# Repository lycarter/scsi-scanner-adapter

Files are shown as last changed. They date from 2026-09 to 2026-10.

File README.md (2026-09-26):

# scsi-scanner-adapter

Bringing a Howtek Scanmaster D4000 drum scanner (1990s, SCSI-2) to modern computers
with custom hardware (USB-C ↔ SCSI) and open scanning software.

## Status

Phase 0: requirements and architecture decisions.

## Phases

| # | Folder | What |
|---|---|---|
| 1 | [`design_docs/1-bus-capture/`](design_docs/1-bus-capture/NOTES.md) | Logic analyzer, passive tap and capture tooling for watching the G4 ↔ scanner bus |
| 2 | [`design_docs/2-reverse-engineering/`](design_docs/2-reverse-engineering/NOTES.md) | Decode the command set and data flow (bus captures + firmware/software analysis) |
| 3 | [`design_docs/3-driver/`](design_docs/3-driver/NOTES.md) | USB-C ↔ SCSI initiator PCB that also works as a listen-only bus sniffer |
| 4 | [`design_docs/4-software/`](design_docs/4-software/NOTES.md) | Driver firmware and host scanning software |

Shared background: [`docs/scanner-facts.md`](docs/scanner-facts.md), [`docs/reference-inventory.md`](docs/reference-inventory.md), [`docs/decisions.md`](docs/decisions.md).

## Known-good baseline

A Power Mac G4 on Mac OS 9, running SilverFast, scans successfully with this scanner.

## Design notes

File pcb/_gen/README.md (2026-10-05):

# Generated schematic sheets

Some sheets are written by Python scripts here rather than drawn by hand, and each script is checked
against KiCad's own netlist. Sheets generated so far: `1-power`, `2-termpwr`, `3-scsi` (with the channel sheets
`scsi_line_bidir` and `scsi_line_in`), `4-rp2350`, `5-io`, `6-usb-hub`, `7-ft232h`.

```
python3 pcb/_gen/build.py            # regenerate, then ERC + netlist check
python3 pcb/_gen/build.py --check    # write nothing; report whether each sheet still matches its script
python3 pcb/_gen/build.py --force    # overwrite hand edits (they are lost)
```

## Footprints

Project footprints (library `scsi-adapter`, `pcb/scsi-adapter.pretty/`) are generated by `footprints.py`, one
function per footprint, with the datasheet land-pattern numbers written into it. Run
`python3 pcb/_gen/footprints.py`. So far: `Texas_RPW0010A_VQFN-HR-10_2x2mm_P0.45mm` (U101/U201),
`TerminalBlock_Kangnex_WJ500V-5.08-2P_1x02_P5.08mm_Horizontal` (J101),
`TE_AMPLIMITE-050_5787082-5_50pos_P1.27mm_Horizontal` (J302), `microSD_SHOUHAN_TF-PUSH_PushPush_CardDetect` (J501), `L_Abracon_AOTA-B201610_2.0x1.6mm_Polarized` (L401, Raspberry Pi's land), `C_0402_1005Metric_Wide` (C402/C403, Raspberry Pi's), `SW_DIP_SPSTx02_Slide_SHOUHAN_2.54-2P-TPGT_W8.8mm_P2.54mm` (SW301). Vendor 3D models live in `pcb/scsi-adapter.3dshapes/`, which is **git-ignored** (vendor copyright). On a fresh
clone, rebuild it from `reference/` with the commands in `docs/sources.md`. Without it KiCad just shows no 3D body.

## How it fits together

- `sheet_N_name.py`: one per sheet. `build(path)` places the parts, wires and notes, and returns the
  *intended* connections as `{(ref, pin): net}`.
- `schgen.py`: the drawing helpers (parts, stubs, power symbols, labels, boxes, notes).
- `netcheck.py`: exports KiCad's netlist and checks that every intended group of pins is exactly one
  net, with nothing extra. This is the real test: a stub that misses a pin, or a wire that touches
  the wrong one, shows up here.
- `semdiff.py`: compares two schematic files by content (parts, texts, wires, labels), ignoring
  UUIDs and KiCad's formatting.

## Editing a generated sheet

Either edit the script and run `build.py`, or edit in KiCad. If you edit in KiCad, `build.py` notices (the sheet
no longer matches the fingerprint in `fingerprints.json` from the last build), refuses to overwrite
it, and lists what differs. Copy those changes into the script (a note's exact
position doesn't matter; near the same spot is fine), then run it again. Running `--check` after an
edit tells you whether the file on disk still matches its script.

Once a script reproduces the sheet on disk exactly, `build.py` does not rewrite that sheet. It only
records the new fingerprint ("matches the script (hand edits folded in)"). KiCad's own file stays as
saved, with the symbol UUIDs the PCB links to, so this is safe to run with the schematic open. A sheet
is rewritten only when the script's output really differs from it.

**Do not let a rewrite happen once the PCB is linked to the sheet.** The scripts number UUIDs with a
counter, so adding or removing one item shifts the UUID of every later item in that sheet, and the PCB
finds each footprint's symbol by UUID. *Update PCB from Schematic* then adds duplicate footprints (this
happened on 2026-10-04). To add a part after layout has started: add it in KiCad and fold it into the
script, or add it to the script and insert only the new items into the saved sheet with fresh UUIDs, so
that `build.py` reports "matches the script" and writes nothing. Run `build.py --check` first; if it
says "script output differs" for a sheet, a plain run would rewrite that sheet.

Needs KiCad 9's `kicad-cli` (`KICAD_CLI` overrides the default macOS path) and the KiCad symbol
libraries (`KICAD_SYMBOL_DIR`).

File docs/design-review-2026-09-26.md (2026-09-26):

# Design review, 2026-09-26

A full design check of the project so far, focused on Phase 3: RP2350 limits, USB, SCSI,
the bootstrapping and programming path, and the numbers against the datasheets. Phases 1, 2
and 4 are covered where they affect the board.

**Triage:** open `docs/design-review.html` in Chrome or Edge and load this file. Each finding gets
*Approve fix*, *Ignore* or a comment, written back here as `- **Owner decision:**` and
`- **Owner comment:**` lines at the end of the finding.

**Ground rules (from the owner):**
- Main topology: **driver board + scanner only**. The G4 with its Adaptec card is on the chain
  only during Phase 1/2 captures, so three-device cases are secondary.
- Accepted decisions are re-opened **only for real errors**, not for preference or cost.
- Trivial doc errors (typos, arithmetic slips) are fixed in place and logged as `[fixed]`.
  Design changes are only logged, never applied.

**Severity:**
- **Blocker:** the board won't work, or something gets damaged.
- **High:** likely needs a respin or a bodge.
- **Med:** spec margin or bring-up risk.
- **Low:** doc issue or nice-to-have.
- **Info:** checked and OK (logged so the check isn't repeated).

There's no schematic yet. The review checks `design_docs/3-driver/NOTES.md`, `design_docs/3-driver/blocks/`,
`design_docs/3-driver/parts-list.md` and the other phase notes, against the datasheets in
`reference/datasheets/` and SCSI-2 rev 10L.

## Summary

Reviewed by one lead plus four parallel reviewers: SCSI front end, power, USB/bootstrap and RP2350/firmware. The raw log has 113 entries. **No Blockers.** One High, which is a single-part swap. Everything else is spec margin, schematic detail, firmware rules or docs. Duplicate entries from different reviewers are merged below; each `Rnnn` is a finding ID in the raw log.

### High

| # | Finding | Fix (suggested) | Log |
|---|---|---|---|
| H1 | **110 Ω terminator resistors (0402, 62.5 mW) run at 100–110 % of rating** on any asserted line; BSY stays asserted for a whole scan | 0603 100 mW, e.g. C2906985 | R006 |

### Med: hardware (settle before or during the schematic)

| # | Finding | Fix (suggested) | Log |
|---|---|---|---|
| M1 | **Bench present enables TERMPWR even when U1 is feeding the board from USB.** A USB port a little higher than the bench supply then carries TERMPWR, even a 500 mA Default port | Drive the enable node from LM66200 ST (open-drain, low while the bench supplies the board) instead of the bench-present FET | R068 |
| M2 | Bench eFuse **EN/UVLO pin passes its 6.5 V absolute maximum above 22.6 V in**; a 24 V adapter is a stated design case | Clamp EN with a ~5.1–5.6 V Zener | R057 |
| M3 | The bench **over-voltage trip (5.56–5.93 V) passes more than 5.5 V** to LM66200, the TPS73701s, FT232H VREGIN and TERMPWR (SCSI max 5.25 V) | Lower OVLO to ~5.5 V worst case, or accept it and document it | R061, R070 |
| M4 | **USB VBUS plug-in ringing can exceed the LM66200's 6 V absolute maximum**; the SMF6.0A only starts clamping at 6.67 V | Damp VBUS (a bulk electrolytic or RC snubber, within the 10 µF rule), or put an eFuse in the USB path | R074 |
| M5 | The TERMPWR eFuse **OVLO pin is driven to 3.3 V**; the recommended range is 0.5–1.5 V (absolute maximum 6.5 V, and TI's text allows GPIO drive) | Probably fine. Optionally clamp the node high level with a divider | R062 |
| M6 | **TERMPWR_OK can read high with TERMPWR absent**: the TCA9555 pull-up can be ~33 kΩ, not 100 kΩ | Lower the divider impedance, or add a pull-down on the node | R066 |
| M7 | **TERMPWR minimum on a 1.5 A USB port is ≈4.23–4.26 V** against SCSI-2's 4.25 V, and the eFuse's rising UVLO can reach 4.47 V | Measure at bring-up; lower the UVLO divider slightly; recommend the bench input for long scans | R069 |
| M8 | The **terminator rail (worst case 2.69 V) is below the SN74LVTH245A's 2.7 V minimum**, and its **output-high resistance is unspecified**, so the "100–132 Ω" and "≥ 2.5 V" claims aren't guaranteed | Centre the rail higher (~2.85 V still passes the 44.8 mA total rule); measure R_out at bring-up | R023, R025, R024 |
| M9 | **3.3 V rail margins**: VREG_AVDD/USB_OTP_VDD need ≥ 3.135 V; the CH334's low-voltage reset trips at up to 3.2 V; the rail's worst case is 3.16–3.44 V | Centre the rail at ~3.35–3.37 V (the CH334's maximum is 3.4 V); add 10 µF at the hub; measure under load | R078, R030 |
| M10 | **PSRAM CS1 pull-up (10 kΩ)** doesn't guarantee the APS6404L's VIH against the RP2350's reset pull-down (36 kΩ min) → 2.58 V vs 2.9 V | 3.3 kΩ (C25890, already on the BOM) | R079 |
| M11 | **FT232H power wiring**: VCCIO on the board 3.3 V rail while VREGIN = 5 V isn't an FTDI-documented configuration | Copy DS Fig. 6.2: VCCD (an output) feeds VCCIO/VPHY/VPLL/EEPROM | R016 |
| M12 | **FT232H support passives are missing**: REF 12 kΩ 1 %, TEST to GND, ferrites, decoupling, EEPROM resistors, RESET RC | Add them per DS Fig. 6.2 (values in the log) | R017 |
| M13 | FT232H outputs **can fight RP2350 outputs on the FT1248 lines** (blank EEPROM, wrong mode, a host bit-mode call) | 33–47 Ω series resistors; firmware checks the mode before driving | R021 |
| M14 | Bench-powered with the host off, the **CH334's D+ pull-up back-drives the cable** (no VBUS detect) | Hold the hub in reset when VBUS is absent (check that this removes the pull-up) | R032 |
| M15 | **Parts list isn't schematic-ready**: most support passives and rail capacitors are missing | Add a per-IC support-passives section | R003, R097 |

### Med: firmware and host (no hardware change)

| # | Finding | Log |
|---|---|---|
| F1 | **macOS: Apple's DriverKit FTDI driver claims 0403:6014**, so D2XX and libusb need root. Conflicts with R5 → owner decision (see Q1) | R052 |
| F2 | **Programming the FT232H EEPROM on macOS**: `ftdi_eeprom` can't set the FT1248 polarity, bit-order or flow-control bits and needs `eeprom_type=0x56` plus root. Suggest FT_PROG once on Windows, then `flash_raw` from the Mac | R044 |
| F3 | **PIO sketches**: `out pins, 9 [8]` won't assemble (max [7]); the setup time before ACK should be ≥ ~100 ns, not 55 ns; there's no phase-change check (a STATUS byte would be ACKed as data); release data in PIO after the last byte; REQ ringing can double-clock; ATN on the last MESSAGE OUT byte (put ATN on `out pins, 10`, since GPIO 27 sits next to DBP) | R007–R011, R100–R102 |
| F4 | **Hard real-time deadlines** (bus set 1.8 µs, bus clear or RST 800 ns, data release 400 ns) need SRAM-resident, top-priority code, ideally on a dedicated core | R014, R103 |
| F5 | **QMI sharing**: run from SRAM (`PICO_COPY_TO_RAM`), keep SCSI DMA in SRAM rings, never write flash during a bus session | R092 |
| F6 | **Sniffer**: can't follow 10 MB/s sync, produces 60–80 MB/s at the edge level, and its two FIFOs can desync → use Phase 1's protocol-level design for long captures | R012, R104 |
| F7 | **1-bit SDIO spill** is marginal at 25 MHz and can't write and drain at the same time; run it at 50 MHz and treat it as "extends the stall buffer" | R108 |

### Low (selection)

These are all in the raw log:
- **Connector:** IDC50 pin 25 / HD50 pin 13 must stay open; ground the RESERVED pins at the chain end (R002).
- **'245 terminator:** tie DIR and the A inputs explicitly (R039). Add a bleed load on the 2.80 V rail, ~1–3 mA (R042, R086).
- **Disabled terminator:** its bus-hold and ~9 pF load show up mid-chain only (R026, R027).
- **RP2350 caps:** the exposed pad is the only GND (R072); a second DVDD 4.7 µF is recommended (R081).
- **LDOs:** the 2.80 V divider impedance (R083); TPS73701 EN pins undefined (R084); LDO thermal tighter than stated (R085).
- **CC reference:** CJ431 is 2.500 V nominal and its margin shrinks to ~6–11 mV, still inside the window (R087). Keep capacitance off its cathode (R088).
- **CH334:** the RESET#/CDP pull-up may enable charging-port mode, so leave it floating (R031).
- **FIFO fallback:** pull SIWU# up (R022).
- **TERMPWR details:**
  - FLT goes low on reverse blocking; don't report that as a fault (R064).
  - Our sink current can exceed 1.0 mA (R065).
  - The TERMPWR_OK divider back-feeds into the unpowered 3.3 V rail (R067).
  - It can pulse on at power-up (R096).
- **Current limits:**
  - The bench eFuse's minimum limit can be exceeded when TERMPWR is at its limit (R095).
  - Power-budget rows are low: RP2350 core ~115 mA, microSD up to 200 mA (R093).
  - A 10 kΩ A-to-C cable reads as "3 A" (R090).
- **Firmware rules:**
  - Watchdog and fail-safe bus release (R004).
  - A "TERMPWR absent" rule (R049).
  - USB suspend current: document it as an accepted deviation (R005).
- **Phase 1:** the "≤ 3 m" claim and stubs from LA leads / Pico taps (R109, R110).
- **Doc slips:** listed at R051, R055 and R099. The trivial ones were fixed (R001, R056).

### Info (verified OK, don't recheck)

- **Pin map and PIO:** the RP2350B QFN-80 pin map, GPIO functions, PIO windows, and side-set/`wait` reach.
- **RP2350 errata:** the E9 mitigation (and E9 is fixed on A3/A4); the full errata sweep.
- **RP2350 support circuit:** core regulator, inductor, crystal, flash, BOOTSEL/RUN.
- **SCSI parts:** FDV301N V_OL, I_DSS, C_oss and C_rss; 74LVC1G17 thresholds at 3.3 V (≤ 1.90 / ≥ 0.93 V interpolated), I_OFF.
- **SCSI bus:** H5VUD5BB on the bus; parity, DB(P) and listen-only; edges and stubs.
- **eFuse settings:** both recompute correctly, apart from the Med items above.
- **Power ICs:** LM66200 ON/ST/soft start; TPS73701 feedback; CC front end and cable cases.
- **Supply ranges:** every 3.3 V part's V_DD maximum. The APS6404L is rated 2.7–3.6 V; LCSC's 2.7–3.3 V is wrong.
- **USB parts:** 93LC56B choice; ABM8 drive level; CH334 pinout and mode; RP2350 USB behind the hub.
- **FT232H:** the FT1248 ↔ FIFO rework map; it can't be bricked by bad EEPROM contents.
- **Bootstrap:** a blank board enumerates the hub, FT232H and RP2350 BOOTSEL with no firmware. UF2 family 0xE48BFF59.
- **Throughput:** the FT1248 4-bit master fits PIO1 at ~12 MB/s MCU-side. PIO, DMA and IRQ budgets fit.

### Bootstrapping verdict

Yes, everything can be programmed on a blank board.
1. On power-up the hub enumerates with no firmware.
2. The RP2350 comes up in ROM BOOTSEL (blank flash) through the hub, and takes UF2 or picotool. SWD via the TC2030 and J-Link is the fallback.
3. The FT232H enumerates with default descriptors and a blank EEPROM, and its EEPROM can be written over USB. Bad contents can't brick it.

The friction is on the host side, not the board: on macOS, Apple's FTDI driver (F1, F2) means root or a Windows machine for the first EEPROM write. On the board side, keep the RP2350 off the FT1248 lines until the FT232H is known to be in FT1248 mode (M13).

### Questions for the second review pass

1. **R5 / macOS (F1):** which path should the host tool use on macOS?
   - root;
   - Apple's `/dev/cu.usbserial` node as the data pipe (needs a bench test);
   - a custom PID (which loses the automatic Windows Update driver).

   Should R5 be reworded to "FTDI's own driver on Windows is OK"?
2. **RP2350 stepping:** which one does JLC fit (A2 vs A3/A4)? It decides whether E9, E10 (UF2 drag-and-drop after a partition table) and E14 apply. `picotool info -a` shows it at bring-up; asking JLC before the order is better.
3. **Sniffer scope:** must the on-board sniffer trace *sync* DATA phases, or is the logic analyzer the tool for those? This decides whether F6 is a firmware item or a non-goal.
4. **Bench OVLO (M3):** lower it so nothing sees more than 5.5 V (tighter margin to a 5.5 V bench setting), or keep 5.73 V and document "set the bench to 5.0–5.3 V"?
5. **Windows machine:** do you have one for FT_PROG (F2)? If not, we plan the macOS `ftdi_eeprom` route with a hand-built image.

### Pre-KiCad resolutions (2026-09-26, from the owner's triage)

The owner triaged every finding in `design-review.html`; the per-finding decisions are in the raw log.
The answers to the follow-up questions, and the resolutions that follow from the notes:

- **R068 (bench role):** the bench must *take over* when it's connected, not just add to USB. The
  LM66200 picks whichever input is higher, so it can't do that. **Replace U1 with a TI TPS2116DRLR
  (C3235557, SOT-583, the same package, extended, $0.40)** in priority mode:
  - VIN1 = bench eFuse output, VIN2 = USB VBUS, MODE tied to VIN1, PR1 divider from VIN1 set
    below the bench eFuse UVLO (datasheet SLVSFG1A §7.6 truth table: PR1 > VREF → VIN1, whatever VIN2 is).
  - The bench eFuse output is either 0 V or ≥ 4.05 V, so "bench present" = "bench in use", and the
    existing bench-present 2N7002 stays the right TERMPWR enable.
  - ST (open-drain, low when VIN1 isn't in use) → expander PWR_SRC.
  - Still one ideal-diode part type (the LM66200 leaves the BOM).
  - Abs max is still 6 V, so the approved R074 VBUS damping stays. There's no mux current limit;
    the bench eFuse limits the bench side.
  - Check at schematic time: the VREF/PR1 tolerance, and the output dip on switchover when the
    bench is removed (§7.5), against the +5V_SYS bulk capacitance.
- **R078 vs R030 (3.3 V setpoint):** keep **3.30 V (47 k / 27 k)**, plus a **DNP 0603 in parallel with
  R2** for rework trim. Raising it to 3.37 V would overshoot the CH334's 3.4 V maximum. Measure at bring-up.
- **R006 (terminator resistors):** each 110 Ω becomes **2 × 220 Ω 0402 in parallel (C25091, basic,
  62.5 mW)**. That's ≤ 35 mW (55 %) each, and it drops the extended 110 Ω part (one fewer loading fee).
- **R066 / R069 (TERMPWR sensing):** **GPIO 46 (ADC6) reads TERMPWR through a divider**. The digital
  TERMPWR_OK input (expander P05) and its 22 k/33 k divider are dropped, which also removes the
  R067 back-feed. GPIO 46 loses its two DNP links: expander INT (firmware polls) and SIWU# in the
  FIFO fallback (SIWU# is tied high instead, R022). Keep TERMPWR UVLO as it is; firmware warns
  from the ADC reading.
- **R111 (bench test):** an FT232H breakout + Pico 2 W test of FT1248 and the macOS
  `/dev/cu.usbserial` path runs **in parallel with the KiCad schematic, and must finish before
  the JLC order**.
- **R034 / R111:** plan for **A4 silicon**, and stay safe on A2 (keep the E9 pull-downs and the
  E14 notes).
- **R013:** the protocol-mode sniffer must also trace DATA phases (per-handshake records).
- **Still undecided, no schematic impact:** R102, R105, R113 (firmware notes), R109, R110 (Phase 1 docs).

**Applied (2026-09-26).** All approved fixes are now in `design_docs/3-driver/NOTES.md` (sections updated in
place, a new "Power mux" section, and "Firmware rules from the design review" after the PIO
sketch), `design_docs/3-driver/parts-list.md` (rewritten), the block pages and diagram sources (rebuilt),
`design_docs/3-driver/USAGE.md` (power, first programming, bring-up checks), `docs/decisions.md` and
`design_docs/4-software/NOTES.md`. Values chosen while applying them (all from JLC's no-fee range):
bench string 510 k / (39 k + 3.9 k) / (150 k + 10 k), OVLO 5.35 V (5.14–5.59 V); terminator
divider (39 k + 5.6 k) / 33 k = 2.831 V; OVLO divider 56 k / 47 k; LDO EN 100 k / 75 k; PR1
100 k / 39 k; ADC divider 100 k / 100 k; CJ431 bias 470 Ω (430 Ω isn't no-fee); bench ILIM 1.5 k
(2.22 A).

**Questions for the second review pass (raised while applying the fixes):**
1. **R059 vs R061 conflict.** Scaling the bench eFuse string to ≥ 1.5 MΩ (< 10 µA reverse
   current, as approved) makes the pins' ±0.1 µA leakage move the OVLO trip by ±0.16 V, so
   the trip spreads to ~5.0–5.7 V, which breaks R061. I kept 510 k (~28 µA at −15 V; meets
   TI's ≥ 350 kΩ footnote, and the new EN Zener takes most of it forward-biased) and
   prioritised over-voltage accuracy. OK, or do you want a different trade?
   **Owner (2026-09-26): OK.**
2. **EN Zener leakage.** The BZT52C5V6's datasheet only bounds leakage at 2 V (≤ 1 µA). At our
   1.42 V it's typically nA, but 1 µA through 510 kΩ would raise UVLO by up to 0.5 V. Bring-up
   measures UVLO; is a datasheet-guaranteed clamp worth a different part?
   **Owner: no; far from anything we care about. If it's a problem, bodge in a different part.**
3. **Power ceiling.** With the corrected RP2350 (115 mA) and SD (200 mA, unverified) maxima, the
   every-maximum ceiling is 1.55 A against a 1.5 A USB port (realistic worst ~1.3 A), and a
   TERMPWR overload plus maximum logic (~2.05 A) can touch the bench eFuse's minimum limit
   (2.0 A). Both are accepted in NOTES; flag if you disagree.
   **Owner: accepted.**

## Raw log (in the order found)

Format: `### Rnnn [Severity] Area: title`, then evidence (with citations), impact, and a
suggested fix.

### R001 [Low] Docs: stale values fixed in place `[fixed]`
- **Evidence:** leftovers from superseded decisions:
  - NOTES R2a still said "resettable fuse".
  - The FDV301N circuit sketch showed a 10 kΩ gate pull-down; it's 4.7 kΩ since 2026-09-25 (E9).
  - The terminator `/OE` sketch and the TERM_EN limitation said 2.85 V; the rail is 2.80 V.
  - Open question 4 still named LM66200 U2 as the TERMPWR part.
  - The power budget still had a "TERMPWR polyfuse" requirement.
  - The FT232H section said AN_167 was "not yet downloaded".
  - `blocks/1-power.md` said "2.85 V regulator" and listed the TERM_EN default and resistor values as open. Both are decided.
  - `USAGE.md` called the expander "optional", but it's fitted as standard.
- **Fix:** edited in place (NOTES, `blocks/1-power.md`, `USAGE.md`). Historical log lines and superseded rationale sections were left as history.
- **Confidence:** high.
- **Owner decision:** approved (2026-09-26)

### R002 [Low] SCSI connector: RESERVED and OPEN pins need explicit handling in the schematic
- **Evidence:** SCSI-2 rev 10L Table 2 (SE, A cable):
  - IDC50 (set 1) pin 25 / HD50 (set 2) pin 13 is **OPEN**, not ground.
  - Pins 24 and 28 (HD50 37 and 39) are **RESERVED**.
  - Several even pins are **GROUND**, not signals: 20, 22, 30, 34 (HD50 35, 36, 40, 42).
  - §5.4.4: RESERVED lines "shall be connected to ground in the bus terminator assemblies or in the end devices", and "should be open in the other SCSI devices".
- **Impact:** NOTES describes the pinout as "odd pins ground, even pins signal", which is almost right. If pin 25 is grounded with the rest of the odd pins, a reversed cable (possible on the HD50 side only through a bad cable) shorts TERMPWR to ground. The eFuse survives that, but the bus is dead. The RESERVED lines should be grounded when our board is an end device, which is the main topology.
- **Fix:** in the schematic, leave IDC50 pin 25 and HD50 pin 13 unconnected. Tie the RESERVED pins to GND through a 0 Ω link each (fit for end-of-chain, remove if the board ever sits mid-chain), or simply ground them. Wire both connectors from Table 2 by signal name, as NOTES already says.
- **Confidence:** high (read directly from the standard).
- **Owner decision:** approved (2026-09-26)

### R003 [Med] Parts list: not yet "schematic-ready"; many support passives are missing
- **Evidence:** `parts-list.md` calls itself "schematic-ready", but it has no rows for:
  - FT232H: REF resistor, per-pin decoupling, any VPHY/VPLL filtering, EEPROM pull-ups.
  - CH334P: VDD33/V5 decoupling.
  - TPS73701 ×2: input and output capacitors. The datasheet has minimum C_OUT and ESR guidance.
  - TPS259470A ×2: IN/OUT capacitors.
  - Bulk capacitance on +5V_SYS, TERMPWR and the 2.80 V rail.
  - Decoupling for the TCA9555, LM393, 3 × LVTH245 and W25Q128 (the MCU table has "+ flash"; check it's counted once).
  - microSD: decoupling and bulk (card insertion inrush).
  - USB-C shell/shield connection.
  - Test points.
  Some of these are covered in the agents' sections below (FT232H, LDOs).
- **Impact:** the schematic step turns into more part selection. A missed REF resistor or LDO output cap stops the board working.
- **Fix:** at schematic time, add a "support passives" section per IC, checked against each datasheet's typical application. Prefer basic 100 nF/1 µF/4.7 µF/10 µF parts that are already on the list.
- **Confidence:** high that the rows are missing; the exact values are in the per-area findings.
- **Owner decision:** approved (2026-09-26)

### R004 [Low] Error states: firmware must fail safe on the bus (watchdog)
- **Evidence:** ATN, BSY and SEL are driven by the CPU (SIO), and data/ACK by PIO. A firmware hang (hard fault, deadlock, a stall on flash erase) with BSY or data gates asserted holds the SCSI bus busy until the board resets. The scanner would then time out or wait for ever. After a watchdog reset or a RUN reset, all pads return to their reset state (pull-down, isolated), and the 4.7 kΩ gate pull-downs release every line.
- **Impact:** a hung board wedges the scanner mid-command, which may need a scanner power-cycle.
- **Fix (firmware):** enable the RP2350 watchdog in the SCSI engine, and have the host protocol expose a "bus reset" command (assert RST ≥ 25 µs, SCSI-2 reset hold time) for recovery. Hard-fault handler: release all 14 gates first.
- **Confidence:** high (design logic).
- **Owner decision:** approved (2026-09-26)

### R005 [Low] Error states: USB suspend current
- **Evidence:** USB 2.0 §7.2.3 limits a suspended device to 2.5 mA. This board draws ~0.2 A of logic current (NOTES power budget) and keeps TERMPWR up in suspend. This is the same class of deviation as the accepted "100 mA before configuration" one.
- **Impact:** in practice, hosts don't police it. A laptop going to sleep with the board attached keeps powering it (or cuts VBUS). The scanner session is lost either way.
- **Fix:** document it as an accepted deviation next to the 100 mA one. Optionally, firmware can gate LEDs and the SD card in suspend. No hardware change.
- **Confidence:** high on the rule; the impact is benign.
- **Owner decision:** approved (2026-09-26)

### R006 [High] SCSI: 110 Ω terminator resistors in 0402 run at or above their 62.5 mW rating
- **Evidence:** parts-list row "18 × 110 Ω 1 % 0402 (FOJAN)", C2909312 = FRC0402F1100TS, **62.5 mW** (pcbparts/JLC record). An asserted line puts (V_term − V_OL) across the resistor: nominal (2.81 − 0.18 V [FDV301N 3.8 Ω typ × 48 mA]) → 2.63²/110 = **63 mW**; worst (2.93 V LDO max − 0.18) → 2.75²/108.9 = **69 mW** (110 %). BSY is held asserted for a whole connection (a scan lasts minutes), RST for ≥ 25 µs, and a data line can sit asserted indefinitely between bytes. Thick-film 0402 ratings are also derated above ~70 °C.
- **Impact:** resistors run at 100–110 % of rating continuously on the busy lines; drift/early failure, and the resistor tolerance that the 22.4 mA budget depends on is no longer guaranteed.
- **Fix:** use 0603 (100 mW): e.g. FOJAN FRC0603F1100TS **C2906985** (143k stock, extended, same loading-fee count as the 0402) or UNI-ROYAL C22781. Update parts-list and NOTES.
- **Confidence:** high (arithmetic + part record). Real V_OL varies, but the nominal case alone is at the rating.
- **Owner comment:** Rather than use an extended part, use basic parts in parallel to spread the power around and keep each individual component under its limits.

### R007 [Med] SCSI: PIO data_out `out pins, 9 [8]` does not assemble with `.side_set 1 opt`
- **Evidence:** the PIO delay/side-set field is 5 bits. `.side_set 1 opt` uses 1 side-set bit + 1 enable bit, leaving 3 bits of delay, so the maximum is **[7]** (RP2350 datasheet §11.4 "Delay/side-set" field; same as RP2040). NOTES "PIO0 sketch" uses `[8]`.
- **Impact:** pioasm error. If "fixed" by just trimming to [7], the data→ACK setup drops to 8 cycles = 53 ns at 150 MHz, under the 55 ns (deskew 45 + cable skew 10) target (see next finding).
- **Fix:** either use non-optional `.side_set 1` (4 delay bits, max [15]) and put `side 0/1` on every instruction, or add a `nop [n]`, or run the SM at a clock divider. Choose the delay after reading the rising-edge finding below.
- **Confidence:** high.
- **Owner comment:** approved. I think the `nop [n]` makes the most sense to me, but we can figure it out in firmware later.

### R008 [Med] SCSI: data_out deskew margin ignores slow release edges and FET turn-off delay; make it ≥ ~100 ns
- **Evidence:** SCSI-2 Table 7 (§5.7): **deskew delay = 45 ns** (not 55 ns: 55 ns is deskew + cable skew 10 ns). §6.1.5.1 async DATA OUT: drive DB, wait ≥ deskew + cable skew (55 ns), then assert ACK, measured at our connector (§5.7). The sketch gives 9 cycles = 60 ns from `out` to the ACK side-set, all of it inside the chip. On the wire, ACK assertion is a FET **turn-on** (t_d(on) typ 3.2 ns, t_r 6 ns; FDV301N DS switching table, at 4.5 V / 50 Ω), while a data bit going 1→0 is a FET **turn-off**: the gate (≈15 pF C_iss at low V_DS, Fig. 8) must discharge from ~3.2 V through 100 Ω + pad (~150 Ω) past the Miller plateau (≈2.1 V, Fig. 7; Q_gd 0.07 nC ≈ 5 ns at ~14 mA), then the line rises through the terminators and the cable (incident step to ~2.4–2.6 V at our end, plus lumped C ≈ 18 pF × ~50 Ω). Estimate ≈ 15–25 ns for a released bit vs ≈ 5–10 ns for ACK: ~10–15 ns of the 60 ns is eaten, leaving ~45–50 ns (< 55 ns). Unverified estimate; no bench data.
- **Impact:** marginal setup on the target side during DATA OUT / COMMAND / MESSAGE OUT; a WD33C93A usually samples later, so it will probably work, but it isn't compliant by design.
- **Fix:** delay ≥ 15 cycles (100 ns) between `out` and the ACK assertion. Async throughput cost is negligible (the scanner is the bottleneck). Verify on the scope: DBx release crossing 2.0 V vs ACK crossing 0.8 V at the connector.
- **Confidence:** med (timing estimate from typical figures).
- **Owner decision:** approved (2026-09-26)

### R009 [Med] SCSI: data_out leaves the last byte on the bus; release it in PIO, not firmware (400 ns data release delay)
- **Evidence:** SCSI-2 §6.1.10(b): when the target turns the bus around (I/O false→true, e.g. COMMAND → DATA IN/STATUS), "the initiator shall release the DATA BUS no later than a data release delay [400 ns, Table 7] after the transition of the I/O signal to true." The data_out sketch loops back to `pull block side 0`, so after the last byte DB0–7/P stay driven until firmware notices. NOTES says "Firmware must release all 9 data gates within the 400 ns". A Cortex-M33 IRQ (12-cycle entry ≈ 80 ns) can do it only if the ISR and its data are in SRAM, nothing higher-priority is running, and no XIP cache miss happens (a miss on QSPI flash/PSRAM costs ~0.5–1 µs).
- **Impact:** a bus fight with the target's first DATA IN / STATUS byte (target starts driving ≥ 800 ns after I/O; our open-drain drivers pull its 1-bits low → wrong status/data/parity errors). Open-drain means no damage, only corruption.
- **Fix:** §6.1.5.1 allows the initiator to "change or release the DB signals" once REQ is false. Add `mov pins, null` (release all 9) with ACK negation after `wait 0 pin 16`, so the bus is always released between bytes. Costs one instruction; removes the firmware deadline completely.
- **Confidence:** high on the rule; med on how hard the firmware deadline would be.
- **Owner decision:** approved (2026-09-26)

### R010 [Med] SCSI: last MESSAGE OUT byte: ATN (CPU-owned) can't be negated in the REQ-true/ACK-false window
- **Evidence:** SCSI-2 §6.2.1: the initiator "shall not negate the ATN signal while the ACK signal is asserted during a MESSAGE OUT phase. Normally, the initiator negates the ATN signal while the REQ signal is true and the ACK signal is false during the last REQ/ACK handshake." With the data_out SM, that window is only the ~60–100 ns between REQ detection and ACK assertion. NOTES "Who drives what" gives ATN to the CPU (SIO).
- **Impact:** firmware can't hit the window; negating ATN earlier (before the last REQ) is allowed by the letter but some targets then leave MESSAGE OUT early (vendor behaviour, the WD33C93A's is unknown); negating later (after ACK negated) is legal only if ACK is false, but then the target may request another message byte. Multi-byte messages (IDENTIFY + SDTR/EXTENDED, ABORT sequences) are where this bites.
- **Fix (firmware/PIO only, no hardware change):** ATN is GPIO 27, right after DBP (GPIO 26), so `OUT_BASE = 18`, `out pins, 10` can carry ATN as bit 9 of each FIFO word: firmware queues the last message byte with ATN = 0 and PIO drops it at the right moment. That means ATN's funcsel is PIO0 during MESSAGE OUT (or always). Alternatively do MESSAGE OUT byte-by-byte from the CPU (slow but only a few bytes).
- **Confidence:** high on the rule; the ATN bit-9 trick relies on the accepted pin map (verified: outputs 18–26 data, 27 ATN).
- **Owner decision:** approved (2026-09-26)

### R011 [Med] SCSI: data_in / data_out can double-clock on REQ ringing; add a minimum ACK-assert time before `wait 0 pin 16`
- **Evidence:** data_in: `in pins, 9 side 1` then immediately `wait 0 pin 16`. data_out: `wait 0 pin 16 side 1` right after asserting ACK. The PIO input path has a 2-flop synchronizer (≈13 ns at 150 MHz). REQ's assertion is a fast falling edge from the target's open-collector/three-state driver into a ribbon; ringback above the receiver's VT+ (≤ ~1.9 V, 74LVC1G17 Table 8, interpolated) for even one sample is enough to satisfy `wait 0` and release ACK, and the next `wait 1` then re-samples the same byte. The 1G17 hysteresis (≥ 0.31 V at 3.0 V, 0.25 V at 125 °C; Table 8) helps but doesn't bound ringing amplitude. This is the classic SCSI "double REQ" failure.
- **Impact:** duplicated or dropped bytes in DATA IN, silently corrupt scan data (no parity error, because the byte itself is valid).
- **Fix:** hold ACK asserted for a minimum time (e.g. `[7]`/`nop [n]` ≈ 50–100 ns) before looking for REQ negation, and/or require REQ negated for 2 consecutive samples (`wait 0 pin 16` followed by `jmp pin` re-check). Costs 1–2 slots, negligible throughput. Also scope REQ at the connector at bring-up.
- **Confidence:** med (depends on real ringing; cheap to guard).
- **Owner decision:** approved (2026-09-26)

### R012 [Med] SCSI: the sniff loop can't follow 10 MB/s fast-sync (and is marginal at 5 MB/s)
- **Evidence:** sniff = 3-instruction poll (20 ns at 150 MHz) + 4-instruction emit (mov y / mov isr / push / irq) → after each change the SM is blind for ≈ 7 cycles ≈ **47 ns**. SCSI-2 §5.8 / Table 7 fast sync: transfer period ≥ 100 ns, fast assertion/negation ≥ 30 ns, fast hold 10 ns, fast deskew 20 ns. So in each 100 ns period there are ≥ 3 distinct bus states ~10–30 ns apart (data change, REQ assert, REQ negate; plus ACK pulses offset by up to the REQ/ACK offset). Edges closer than ~47 ns after an event are merged or missed, and any state shorter than 20 ns can be missed outright. At 5 MB/s sync (200 ns period, 90 ns assertion/negation) it mostly works but data changes within 45 ns of REQ (hold time 45 ns) can still merge. Also: the two SMs (sniff + stamp) push to separate FIFOs with `push noblock`; if one FIFO overflows and the other doesn't, samples and stamps silently desynchronize. scanner-facts: the D4000's WD33C93A supports sync, rate unknown; the sibling 7500 uses up to 10 MHz.
- **Impact:** listen-only captures of the G4/Adaptec session will be wrong exactly in the DATA IN phase, if it negotiates fast sync.
- **Fix:** keep the Digital Discovery as the reference for sync phases; or make the sniffer loop 2 instructions with the timestamp embedded (e.g. count loop iterations in the same SM and push `{state, delta}` together, one FIFO, one DMA); or detect SDTR in the capture and flag data phases as "sync, not traced". Log the negotiated SDTR from the MESSAGE phases, which the sniffer does catch (async).
- **Confidence:** high on the arithmetic; whether it matters depends on what the Adaptec negotiates (Phase 1 will show).
- **Owner decision:** approved (2026-09-26)

### R013 [Question] SCSI: is the on-board sniffer required to trace sync DATA phases, or is the LA the tool for that?
- **Evidence:** see previous finding. R4 (listen-only) doesn't say which transfer modes it must cover.
- **Impact:** decides whether the sniff program needs redesign now or can stay "async only".
- **Fix:** owner to decide; I'd write "async + messages; sync data via the LA" into R4.
- **Confidence:** —
- **Owner decision:** approved (2026-09-26)
- **Owner comment:** in protocol mode it should also trace DATA

### R014 [Med] SCSI: CPU-side hard deadlines (bus set 1.8 µs, bus clear 800 ns, RST response 800 ns) need SRAM-resident, IRQ-masked code; write it down as a firmware rule
- **Evidence (SCSI-2 Table 7, §5.7):** arbitration delay ≥ 2.4 µs; bus free delay ≥ 800 ns; **bus set delay ≤ 1.8 µs** (assert BSY + ID after detecting BUS FREE); bus settle 400 ns (BUS FREE = BSY and SEL false for ≥ 400 ns, §6.1.1); **bus clear delay ≤ 800 ns** after BUS FREE detected / SEL seen during arbitration / RST true (and ≤ 1200 ns from BSY+SEL false, §5.7.3); data release 400 ns; reset hold ≥ 25 µs; selection abort ≤ 200 µs; selection time-out 250 ms (recommended); deskew 45 ns; cable skew 10 ns; hold 45 ns; assertion/negation (sync) ≥ 90 ns. So arbitration has a window of [800 ns, 1.8 µs] after BUS FREE detection, and the losing/reset paths have an 800 ns ceiling. BSY, SEL, ATN, RST are on SIO (CPU).
- **Impact:** a flash XIP cache miss (QSPI at ~≤ 75 MHz: tens of cycles per line, ~0.5–1 µs worst with PSRAM contention on the same QMI) or a USB/FT1248/DMA IRQ preempting the arbitration loop can blow the 1.8 µs / 800 ns limits. In the main topology (only us + scanner) arbitration loss only happens if the D4000 reselects (it disconnects? unknown); RST is only asserted by us. In the G4 capture topology we're listen-only. So the practical risk is low, but the requirement should be explicit.
- **Fix (firmware rule, NOTES):** arbitration/selection/bus-free/RST handlers `__not_in_flash` (SRAM), run with interrupts masked (or at the highest NVIC priority on the core that owns SCSI, with USB on the other core), no PSRAM access inside. For RST-true and SEL-during-arbitration, consider a small PIO watcher: `wait 1 pin RST` → `irq` so the CPU is told within ~13 ns, and let the data_out SM release its own pins (`mov pins, null`) on that IRQ. Also filter RST glitches per §6.2.2 NOTE 30 (e.g. ≥ 2 samples).
- **Confidence:** high on the numbers; latency figures for XIP misses are typical, not measured.
- **Owner decision:** approved (2026-09-26)

### R015 [Info] SCSI: PIO data_in handshake order and REQ index checked
- **Evidence:** `wait 1 pin 16` (REQ, IN_BASE 0, GPIO 16 per the pin map) → `in pins, 9` (DB0–7, DBP on GPIO 0–8) with ACK asserted on the same cycle → `wait 0 pin 16` → ACK negated at the top of the loop. Matches §6.1.5.1 (read after REQ true, then ACK; negate ACK after REQ false). Target provides deskew before REQ, so sampling ~13 ns (sync) + ≤ 5.5 ns receiver skew (1G17 tpd 0.7–5.5 ns, Table 9) after REQ is fine. INOVER-invert gives 1 = asserted for both data and REQ. Side-set ACK = GPIO 29 is inside PIO0's window. `.side_set 1 opt` delay limit (≤ 7) is only an issue in data_out.
- **Confidence:** high.

### R016 [Med] USB: FT232H VCCIO on the board 3.3 V rail while VREGIN = 5 V is not an FTDI-documented configuration; follow the datasheet (VCCD feeds VCCIO/VPHY/VPLL/EEPROM)
- **Evidence:** DS_FT232H v2.0 Table 3.1 and §6.1/§6.2 (pp. 10, 43–44): with VREGIN = 5 V, pin 39 **VCCD becomes an output** and "supplies 3.3V to the VCCIOs, VPLL and VPHY". Both 5 V examples (Fig. 6.1 bus-powered, Fig. 6.2 self-powered) tie VCCIO (12, 24, 46), VPHY (3) and VPLL (8) to the VCCD net, and power the 93LC56B from VCCIO. §7.1 (p. 47): the EEPROM must be "powered from the same net as the core supply". Only Fig. 6.3 (VREGIN = 3.3 V) feeds VCCIO from an external 3.3 V LDO, and then VCCD is an *input*. NOTES "Supply choices" says "VCCIO stays on the 3.3 V rail … Check the VPHY/VPLL wiring … at schematic time."
- **Impact:** the planned mix (VREGIN = 5 V, VCCIO from the board LDO) isn't shown anywhere by FTDI. The real danger is at schematic time: if VCCD (an LDO *output* in this mode) gets tied to the board 3.3 V net, two regulators fight. If VCCIO is on the board rail but VPHY/VPLL/EEPROM on VCCD, the I/O ring and the core-side 3.3 V come from different sources with unspecified sequencing.
- **Fix (suggestion):** copy Fig. 6.2 exactly: VREGIN = +5V_SYS (4.7 µF + 0.1 µF); VCCD = local "FT_3V3" net (4.7 µF + 0.1 µF), which feeds VCCIO ×3 (0.1 µF each), VPHY and VPLL each through a 600 Ω@100 MHz / 0.5 A ferrite + 0.1 µF (4.7 µF pads DNP), and the 93LC56B VCC. **Never connect VCCD to the board 3.3 V.** The FT232H's I/O is then at its own 3.3 V, which talks to the RP2350's 3.3 V fine (same 5 V source, so no sequencing problem; FT232H inputs are 5 V tolerant). The FT232H's ~70 mA then comes off 5 V instead of the board LDO, a slight power-budget improvement.
- **Confidence:** high on what the datasheet shows; medium that the external-VCCIO mix would actually misbehave (not stated as forbidden, just never shown).
- **Owner decision:** approved (2026-09-26)

### R017 [Med] USB: FT232H support passives (values to add to the parts list, per DS Fig. 6.2)
- **Evidence:** DS_FT232H v2.0 Table 3.2 (p. 10): **REF = 12 kΩ 1 % to GND** ("Current reference"), **TEST (pin 42) must be connected to GND**. Fig. 6.2 (p. 44): RESET# = 10 kΩ to 3.3 V + **10 nF to GND**; VCCA (37) and VCORE (38) = 0.1 µF each, "Should not be used" (DS Table 3.1); crystal caps; EEPROM: DO → **2.2 kΩ** (text) / 2 kΩ (figure) → DI/EEDATA, **10 kΩ pull-up on DO** to VCCIO (Table 3.3 "for correct operation"); CS/CLK pull-ups are N.F. in the figure. ACBUS7/PWRSAV# (pin 31) left open is fine as long as "Suspend on ACBus7 Low" stays disabled (its default is TriSt-PD, so enabling that option with the pin open would hold the chip in suspend; DS pp. 10, 48). None of these rows are in `parts-list.md` §4 (the existing [Med] "Parts list" finding lists them generically).
- **Impact:** a missing REF resistor or TEST left floating gives a dead or flaky HS PHY.
- **Fix:** add: 1 × 12 kΩ 1 % 0402 (JLC basic C25752, unverified C-number), 2 × ferrite 600 Ω/0.5 A 0603, 2 × 4.7 µF (VREGIN, VCCD) + 2 DNP pads, ~8 × 100 nF, 1 × 10 nF (RESET#), 1 × 2.2 kΩ, 1 × 10 kΩ. Keep "Suspend on ACBus7 Low" off in the EEPROM.
- **Confidence:** high (datasheet values).
- **Owner decision:** approved (2026-09-26)

### R018 [Info] USB: 93LC56BT-I/OT (C190271) is the right EEPROM
- **Evidence:** DS_FT232H §7.1 (p. 47): "The EEPROM must be 16 bits wide (93LC56B)". 93LC56B.pdf p. 1: "128 x 16-bit Organization 'B' Version (no ORG)"; SOT-23-6 ("OT") exists for A/B only, ORG is NC. JLC: C190271 = 93LC56BT-I/OT, SOT-23-6, 2.5–5.5 V, 11,203 in stock (pcbparts, 2026-09-26). FTDI's own Fig. 6.2 uses "93LC56BT-I/OT". Pinout (SOT-23-6): 1 DO, 2 VSS, 3 DI, 4 CLK, 5 CS, 6 VCC (matches the FTDI figure).
- **Confidence:** high.

### R019 [Info] USB: ABM8-272-T3 on the FT232H and CH334 oscillators: drive level is inside the crystal's 200 µW
- **Evidence:** ABM8-272-T3.pdf p. 1: CL 10 pF, ESR ≤ 50 Ω, C0 ≤ 3 pF, drive level 10–200 µW. Worst case with a full 3.3 V swing on the crystal: I_rms ≈ 2π·12 MHz·(10+3) pF·1.17 V ≈ 1.1 mA, P = I²·ESR ≈ 65 µW at 50 Ω. So even without a series resistor (FTDI's Fig. 6.4 has none) it stays under 200 µW. FT232H: 2 × 15 pF gives ≈ 7.5 + ~3 pF stray ≈ 10 pF, matching CL; FTDI's 27 pF is only an example (§6.3). The ±30 ppm in DS Table 6.1 is for an external oscillator input; USB HS allows ±500 ppm. The CH334 English reference schematic (V2.5 §6.1, p. 27) shows the crystal with no load caps, consistent with "DNP" pads.
- **Confidence:** medium-high (the estimate is an upper bound; neither chip specifies its oscillator gain).
  (Checked afterwards: C25752 = UNI-ROYAL 12 kΩ ±1 % 0402, JLC **basic**, 1.17 M stock, pcbparts 2026-09-26.)

### R020 [Info] USB: FT1248 ↔ 245 FIFO pin mapping and directions in `5-rp2350-pinout.md` are correct
- **Evidence:** DS_FT232H Table 3.13 (p. 17): MIOSIO0–7 = pins 13–20 (I/O), SCLK = 21 (in), SS_n = 25 (in), MISO = 26 (out). Table 3.8 (pp. 14–15): D0–7 = 13–20, RXF# = 21 (out), TXE# = 25 (out), RD# = 26 (in), WR# = 27 (in), SIWU# = 28 (in). So after the swap GPIO 41 and 42 turn from outputs into inputs and GPIO 43 from input into output, exactly as the page says. AN_167 §2.2 (p. 3): "Each pin of the FT232H has an internal pull up … no external pullup or down is required"; §2.1: "Unused MIOSIO lines may be left unterminated", so MIOSIO4–7 on DNP stubs are fine for 4-bit bus-width decoding (DS §4.6.1).
- AN_167 facts for the firmware: SCLK ≤ 30 MHz (§1, §2.2); only **CPHA = 1** is supported, CPOL selectable in EEPROM (§8, Table 2); bus width is chosen **per transaction by the command phase** (low on MIOSIO[3:2] = 4-bit; §4, Fig. 4.1), not by the EEPROM; commands 0x0 write, 0x1 read, 0x2/0x3 modem status, 0x4 write-buffer flush (§6, Table 1); per byte, MISO = ACK/NAK, and on NAK the master must end the transfer by raising SS_n and retry later (§5.5); with SS_n high the FT232H **drives** MIOSIO0 (= TXE#) and MISO (= RXF#) unless "no flow control during SS_n inactive" is set in the EEPROM (§3, §5.6). The master must release MIOSIO before raising SS_n after a write (§5.1). Note AN_167 §5.3 says the 4-bit data phase "requires 3 clock cycles", but Fig. 5.8/5.9 show 2 per byte; the NOTES' 15 MB/s at 30 MHz assumes 2.
- **Confidence:** high.

### R021 [Med] USB: FT232H outputs can fight RP2350 outputs on the FT1248 lines (blank EEPROM, wrong mode, or a host bit-mode call)
- **Evidence:** blank/absent EEPROM = UART mode (DS §7.1, p. 47). In UART mode ADBUS0 (pin 13 = MIOSIO0 = GPIO 32) is TXD **output**, ADBUS2 (pin 15 = GPIO 34) is RTS# **output**, ADBUS4 (pin 17) DTR# output (DS Table 3.4, p. 11); ACBUS0–2 (SCLK/SS_n/MISO pins) default to TriSt-PU inputs (Table 7.1). In FT1248 mode the FT232H also drives MIOSIO0 whenever SS_n is high (AN_167 §3). Any host program can also switch ADBUS to outputs at any time with FT_SetBitMode (MPSSE/bit-bang). GPIO 32/34 are driven by the RP2350 during command/write phases. There are no series resistors on these nets.
- **Impact:** push-pull contention (tens of mA per pin) at first power-up with the blank EEPROM if firmware starts polling the FT1248 link, during bring-up with a mis-programmed EEPROM (UART or FIFO while firmware speaks FT1248: in FIFO mode GPIO 41/42 would drive RXF#/TXE#), or after the fallback rework. Unlikely to destroy either chip quickly, but it can latch confusing states and it stresses both.
- **Fix (suggestions):** (1) 33–47 Ω series resistors on the 7 FT1248 nets at the RP2350 end (also damps ringing at 25 MHz; with the FIFO fallback they stay useful); (2) firmware: only drive MIOSIO after checking the FT232H is in FT1248 mode (e.g. MISO/MIOSIO0 behave as RXF#/TXE# while SS_n is high, or the host confirms over the CDC console), and keep the PIO pins as inputs otherwise; (3) host tool: never call FT_SetBitMode except reset (0x00).
- **Confidence:** high on the pin behaviour; medium on the severity.
- **Owner decision:** approved (2026-09-26)

### R022 [Low] USB: FIFO fallback: SIWU# (FT232H pin 28) must not float when its optional link is unfitted
- **Evidence:** DS Table 3.8 (p. 15): SIWU# "Tie this pin to VCCIO if not used." The 245-FIFO fallback makes the GPIO 46 → pin 28 link optional (page 5). ACBUS4 has an internal ~75 kΩ pull-up only as a TriSt-PU default in *other* modes (DS p. 11 note **); in FIFO mode the pin is SIWU# and FTDI asks for a tie. NOTES says "with a pull-up/down as the FT232H needs for unused inputs", but no part is listed.
- **Fix:** fit a 10 kΩ pull-up from pin 28 to the FT232H VCCIO (harmless in FT1248 mode). WR# (pin 27) is always linked in FIFO mode, so it needs none; a 10 kΩ pull-up there too keeps WR# idle during the swap.
- **Confidence:** high.
- **Owner decision:** approved (2026-09-26)

### R023 [Med] SCSI: terminator rail can fall below the SN74LVTH245A's 2.7 V minimum VCC, and the ≥ 2.5 V released level is then not guaranteed
- **Evidence:** SN74LVTH245A (SCBS130T p.3, recommended operating conditions): **VCC 2.7–3.6 V**. TPS73701 worst case with 20 k/15 k 1 %: 2.809 V × (1 ± 3 % legacy-silicon accuracy, TPS737 DS §6.5 "over VIN, IOUT, T", 10 mA ≤ IOUT ≤ 1 A) ± 1.1 % divider → **2.69–2.93 V**. At the low end the LVTH is outside its rated range, so none of its table values apply. Even taking them at face value, V_OH = VCC − 0.2 V at I_OH = −100 µA (p.4) → 2.69 − 0.2 = **2.49 V**, 10 mV under SCSI-2 §5.4.1(b)(4) "released lines ≥ 2.5 V". Also note the TPS737 accuracy is specified only for I_OUT ≥ 10 mA; the idle bus draws ~0.7 mA (3 × I_CC 0.19 mA + 80 µA divider).
- **Impact:** a spec-guarantee gap, not a likely field failure: typical LVTH V_OH at 100 µA is within tens of mV of VCC, and the far terminator also holds released lines up. Worth knowing because (b)(4) must hold "with any legal configuration".
- **Fix (options, owner's choice):** (a) set the rail to ~2.85 V (e.g. 20 k / 14.7 k → 2.842 V, worst ~2.72–2.96 V): the (b)(3) current bound still holds because it's 44.8 mA for *both* terminators together (see Info below) and the LVTH output drop reduces our share; (b) keep 2.80 V and accept, recording it as a known datasheet gap; (c) add a ~5–10 mA bleed on the rail (it was already suggested in NOTES "Terminator LDO") so the TPS737 runs inside its ≥ 10 mA accuracy spec.
- **Confidence:** high on the numbers; low on practical impact.
- **Owner decision:** approved (2026-09-26)

### R024 [Info] SCSI: SCSI-2 §5.4.1(b)(3) is a 44.8 mA two-terminator total, not a per-terminator 22.4 mA rule
- **Evidence:** §5.4.1 b) 3): "The current available to any signal line driver shall not exceed 48 mA when the driver asserts the line and pulls it to 0,5 V d.c. Only 44,8 mA of this current shall be available from the two terminators." NOTES "Terminator LDO" reads it as "each terminator ≤ 22.4 mA". Ours: (2.93 − 0.5)/108.9 Ω = 22.3 mA max (ignoring LVTH output drop), so it satisfies either reading. With a typical 2.85 V/110 Ω external active terminator at the far end (21.4 mA) the total is ≤ 43.7 mA.
- **Fix:** doc wording only (Low). Useful if the rail is ever raised (previous finding).
- **Confidence:** high.

### R025 [Med] SCSI: LVTH output-high resistance isn't specified; "110 Ω + R_out lands in 100–132 Ω" is unverified
- **Evidence:** §5.4.1 b) 1): "each supply a characteristic impedance between 100 ohms and 132 ohms". SN74LVTH245A gives only: V_OH ≥ 2.4 V at −8 mA with VCC 2.7 V (implied ≤ 37 Ω incl. offset), and ≥ 2.0 V at −32 mA with VCC 3.0 V (≤ 31 Ω) (p.4). There is no V_OH figure at ~−21 mA and VCC 2.7–2.9 V. With a bounding R_out of 30 Ω the terminator is **~140 Ω, outside 132 Ω**; with a plausible typical 5–15 Ω it's 115–125 Ω (inside). BlueSCSI v2 uses the same topology (LVT245 + 110 Ω) successfully, which suggests the typical is fine.
- **Impact:** only the bounding case violates; typical is compliant. Also, a larger R_out lowers the sink current and raises nothing dangerous.
- **Fix:** bench-measure one line: V at 110 Ω node open vs loaded with ~21 mA (asserted line) → R_out; log it in scanner-facts/NOTES. If > 22 Ω, drop the resistor to 100 Ω (and recheck the 22.4 mA share: (2.93−0.5)/(100+R_out)). No design change now.
- **Confidence:** med.
- **Owner decision:** approved (2026-09-26)

### R026 [Low] SCSI: a disabled terminator is not "LVT Ioff": the LVTH is still powered from bus TERMPWR, so its B-port bus-hold keepers load each line through 110 Ω
- **Evidence:** the LDO runs from TERMPWR, so whenever *any* device supplies TERMPWR the '245s have VCC ≈ 2.8 V, even with our board off (blocks/1-power.md notes this). With `/OE` high (DIP 00, mid-chain) the B pins are inputs with **bus hold** ("H"; SCBS130T p.1 and p.2 "Active bus-hold circuitry"). I_I(hold): ≥ +75 µA at 0.8 V and ≤ −75 µA at 2.0 V (VCC 3 V); max overdrive **+500 / −750 µA** (VCC 3.6 V) (p.4). Ioff (±100 µA) applies only at VCC = 0, which only happens when nobody supplies TERMPWR (then the bus is dead anyway). NOTES "Termination" says "with `/OE` high or the chip unpowered, the outputs go high-Z (LVT Ioff), so a powered-off board doesn't load the bus".
- **Impact:** compared with SCSI-2 §5.4.1.2 (I_IL 0 to −0.4 mA at 0.5 V; I_IH 0 to +0.1 mA at 2.7 V), the keeper current has the *wrong sign* (it sinks at 0.5 V, sources near 2.7 V) and, during a transition, up to 0.5–0.75 mA peak; through 110 Ω that's ≤ 83 mV of pull. Electrically harmless against 20+ mA terminators and 48 mA drivers, but strictly outside §5.4.1.2 in the mid-chain case. Main topology (terminator on) is unaffected, because §5.4 excludes termination from these measurements.
- **Fix:** correct the NOTES wording; no hardware change. (A non-bus-hold '245, e.g. SN74LVT245B, would avoid it, but that's preference given the magnitude.)
- **Confidence:** high on the datasheet values; the "harmless" judgement is an estimate.
- **Owner decision:** approved (2026-09-26)

### R027 [Low] SCSI: disabled terminator adds ~9 pF (C_io) to each line, pushing the mid-chain case past 25 pF
- **Evidence:** SN74LVTH245A C_io = 9 pF (p.4). Series 110 Ω doesn't isolate it at the 1 MHz where capacitance is specified (X_C ≈ 18 kΩ). Our per-line estimate: FDV301N C_oss ≈ 9–10 pF at V_DS = 2.8 V (Fig. 8, read from the curve: ~12 pF at 1 V, ~10 pF at 2 V, ~7.5 pF at 5 V) + 74LVC1G17 C_I 5 pF typ (Table 7; no max given) + H5VUD5BB C_J 0.3 typ / **0.5 pF max** + trace ~3 pF ≈ 18 pF; + 9 pF = **~27 pF** > 25 pF (§5.4.1.2) when the terminator is disabled. With it enabled, §5.4 ("termination is assumed to be external") excludes it, so the main topology is ≈ 18 pF: OK.
- **Impact:** only the secondary mid-chain topology, by ~2 pF, on typical numbers. Practically negligible at async/5 MB/s speeds.
- **Fix:** note it in NOTES "ESD protection" capacitance budget; no change.
- **Confidence:** med (typical values; no max C_I for the 1G17).
- **Owner decision:** approved (2026-09-26)

### R028 [Info] SCSI: FDV301N C_oss / C_rss at 2.8 V checked against Fig. 8
- **Evidence:** Fig. 8 (fdv301n.pdf p.4, V_GS = 0, 1 MHz, typical): at V_DS ≈ 2.8 V, **C_oss ≈ 9–10 pF**, **C_rss ≈ 2.2 pF**, C_iss ≈ 11 pF; at V_DS ≈ 0.3 V (asserted) C_oss ≈ 16 pF, C_rss ≈ 6 pF, C_iss ≈ 18 pF. NOTES' "C_oss ~10 pF, C_rss ~2.5 pF at 2.8 V" is consistent (slightly conservative on C_rss). Table values (6 / 1.3 pF) are at 10 V and don't apply.
- **Confidence:** med (read from a log-scale plot).

### R029 [Info] USB: CH334P pinout, ports and external-3.3 V wiring checked
- **Evidence (CH334DS1_en V2.5):** Fig. 1-1 (p. 1): CH334P QFN-16 = 1 XO, 2 XI, 3 DM4, 4 DP4, 5 DM3, 6 DP3, 7 DM2, 8 DP2, 9 DM1, 10 DP1, 11 DMU, 12 DPU, 13 RESET#/CDP, 14 PGANG, 15 V5, 16 VDD33, EPAD (0) = GND. So it **has** RESET#, XI/XO and all four downstream ports. Table 1-1 (p. 2): CH334P is **MTT**, no over-current detection, no power control, no external EEPROM, crystal-free optional. §4.2 (p. 20): with no internal LDO, **V5 = 3.2–3.4 V and VDD33 = 3.2–3.4 V** ("External supply voltage @ V5, no internal LDO required"), so tying V5 and VDD33 to the 3.3 V rail is the documented mode; §6.1 (p. 27) recommends exactly this for industrial use. Decoupling (Table 1-3, p. 4): V5 "external 1 µF or larger"; VDD33 "0.1 µF + 10 µF, or 1 µF". Any two downstream ports work; leave the unused DP/DM pins open (built-in pull-downs, §Features).
- **PGANG (pin 14)** is not mentioned in the notes. It is an I/O with an internal pull-up that is sampled during reset (high = ganged mode, the only mode the P supports anyway) and then becomes a static Active/Suspend **output** (§3.3.5, p. 14–15). Leave it unconnected, or use it for a hub "active" LED (≈1 kΩ, per Fig. 3-3-5 left). Don't tie it to a rail.
- **Hub power descriptor:** the CFG default 0x57 has SELF_POWER = 1 (Table 3-5-2, p. 17), so the hub reports self-powered. That's convenient: the host then doesn't limit downstream devices to 100 mA as it would behind a bus-powered hub (so an FT232H or RP2350 asking for > 100 mA still gets configured). No action needed; don't try to change it.
- **Confidence:** high.

### R030 [Med] USB: CH334 low-voltage reset threshold (up to 3.2 V) sits on the 3.3 V rail's worst case
- **Evidence:** CH334DS1_en V2.5 §4.2 (p. 21): **V_lvr = 2.5 / 2.9 / 3.2 V (min/typ/max)**; §3.2.1: below V_lvr the chip resets. External-3.3 V mode allows 3.2–3.4 V. NOTES "Resistor and small-part values": 3.3 V rail worst case **3.16–3.44 V** (legacy TPS737 silicon) or 3.21–3.39 V (new). NOTES already accepted the 3.2 V *operating* minimum risk; the LVR number wasn't considered.
- **Impact:** on a low-corner LDO plus a load step (SD write, TERMPWR enable), a max-LVR hub resets and the host sees the FT232H and RP2350 drop off the bus mid-scan. §6.1 (p. 27–28) warns about exactly this LVR-triggered disconnect.
- **Fix (no redesign):** measure the rail at bring-up as planned, and under load (SD write + TERMPWR on). If it reads < 3.28 V, move the divider up (e.g. R2 27 k → 26.7 k-class, if a no-fee value exists) to centre near 3.33 V; staying ≤ 3.4 V still matters because of the upper limit. Put generous local caps on VDD33 (10 µF + 0.1 µF, as §6.1 advises to ride through dips).
- **Confidence:** medium (depends on the LDO's actual corner, which JLC doesn't let us choose).
- **Owner comment:** Sounds good - leave me an unpopulated 0603 footprint to add a resistor to parallel into R2 so that I can fix it with some local rework

### R031 [Low] USB: CH334 RESET#/CDP: the external 10 kΩ pull-up may enable CDP and disable hub sleep; WCH wants the pin left undriven
- **Evidence:** CH334DS1_en §3.2.2–3.2.3, Table 3-2 (p. 11–12): RESET# has an internal ~25 kΩ pull-up. "Drive is high during power-up → Enable CDP and turn off low-power sleep"; "No drive or no connection (default) → No CDP, low-power sleep support". Table 1-3: "It is recommended to be completely suspended [floating] when not reset." WCH's fix for an MCU-driven reset is a series Schottky (Fig. 3-2-2). Low-drive requirement: ≤ 800 Ω source, pulse > 4 µs, V_ILRST ≤ 0.75 V. The NOTES table puts a 10 kΩ pull-up on "CH334 reset" and a push-pull TCA9555 pin (P14) on it.
- **Impact:** probably benign (our downstream devices don't use BC1.2 charging), but it's an undocumented state and it raises suspend current (adds to the existing "USB suspend current" finding). A 10 kΩ external pull-up might or might not count as "drive high"; WCH doesn't say.
- **Fix:** don't fit the 10 kΩ (the internal 25 kΩ already defaults to "run", which satisfies the fallback rule). Drive the pin from P14 through a small Schottky (cathode at the expander) or keep P14 as input (hi-Z) except when pulsing low. P14 powers up as an input, so the power-up state is already "no drive".
- **Confidence:** medium (depends on how the CDP sampler reads a 10 kΩ pull-up).
- **Owner decision:** approved (2026-09-26)

### R032 [Med] USB: bench-powered with the host off, the hub's upstream D+ pull-up back-drives the cable (no VBUS detect on CH334P)
- **Evidence:** CH334DS1_en: "Built-in 1.5KΩ pull-up resistor on the upstream port" (Features, p. 0); the CH334P has no VBUS-sense pin (Fig. 1-1; the V5 pin is on the 3.3 V rail in our mode, so it can't sense VBUS either). USB 2.0 §7.1.5.1 (quoted from memory, unverified wording): "the voltage source on the pull-up resistor must be derived from or controlled by the power supplied on the USB cable such that when VBUS is removed, the pull-up resistor does not supply current on the data line". Our board runs from the bench input (R8a) with VBUS absent, e.g. the laptop asleep/off with the cable still plugged in. The FT232H and RP2350 pull-ups face the hub, which is powered, so only the hub's upstream port matters. FTDI handles the same case with PWRSAV# from VBUS via 39 kΩ (DS Table 3.2), which doesn't apply here because the FT232H is behind the hub.
- **Impact:** ~2 mA through 1.5 kΩ into a powered-off host's D+ (and its ESD/body diodes). A spec violation rather than a likely failure; some hosts wake or misdetect.
- **Fix (suggestion):** hold the hub in reset when VBUS is absent. Cheapest: a VBUS_PRESENT divider (e.g. 10 k / 15 k from the USB-C VBUS, before the ORing diode) into a spare expander input (P06), and firmware drives HUB_RESET_N low while it reads 0. Hardware-only option: a divider from VBUS straight to RESET#: the pin is 5 V tolerant ("5I") and the bottom resistor must be ≤ ~7 kΩ to beat the internal 25 kΩ pull-up below V_ILRST = 0.75 V. **Unverified:** whether the CH334 disconnects its 1.5 kΩ pull-up while in reset. Check it on the bench (measure DPU with RESET# low).
- **Confidence:** medium.
- **Owner comment:** Realistically I'm only going to use the bench supply if my usb-c is insufficient, and I'll probably turn the bench supply off before I turn off my laptop or desktop. note it as a very minor design flaw and we can move on.

### R033 [Low] Bootstrap: CS1 re-pad erratum is RP2350-**E14**, not E15
- **Evidence:** rp2350-datasheet.pdf, Appendix E (errata, p. ~1358): **RP2350-E14** "The bootrom connect_internal_flash() function always uses pin 0, ignoring any configured CS1 pin … Manually configure the CS1 pads registers to remove the isolation". **RP2350-E15** is "otp_access() applies incorrect access permission to pages 62 & 63". NOTES line 439 (GPIO budget table) cites E15.
- **Fix:** change "E15" to "E14" in the NOTES table.
- **Confidence:** high.
- **Owner decision:** approved (2026-09-26)

### R034 [Question] Bootstrap: which RP2350 stepping will JLC fit (A2 vs A3/A4)?
- **Evidence:** rp2350-datasheet.pdf errata: **RP2350-E9 affects A2 only**; E10 (UF2 drag-and-drop fails with a partition table) is A2 only; E19 fixed by the A3 bootrom; the A4 bootrom fixes E18 and more. The 4.7 kΩ gate pull-downs and the "clear input enable" firmware rule exist only because of E9.
- **Impact:** none if we keep the E9 mitigations (they cost nothing on A4). But on A2 silicon, UF2 drag-and-drop stops working as soon as we add an A/B partition table (the "later, optional" in-app update plan), and picotool must be used instead.
- **Question for the owner:** check the date code/stepping of JLC's C42415655 stock before ordering (or read it at bring-up with `picotool info -a`, which prints the chip revision). Keep the E9 mitigations regardless.
- **Confidence:** high on the errata scope; unknown stepping.
- **Owner decision:** approved (2026-09-26)
- **Owner comment:** Let's assume A4. A3 is impossible. A2 is possible but unlikely.

### R035 [Info] USB: RP2350 native USB behind the hub: 27 Ω, VBUS detect, errata, ESD
- **27 Ω:** "Hardware design with RP2350" §5.1: USB_DP/DM need no extra pull-ups; 27 Ω series close to the chip. OK as planned.
- **VBUS detect:** there is no VBUS_DETECT pin in our pin map. That's fine: the RP2350 datasheet §12.7 (USB, p. ~1180, `usb_hw->pwr = USB_USB_PWR_VBUS_DETECT_BITS | …_OVERRIDE_EN_BITS`) shows the forced-VBUS override, which the SDK/TinyUSB and the bootrom use. Behind an always-powered on-board hub, "VBUS" is effectively always present. Side effect (datasheet §12.7.3.8.4): the RP2350 can't tell "host unplugged" from "suspended". Firmware shouldn't care.
- **Errata:** RP2350-E12 (USB status signals not synchronised) bites only when clk_sys ≤ clk_usb (48 MHz); we run 150 MHz. No other USB-device erratum affects us.
- **ESD at HS:** H5VUD5BB 0.3 pF typ (h5vud5bb.pdf p. 1), one per line; negligible for 480 Mbit/s. V_RWM 5 V > the 3.6 V D± maximum. OK.
- **USB-C:** both D+/D− pairs tied at the receptacle (the stub is < 1 mm on the HRO footprint if tied at the pads); CC1/CC2 each with its own 5.1 kΩ Rd (parts list §1) → correct sink. OK.
- **100 mA before configuration:** confirmed as a deviation (USB 2.0 §7.2.1: one unit load until configured); already accepted. Behind the hub nothing else changes.
- **Confidence:** high.

### R036 [Info] SCSI: FDV301N V_OL, real sink current, I_DSS, gate drive checked
- **Evidence (fdv301n.pdf p.2):** R_DS(on) ≤ 5 Ω at V_GS 2.7 V, 25 °C; ≤ 9 Ω at T_J 125 °C (I_D 0.2 A). Our V_GS = 3.3 V × 4.7k/4.8k ≈ 3.2 V (≥ 3.1 V at the 3.16 V worst rail), so the 2.7 V row is conservative. Real load: our terminator ≤ 2.93 V/108.9 Ω + a far 2.85–2.9 V/110 Ω active terminator: I = 53.5 mA/(1 + 2R/109) → **49 mA, V_OL 0.25 V** at 5 Ω; **46 mA, V_OL 0.41 V** at 9 Ω. Meets §5.4.1.1 (≤ 0.5 V at 48 mA). Self-heating 48 mA² × 5 Ω = 12 mW → +4 °C (R_θJA 357 °C/W). I_DSS ≤ 1 µA (10 µA at 55 °C) at V_DS 20 V, far under I_IH 0.1 mA. Gate: Q_g to ~3.2 V ≈ 0.37 nC (Fig. 7), plateau 2.1 V, through 100 Ω + pad → turn-on/off ≈ 5–15 ns; static pull-down load 0.69 mA per asserted pin (≤ 9.6 mA for all 14). V_GS abs max 8 V, V_DS 25 V: fine.
- **Confidence:** high.

### R037 [Low] SCSI: gate-kick concern is real in size but self-limiting; the "fit 22 pF above 0.4 V" rule is stricter than needed
- **Evidence:** integrating C_rss(V) from Fig. 8 over a 0.3→2.8 V rising edge gives ≈ 8 pC; into C_gs + C_gd ≈ 12–14 pF (Fig. 8) held by 4.7 kΩ (τ ≈ 60 ns ≫ a ~5–10 ns incident-wave edge) → **≈ 0.55–0.65 V** kick, matching NOTES' ~0.6 V. But V_GS(th) (0.70–1.06 V, −2.1 mV/°C) is defined at I_D = 250 µA, so a kick to ~0.7 V for tens of ns sinks at most a few hundred µA from a 20+ mA terminator, and it acts *against* the rising edge (negative feedback), so it can't latch or glitch the line. With the board powered, the gate sees ~150 Ω and the kick is ~0.
- **Impact:** none expected; bench check still worthwhile. If fitted, 22 pF slows our own switching only to τ ≈ 150 Ω × 37 pF ≈ 5.5 ns: harmless.
- **Fix:** reword the bench criterion to "fit the caps if the kick produces a visible dip/step on the bus edge", not a gate-voltage number.
- **Confidence:** med (typical curves).
- **Owner decision:** approved (2026-09-26)

### R038 [Info] SCSI: 74LVC1G17 thresholds, I_OFF, input tolerance, output drive re-checked; small doc slip
- **Evidence (74LVC1G17.pdf Rev 16.1, Table 8 p.6):** at V_CC 3.0 V: VT+ 1.29–1.71 V (−40…85 °C) / **1.26–1.71 V (−40…125 °C)**; VT− 0.88–1.24 V / **0.88–1.27 V**; V_H ≥ 0.31 / 0.25 V. At 4.5 V: VT+ ≤ 2.36, VT− ≥ 1.32. Linear interpolation to 3.3 V: VT+ ≤ 1.84, VT− ≥ 0.97 (NOTES correct). At the 3.3 V rail's own worst case (3.16–3.44 V, NOTES resistor table): **VT+ ≤ 1.90 V, VT− ≥ 0.93 V**: still inside SCSI-2's 2.0/0.8 V, margin 0.10/0.13 V (interpolated, not guaranteed). I_OFF ±2 µA and I_I ±1 µA at 5.5 V (Table 7); V_I rated 0–5.5 V (Table 6), so 5.25 V bus is fine. Output: V_OH ≥ 2.3 V at −24 mA/3.0 V (≈ ≤ 29 Ω); a shorted LA pin draws ≤ 3.3/(100+~25) ≈ 26 mA (abs max ±50 mA, P_tot 250 mW): fine. tpd 0.7–5.5 ns → channel skew ≤ 4.8 ns: negligible. NOTES' "VT+ 1.29–1.71, VT− 0.88–1.24 (−40…125 °C)" quotes the 85 °C columns under a 125 °C label (Low doc slip).
- Fallback 74LVC14A (Nexperia Rev 11, Table 9): VT+ 1.2–**2.0** V at 3.0 and 3.6 V: meets VIH ≤ 2.0 V with **zero** margin; VT− ≥ 0.8 (zero margin); V_H 0.3–1.2 V. "Guaranteed" is right but it's at the edge; worth saying in NOTES.
- **Confidence:** high.

### R039 [Low] SCSI: '245 DIR pin and A inputs must be tied explicitly; say so in NOTES
- **Evidence:** SN74LVTH245A function table (p.2): /OE L + DIR **H** = A→B; DIR L = B→A. NOTES/parts-list only say "A inputs tied high, /OE = enable"; DIR isn't mentioned. With DIR low, the A pins become outputs fighting the tie to VCC whenever the bus is asserted (≈ 64–128 mA-class short per pin) and the B side stops terminating. Datasheet note 5 (p.3): unused control inputs at VCC or GND; bus-hold inputs shouldn't use pull resistors (p.2), so tie A1–A8 and DIR straight to the 2.8 V rail. Unused A7/A8/B7/B8 (6 of 8 used): B7/B8 leave unconnected (they'll just drive high).
- **Fix:** add to NOTES "Termination" and the schematic checklist.
- **Confidence:** high.
- **Owner decision:** approved (2026-09-26)

### R040 [Info] SCSI: /OE network levels checked (DIP / 10 k / 1 k / TCA9555)
- **Evidence:** DIP1 on: 2.8 V × 1k/11k = **0.25 V** (V_IL ≤ 0.8 V). With TCA9555 inputs' internal 100 kΩ pull-ups to 3.3 V (I_IL −100 µA at GND, tca9555.pdf p.7) still ≈ 0.28 V. Off: ≈ 2.8–2.85 V (V_IH ≥ 2.0 V). Expander driving high against DIP1: ~3.1 mA, V_OH ≥ 2.6 V at −8 mA/3 V (p.7) → node ≈ 3.1 V: /OE high. LVTH control inputs tolerate 5.5 V even at VCC 0 (I_I 10 µA, p.4), so 3.3 V on /OE with VCC 2.8 V is fine; ≤ 50 µA flows back into the 2.8 V rail via the 10 k, less than the rail's ~0.7 mA idle load. Enable/disable times t_PZH/t_PHZ ≤ 7.4 ns (p.5): irrelevant for a static switch.
- **Confidence:** high.

### R041 [Info] SCSI: per-package current and power-up ramp of the LVTH terminator
- **Evidence:** 6 lines × ≤ 22.3 mA = 134 mA through one VCC pin. SCBS130T has **no** continuous VCC/GND pin current rating (only per-output I_OH −32 mA recommended, p.3); each output at ~22 mA is inside that. Dissipation ≈ 6 × 22 mA × ~0.3 V ≈ 40 mW → +3 °C (θ_JA 83 °C/W PW). BlueSCSI v2 runs 8 per package. Power-up ramp: SCBS130T recommends Δt/ΔV_CC ≥ 200 µs/V (p.3); TPS737 start-up ≈ 431–600 µs to 3 V with 1 µF (tps737.pdf §6.5) ≈ 150–200 µs/V, at the edge; more C_OUT slows it. Effect is only a possible sub-ms glitch at power-up while I_OZPU keeps outputs high-Z below 1.5 V. Acceptable.
- **Confidence:** med (no package-current spec exists to check against).

### R042 [Low] SCSI: our 2.8 V terminator rail can be pumped up by a push-pull / active-negation driver elsewhere on the bus
- **Evidence:** SCSI-2 §5.4.1.1 allows three-state drivers with V_OH up to 5.25 V. SN74LVTH245A abs max note 2 (p.3): "current into any output in the high state … flows only when … V_O > V_CC" (64 mA max per output), i.e. there is a path from an output pin to VCC. A line driven high to V > ~2.8 V + ~0.5 V pushes up to (V − 3.3)/110 Ω into our rail per line (e.g. 3.8 V active negation → ~4.5 mA per line, ×9 data lines ≈ 40 mA). The TPS737 can't sink, and the rail's own load is ~0.7 mA idle, so the rail would rise toward the bus level, raising every released line's terminator voltage (and VCC abs max for the LVTH is 4.6 V). NOTES "Terminator LDO" already flags "LDO can't sink" as a to-check.
- **Impact:** unlikely in our topologies (WD33C93A and most SCSI-2 SE drivers are open-drain, active-negation parts typically negate to ~2.5–3.3 V), unverified for the G4's Adaptec card.
- **Fix:** fit the bleed NOTES already suggests: e.g. 270 Ω to GND on the 2.8 V rail (~10 mA, 29 mW; also puts the TPS737 inside its ≥ 10 mA accuracy spec). Scope the rail during the G4 captures.
- **Confidence:** low (V_O > V_CC path magnitude not characterised in the datasheet).
- **Owner decision:** approved (2026-09-26)

### R043 [Info] Bootstrap: first power-up of a fresh JLC board (blank flash, blank EEPROM) works without any firmware
Walk-through, USB-C to a Mac or a Windows PC:
1. **Hub:** the CH334P is fixed-function (config in internal ROM, CFG default 0x57; CH334DS1_en §3.5), so it enumerates as a USB 2.0 HS hub as soon as 3.3 V and its crystal are up (POR delay 5–14 ms, §3.2.1). No driver on either OS (inbox hub class).
2. **FT232H:** blank EEPROM → built-in defaults: VID 0403, PID 6014, "Single RS232-HS", UART mode, no serial number (DS §7.1, Table 7.1). It enumerates at HS behind the hub. macOS: Apple's DriverKit `AppleUSBFTDI` dext binds it (see the Host finding). Windows: the FTDI CDM driver comes from Windows Update (internet needed on first plug; offline machines need FTDI's installer).
3. **RP2350B:** blank flash has no valid IMAGE_DEF, so the bootrom falls through to BOOTSEL: USB mass storage ("RP2350" drive) + the PICOBOOT vendor interface, VID 2E8A PID 000F (rp2350-datasheet §5.6.1). QSPI SD1 is pulled down by default → USB boot, not UART boot (§5.2.4.1, §5.8); nothing on our bus drives SD1 while CS0 is low with no clock, and the PSRAM's CS1 is held high by the fitted 10 kΩ on GPIO 47. It needs the 12 MHz crystal (the bootrom assumes 12 MHz unless OTP says otherwise, §5.8.1); we have it. Behind the hub, full speed through the hub's TT; nothing special.
4. **Flashing:** drag a UF2 onto the drive (macOS and Windows, no driver), or `picotool load`. picotool uses libusb: macOS needs nothing; on Windows the RP2350 bootrom carries WCID/MS OS descriptors so WinUSB binds without Zadig (picotool README, https://github.com/raspberrypi/picotool; unverified on our board). The SDK's default UF2 family is `rp2350-arm-s` 0xE48BFF59 (RP2350A and B share family IDs; datasheet Table 455). **No partition table is needed**: without one, a non-absolute UF2 is written to the start of flash (datasheet §5.1.18 ≈ p. 399, "The UF2 is always downloaded to the start of flash").
5. **Back to BOOTSEL later without a button:** `picotool reboot -f -u` uses the app's reset interface. With `pico_stdio_usb`, `PICO_STDIO_USB_RESET_INTERFACE_SUPPORT_MS_OS_20_DESCRIPTOR` defaults to 1, so Windows binds WinUSB automatically (pico-sdk `stdio_usb.h`, https://github.com/raspberrypi/pico-sdk/blob/master/src/rp2_common/pico_stdio_usb/include/pico/stdio_usb.h). **If we write our own TinyUSB descriptors** (CDC + reset + anything else), we must carry the BOS/MS OS 2.0 descriptor ourselves, or Windows will need Zadig for picotool (R5). Firmware can also call the ROM `reboot()` with BOOTSEL directly on a CDC command.
6. **Buttons and SWD:** BOOTSEL = QSPI_SS → 1 kΩ → button (guide §3.1) is right, and it stays right with the PSRAM because the PSRAM is on CS1. SWD via TC2030: pad 1 VCC gives the J-Link its VTref; pad 3 → RUN. J-Link supports RP2350 flash programming; the PSRAM on CS1 doesn't interfere.
- **Confidence:** high, except the Windows WCID detail (from the picotool README, not tested).

### R044 [Med] Bootstrap: FT232H EEPROM first programming on macOS: `ftdi_eeprom` can set FT1248 mode but not its clock-polarity / bit-order / flow-control bits, and needs `eeprom_type=0x56` and root
- **Evidence:**
  - Blank EEPROM is programmable over USB, by design: DS §7.2 (p. 47) "This allows a blank part to be soldered onto the PCB and programmed as part of the manufacturing and test process." FT_PROG (Windows) exposes FT1248 mode and its three options (DS Table 7.1 "FT1248 Settings … Clock Polarity High; Bit Order LSB and Flow Control"; AN_167 §3, §7, §8).
  - libftdi 1.5 (latest release; source read from https://www.intra2net.com/en/developer/libftdi/download/libftdi1-1.5.tar.bz2): `ftdi_eeprom/main.c` accepts `cha_type = FT1284` (libftdi's name for FT1248; `CHANNEL_IS_FT1284`, written as type 0x08 for the FT232H), but has **no config keys** for the FT1248 options. The library itself supports them (`ftdi_set_eeprom_value(ftdi, CLOCK_POLARITY | DATA_ORDER | FLOW_CONTROL, …)`, bits 0x01/0x02/0x04 at EEPROM byte 0x01), with the source comment `FT1284_DATA_LSB 0x02 /* DS_FT232H 1.3 and ftd2xx.h 1.0.4 disagree here */`.
  - `ftdi_eeprom_build()` sets the image size to 0x100 only if `chip == 0x56 || 0x66`; `ftdi_eeprom`'s `eeprom_type` defaults to 0, which builds a 128-byte (93x46) image. An FT232H with a 93LC56B needs `eeprom_type = 0x56`.
  - On macOS the Apple dext holds the interface, so libftdi can only open the device as root (it auto-detaches the kernel driver; see the Host finding).
- **Impact:** not a bricking risk (see next finding), but the first programming on a Mac needs a small custom program, not just a config file, and the LSB bit meaning is ambiguous between FTDI's own documents.
- **Fix (suggestions):** (a) do the first programming once with FT_PROG on any Windows PC and read the result back with `ftdi_eeprom --read-eeprom` to capture a golden 256-byte image; afterwards macOS can write that image with `flash_raw = true`. Or (b) write a ~30-line libftdi (or pylibftdi) program that sets CHANNEL_A_TYPE = FT1284, CLOCK_POLARITY, DATA_ORDER, FLOW_CONTROL, VID/PID, strings, and `CHIP_TYPE = 0x56`, then builds and writes. Either way, **verify the FT1248 bits on the bench**: with SS_n high and flow control on, MISO should follow RXF# and MIOSIO0 TXE#; clock polarity shows in the first command-phase edge. Also set "Suspend on ACBus7 Low" = off, self-powered = on (the hub is self-powered), and max power ≈ 100 mA.
- **Confidence:** high on the libftdi source; the FT1248 bit semantics are unverified.
- **Owner decision:** approved (2026-09-26)

### R045 [Info] Bootstrap: the FT232H can't be bricked by bad EEPROM contents
- **Evidence:** EEPROM reads/writes are vendor control requests on endpoint 0, which work in every interface mode. A bad checksum makes the chip ignore the EEPROM and fall back to the defaults (0403:6014, UART) (DS §7.1). The worst self-inflicted case is a custom VID/PID that no driver matches: libusb/libftdi opens any VID/PID; D2XX needs `FT_SetVIDPID` on macOS (on Windows, an INF edit). If all else fails, shorting the 93LC56B DO to GND via a pad during power-up forces a blank read (unverified trick; not needed normally).
- **Confidence:** high.

### R046 [Info] SCSI: H5VUD5BB on a 2.8–5.25 V bus
- **Evidence (h5vud5bb.pdf p.2):** V_RWM 5.0 V; V_BR 6.0–10 V at 1 mA; I_R ≤ 0.2 µA at 5 V; C_J 0.3 typ / 0.5 pF max; bidirectional. The terminated bus idles at 2.7–3.2 V (active or 220/330 passive from ≤ 5.25 V TERMPWR). Only a push-pull driver at the SCSI-2 V_OH ceiling (5.25 V, §5.4.1.1) exceeds V_RWM, by 0.25 V, still 0.75 V below min breakdown; leakage there is µA-level at most vs I_IH 100 µA. OK.
- **Confidence:** high (datasheet), leakage at 5.25 V inferred.

### R047 [Info] SCSI: rise/fall and stubs
- **Evidence:** releasing our FET removes ~47 mA from a node that sees our 110 Ω terminator in parallel with the cable (ribbon Z0 ≈ 90–100 Ω, typical, unverified): the incident step at our connector is ≈ 47 mA × ~50 Ω ≈ 2.3 V, i.e. to ≈ 2.5 V in one step, then RC with ~18 pF × 50 Ω ≈ 1 ns. So the released edge at our end is incident-wave, not "terminator into cable capacitance" RC; NOTES' "slower rising edge" is pessimistic (the real delay is FET turn-off, see the data_out deskew finding). Falling: 5 Ω FET into ~50 Ω → one step to ~0.25 V in the FET's ~5–10 ns switching time; 100 Ω gate resistor is the slew knob. Stub: §5.2.1 ≤ 0.1 m incl. inside the device; with per-line clusters by the IDC50 the on-board stub is ≲ 30–50 mm (layout to confirm); at the end-of-chain position the on-board run to the terminator is part of the end, not a stub.
- **Confidence:** med (cable Z0 assumed).

### R048 [Info] SCSI: RP2350-E9 handling and the 4.7 kΩ pull-down
- **Evidence:** RP2350 datasheet p.1366–1367: leakage (~120 µA, source ≈ 2.2 V) occurs only with IE = 1, output disabled, and the pad voltage in the undefined region; a pull ≤ 8.2 kΩ keeps it low, and clearing IE removes it. 4.7 kΩ holds a floating gate at ~0 V (below VIL) so the leakage never starts. Reset state IE = 0 (NOTES cites Table 853). The firmware rule (clear IE on the 14 gate pins) is correct: PIO never needs to read them (IN_COUNT = 18 masks GPIO 18–31 from `mov x, pins` in the sniffer anyway).
- **Confidence:** high.

### R049 [Low] SCSI: no firmware rule for "TERMPWR absent"; floating inputs with no termination
- **Evidence:** with TERMPWR off (USB port < 1.5 A and no bench supply, jumper out, or eFuse fault) and no other device supplying it, both terminators are dead: released lines float (only FET I_DSS and 1G17 ±1 µA leakage), so the 1G17 inputs sit at undefined levels (ΔI_CC up to 500 µA each, Table 7) and read random data; the '245 has VCC = 0 (Ioff ±100 µA). SCSI-2 §5.4.1(b)(5) needs "at least one device supplying TERMPWR". TERMPWR_OK (expander P05) and TERMPWR fault (FLT) exist.
- **Impact:** firmware may see phantom BSY/SEL/REQ and try to run phases on a dead bus.
- **Fix:** firmware rule: no arbitration/selection unless TERMPWR_OK; report "no TERMPWR" to the host; sniffer marks captures invalid while TERMPWR_OK is low.
- **Confidence:** high.
- **Owner decision:** approved (2026-09-26)

### R050 [Info] SCSI: parity, DB(P) in arbitration, listen-only
- **Evidence:** §5.6/Annex (NOTES table): DB(P) odd parity required in SCSI-2, undefined during arbitration, must not be driven false then. Open-drain can't drive "false" at all, and the arbitration step writes only our ID bit (the injected instruction must write a 9-bit word with only that bit set, or use `set`, so DBP stays released). data_out carries precomputed parity in bit 8; data_in captures DBP in bit 8, so firmware can check it (SCSI-2 makes checking optional for the initiator; recommend checking and logging). Listen-only: all gates held low by firmware + 4.7 k; receivers always on; nothing drives: OK.
- **Confidence:** high.

### R051 [Low] SCSI: remaining doc inconsistencies in the terminator/PIO text
- **Evidence:** NOTES "Termination" still says "8 × 24 mA ≈ 190 mA through one '245 Vcc pin" (now 6 × ≤ 22.3 mA ≈ 134 mA) and "the 2.85 V idle"; blocks/2-scsi-frontend.md says "3 × 74LVT245" (the part is SN74LVTH245A, bus-hold variant, which matters for the bus-hold finding above); NOTES PIO sketch comment "≥ 55 ns deskew" (SCSI-2 Table 7 deskew = 45 ns; 55 ns = deskew + cable skew); NOTES "Terminator LDO" "(b)(3) allows each terminator ≤ 22.4 mA" (the text is a 44.8 mA two-terminator total). Log entry 2026-09-24 "2.85 V LDO → 74LVT245" is history, fine as is.
- **Fix:** wording only.
- **Confidence:** high.
- **Owner decision:** approved (2026-09-26)

### R052 [Med] Host: on macOS, Apple's built-in FTDI DriverKit driver claims the FT232H (0403:6014), so libusb/pyftdi and D2XX can't open it without root
- **Evidence:**
  - On the owner's own Mac (Darwin 25.6): `/System/Library/DriverExtensions/com.apple.DriverKit-AppleUSBFTDI.dext/Info.plist` has a personality **"DriverKit-AppleUSBFTDI-6014"** matching idVendor 1027 (0x0403), idProduct 24596 (0x6014), bInterfaceNumber 0 (checked with `plutil -p`, 2026-09-26). It ships with macOS; it is not the old kext that pylibftdi's docs say was removed in Monterey.
  - A 2025/26 report of exactly this: "macOS's DriverKit FTDI driver (`com.apple.DriverKit-AppleUSBFTDI`) claims the FT232H's only interface", unprivileged libftdi tools see no device, and the workaround is `sudo` (https://github.com/thejefflarson/little-cpu/pull/358).
  - FTDI's own macOS answer for D2XX is `D2xxHelper.kext`, a codeless kernel extension that stops VCP drivers matching (FTDI AN_134, https://www.ftdichip.com/Support/Documents/AppNotes/AN_134_FTDI_Drivers_Installation_Guide_for_MAC_OSX.pdf). That's a third-party kext: against R5, and on Apple Silicon it needs Reduced Security. Whether it even pre-empts a DriverKit dext is unverified.
  - The EEPROM "Load VCP driver" / "D2XX direct" bit is only honoured by FTDI's Windows driver, not by Apple's matching (Apple matches on VID/PID/interface).
- **Impact:** R5 ("no custom kernel drivers on macOS") and the plan "D2XX/pyftdi on the host" conflict on macOS with the default PID. The host tool would have to run as root, or use a different path.
- **Options (for the owner, see the Question below):**
  1. **Keep 0403:6014 and use Apple's serial node** (`/dev/cu.usbserial-<serial>`) as the data pipe on macOS. In FT1248/FIFO modes the bulk endpoints carry the data regardless of baud settings, so this can work driverlessly. Follow-up research (below) makes this the leading option; throughput is still unmeasured.
- **Follow-up (2026-09-26): what the Apple dext actually does.** Disassembled on the owner's Mac (Darwin 25.6, arm64e). `AppleUSBFTDI` is a thin subclass of Apple's generic `IOUserUSBSerial` (USBSerialDriverKit, extracted from the DriverKit dyld shared cache); the USB plumbing is all in the base class.
  - **Data path is mode-agnostic.** `AppleUSBFTDI::handleRxPacket` strips the 2 FTDI status bytes at the start of each IN transfer (reports modem/line-error bits) and passes the rest through. Nothing checks the chip mode, so FT1248 data should flow. It drops XON/XOFF bytes only if software flow control is on, so open the port raw (`cfmakeraw`, no IXON/IXOFF; pyserial does this).
  - **Throughput limit: one 512-byte read in flight.** `IOUserUSBSerial_IVars::rxSubmit` issues one `IOUSBHostPipe::AsyncIO` of wMaxPacketSize bytes (read from the endpoint descriptor at start: 512 at HS). It won't submit another until `rxComplete` has run in the dext and copied the data **byte by byte** into the ring buffer. So each 510 payload bytes pay a full kernel → dext → kernel round trip. Estimate (**unverified**): 50–150 µs per trip ≈ 3–10 MB/s, plus the tty layer above it, whose limit is unknown. R3's 1.5 MB/s looks plausible, not certain. If the host lags, the dext stops resubmitting (backpressure), the FT232H's 1 KB buffer fills and TXE#/flow control holds the RP2350 off. **Slowness costs speed, not data.**
  - **Interface opened only while the tty is open.** `IOUSBHostInterface::Open` is called only from `ConnectQueues` (the tty open) and `Close` from `DisconnectQueues`. While nobody has `/dev/cu.*` open, the dext holds no open on the interface. This fits PyFtdi's docs ("from Mojave the Apple kernel extension peacefully co-exists with libusb and PyFtdi") and conflicts with the little-cpu report above. Whether unprivileged libusb/pyftdi can claim it while the tty is closed is **unverified**; needs a bench check.
  - **Latency timer:** `AppleUSBFTDI::HwProgramLatencyTimer_Impl` sends vendor request 0x09 (SET_LATENCY_TIMER). User space reaches it with `ioctl(fd, IOSSDATALAT, &v)` (OpenBCI forum, https://openbci.com/forum/index.php?p=%2Fdiscussion%2F3108; reports that the unit is really ms, not µs, and that 0 misbehaves). We barely need it: FT1248 has a **write-buffer-flush command (0x4)** that flushes "rather than wait for any latency timers to expire" (AN_167 Table 1, p. 19). Firmware sends it after each short reply.
  - **FTDI's own dext is also installed on this Mac:** `com.ftdi.vcp.dext` 1.1 (from `FTDIUSBSerialDextInstaller_1_5_0`, dmg dated 2024-08-27), active per `systemextensionsctl list`. It has an "FT232H" personality (0403:6014, bcdDevice 0x0900) in a different `IOMatchCategory` (`com.qa.driverkit`), and its class (`NullDriver`, a leftover sample name) also subclasses `IOUserUSBSerial`: same one-packet read engine. It has no `HwProgramLatencyTimer_Impl` (the latency comes from its plist `ConfigData`), so IOSSDATALAT probably does nothing with it. Which dext binds, or whether both try to, is **unverified**. Check with `ioreg -l -w0 -r -c IOUSBHostInterface` when a board is plugged in. Removing FTDI's dext (System Settings › General › Login Items & Extensions › Driver Extensions) is optional.
  2. **Keep 0403:6014 and run the host tool as root** (libusb ≥ 1.0.25 can detach a kernel driver on macOS as root, or with the `com.apple.vm.device-access` entitlement, which needs Apple's approval). Works, but poor for a web-UI tool.
  3. **Custom PID in the EEPROM** (an FTDI-assigned PID under 0403, free on request, DS §7.2; or pid.codes). macOS then leaves it alone: libusb/pyftdi work unprivileged, D2XX via `FT_SetVIDPID`. **But on Windows** the FTDI driver from Windows Update only matches FTDI's standard PIDs, so the device gets no driver; a modified INF breaks FTDI's signature, and WinUSB needs Zadig (a user-installed INF). That trades a macOS problem for a Windows one.
- **Confidence:** high that the dext matches the device (plist). Now medium-high that option 1 carries FT1248 data correctly and that the latency timer can be controlled (code read). Throughput vs. R3 is still unmeasured; the bench test (FT232H module in 245 FIFO fed by a Pico PIO, `cat /dev/cu.usbserial-* | pv`) settles it and the libusb-coexistence question for ~$15.
- **Owner comment:** we talked about this in another thread and I think it's fine.

### R053 [Question] Host: which OS gets the "driverless" FT232H path, and is R5 still the requirement as written?
- **Evidence:** R5 (NOTES Requirements) says "no custom kernel drivers on macOS, Linux or Windows. That means vendor-class bulk with WinUSB/MS OS 2.0 descriptors, or CDC/NCM." The FT232H provides neither: its descriptors are fixed (no BOS/MS OS 2.0), and on Windows it relies on FTDI's own kernel driver (ftdibus.sys), which `design_docs/4-software/NOTES.md` already accepted because it installs from Windows Update. So R5 is already relaxed in practice on Windows, and the previous finding shows macOS needs a decision too.
- **Question:** (a) Update R5 to "no *user-installed* drivers: FTDI's Windows Update driver is OK", and (b) pick one macOS path: Apple serial node (test early), root, or a custom PID with a Windows-side cost. A bench test of option 1 on the first board (or on any FT232H module in FIFO mode now, for ~$15) would settle it cheaply.
- **Confidence:** n/a (owner's call).
- **Owner decision:** approved (2026-09-26)
- **Owner comment:** prefer MacOS. Yes I think R5 is still true.

### R054 [Info] Host: D2XX and the RP2350's interfaces on Windows
- **D2XX with FT1248:** FT1248 is selected in the EEPROM and moves data over the same bulk endpoints as the 245 FIFO, so `FT_Read`/`FT_Write` apply unchanged (the D2XX `FT_EEPROM_232H` structure has FT1248Cpol/Lsb/FlowControl fields). Use `FT_SetBitMode(0, 0x00)` (reset) only, never MPSSE/bit-bang modes (see the contention finding). Tune `FT_SetLatencyTimer` / `FT_SetUSBParameters` for throughput. **Unverified** on hardware; no FTDI document found that states FT1248 + D2XX explicitly.
- **RP2350 app side:** CDC ACM binds to inbox drivers on Windows 10+ (usbser.sys) and macOS; the pico-sdk reset interface carries MS OS 2.0 descriptors by default (see the bootstrap walk-through). Both meet R5 as written.
- **Custom PID and Windows:** FTDI's WHQL driver matches only FTDI's standard VID/PIDs; a custom PID needs an edited INF, which invalidates the signature (from memory: FTDI's driver-customisation notes; unverified wording).
- **Confidence:** medium.

### R055 [Low] USB: stale text in NOTES "FT232H pins in detail"
- **Evidence:** NOTES "FT232H pins in detail" still says "Async 245 FIFO, which is the mode we plan to use" and "FT1248 … Its throughput at each width is unverified (it's in AN_167, not yet downloaded)". AN_167 is in `reference/datasheets/` and FT1248 4-bit was decided 2026-09-24 (GPIO budget). Its EEPROM line ("`ftdi_eeprom` on macOS/Linux") also needs the caveats in the EEPROM-programming finding above.
- **Fix:** mark that section as "reference for the FIFO fallback" and point to the FT1248 decision.
- **Confidence:** high.
- **Owner decision:** approved (2026-09-26)

### R056 [Low] Docs: CS1 erratum number `[fixed]`
- **Evidence:** NOTES cited "RP2350-E15" for the CS1 re-pad. The RP2350 datasheet erratum about the bootrom's `connect_internal_flash()` ignoring the configured CS1 pin is **RP2350-E14** (datasheet p. 1356/1359). E15 is about `otp_access()`.
- **Fix:** NOTES corrected to E14.
- **Confidence:** high.
- **Owner decision:** approved (2026-09-26)

### R057 [Med] Power: bench eFuse EN/UVLO pin exceeds its 6.5 V absolute maximum with a 24 V adapter
- **Evidence:** String R1 510 k / R2 56 k / R3 150 k: EN tap = V_IN × 206/716 = 0.2877 × V_IN. At 12 V: EN 3.45 V (OK). At **24 V: EN 6.91 V**; at 28 V: 8.06 V. TPS25947 SLVSFC9C §6.1: V_EN/UVLO abs max **6.5 V** (reached at V_IN = 22.6 V); §6.3 recommended max 5 V (reached at 17.4 V). OVLO tap = 0.2095 × V_IN → 5.03 V at 24 V, 5.87 V at 28 V, inside its 6.5 V abs max. Any UVLO near 4.2 V forces the same EN ratio, so re-ratioing can't fix it. NOTES "Bench 5 V input protection" lists "a 12 V or 24 V adapter" as a design case.
- **Impact:** The one scenario the part was chosen for (24 V adapter) puts the EN pin 0.4 V above abs max through a 147 kΩ Thevenin source (~3 µA if an internal clamp exists; the datasheet shows none). Probably survives, but not by the datasheet.
- **Fix:** Clamp EN: a small Zener (≈5.1–5.6 V, SOD-323, basic) from EN/UVLO to GND. At normal input (EN ≈ 1.44 V) its leakage is negligible. With EN clamped at 5.6 V, OVLO = 4.1 V, so OV lockout still holds. Alternatively, split into separate EN and OVLO dividers with a clamp on EN only.
- **Confidence:** high on the arithmetic and ratings. Damage threshold unverified.
- **Owner decision:** approved (2026-09-26)
- **Owner comment:** use the zener

### R058 [Info] Power: bench eFuse thresholds recomputed (UV, OV, hysteresis, ILIM, dVdt)
- **Evidence (SLVSFC9C Eq. 1/2, §6.5):** V_UVLO(R) 1.183/1.20/1.223 V, V_UVLO(F) 1.076/1.09/1.116 V; OVLO has the same numbers. With 1 % resistors: **UV rising 4.17 V nom (4.05–4.31 V)**, UV falling 3.79 V nom (3.69–3.93 V). **OV rising 5.73 V nom (5.56–5.93 V)**, which matches NOTES. OV falling 5.20 V nom (**5.06–5.41 V**). R_ILM 1.5 k + 150 = 1650 Ω, which is exactly the datasheet row (1.800/2.028/2.200 A), so **1.78–2.22 A** incl. 1 % R. dVdt: Eq. 4 SR = 2000/2200 pF = 0.91 V/ms; I_dVdt 0.81/2.21/3.82 µA gives 0.33–1.57 V/ms, so a 5 V ramp takes 3.2–15 ms. Inrush into 47 µF ≤ 74 mA. The dVdt cap must be rated V_IN + 5 V (§6.3 note 3), i.e. ≥ 29 V for a 24 V case: C1531 is 50 V, OK. −15 V / 28 V ratings: §6.1 IN min max(−15, V_OUT − 21), max 28 V.
- **Note for USAGE.md:** after an OV trip the input must fall below 5.06–5.41 V to recover, so "turn the knob back down to 5.0 V". FLT does **not** report OV, UV or reverse polarity (Table 7-3: FLT stays H for those); it only reports over-temperature, persistent current limit and ILM faults. The expander's BENCH_FLT_N therefore can't say "bench supply rejected". If that diagnosis matters, AUXOFF (open-drain, high = input valid and inrush done, §7.3.10) is the right signal; it's currently unused.
- **Confidence:** high.

### R059 [Low] Power: reverse-polarity current into EN is ~25 µA; TI's §8.3 asks for < 10 µA
- **Evidence:** §6.1 note 2 / §6.3 note 2 say ≥ 350 kΩ pull-up (510 k meets it). §8.3 says pins derived from the input "must have a sufficiently large pull-up resistor to limit the current through those pins to < 10 µA during reverse polarity". At −15 V with EN clamped near −0.6 V: I = (15 − 0.6)/510 k − 0.6/206 k ≈ **25 µA**. (A 350 k pull-up would give ~41 µA, so TI's two statements disagree with each other.)
- **Impact:** Probably none; the NOTES claim "meets the reverse-polarity rule" is true only for the footnote version.
- **Fix:** Accept (document), or scale the string ×3 (≈1.5 M / 169 k / 453 k) at the cost of ~±1 % extra threshold error from the ±0.1 µA pin leakage.
- **Confidence:** med (clamp voltage assumed).
- **Owner decision:** approved (2026-09-26)
- **Owner comment:** I think scale the string

### R060 [Low] Power: bench input needs a specified input capacitor and bidirectional/no TVS for reverse polarity
- **Evidence:** SLVSFC9C §8.3.1: C_IN ≈ 1 µF ceramic rated ≥ 2× input voltage; §8.4 ≥ 0.1 µF at IN. §6.1 SR_IN(R) max 100 V/µs. The note under §8.3.1: "If there is a likelihood of input reverse polarity … use a bi-directional TVS". The DNP SMF15A is unidirectional: fitted, it forward-conducts on reversed leads and takes the supply's full current.
- **Impact:** Unspecified input cap means the 24 V case can ring past 28 V on hot-plug (Eq. 24), and a hot-plug edge can exceed 100 V/µs.
- **Fix:** Specify ≥ 1 µF 50 V X7R at the eFuse IN (plus 0.1 µF close). If the TVS footprint ever gets fitted, use the bidirectional SMF15CA or note that it sacrifices reverse protection.
- **Confidence:** high (datasheet text); ringing magnitude unverified.
- **Owner decision:** approved (2026-09-26)
- **Owner comment:** use the input capacitor

### R061 [Med] Power: bench OVLO (5.56–5.93 V) lets through voltages above the 5.5 V recommended maximum of LM66200, both TPS73701s and FT232H VREGIN, and above SCSI TERMPWR's 5.25 V
- **Evidence:** OV rising worst 5.93 V (above). LM66200 §6.3 VIN max 5.5 V (abs max 6 V). TPS737 §5.3 VIN max 5.5 V (abs max 6.0 V; V_OUT abs max 5.5 V). FT232H DS v2.0 Table 5.2 VREGIN (5 V mode) 3.6–5.5 V. SCSI-2 §5.4.3 VTerm 4.25–5.25 V; TERMPWR follows +5V_SYS minus ~50 mV. The OVLO response itself is fine: 1.2 µs (§6.6), and a hot-plugged 12/24 V adapter trips OVLO long before the dVdt ramp moves OUT.
- **Impact:** A bench supply at 5.5–5.9 V runs four parts outside their recommended range, leaves 70 mV to U1's and the LDOs' 6 V abs max, and puts up to ~5.9 V on TERMPWR. Not immediate damage; a spec-margin error in the "5.5 V bench setting is fine" claim.
- **Fix:** Lower OV to ≈ 5.40 V nominal (e.g. R3 up to ~160 k with R1/R2 re-trimmed; worst case ≈ 5.25–5.56 V), and state in USAGE.md "set the bench supply to 5.0–5.1 V". Or accept and document that 5.5 V is the absolute top setting and 5.0 V is the intended one.
- **Confidence:** high.
- **Owner decision:** approved (2026-09-26)
- **Owner comment:** 5.0-5.1 is achievable w/ bench supply.

### R062 [Med] Power: TERMPWR eFuse OVLO pin is driven to 3.3 V (recommended range 0.5–1.5 V)
- **Evidence:** SLVSFC9C §6.3: V_OVLO **0.5–1.5 V** recommended; §6.1 abs max 6.5 V. §6.5 I_OVLKG ±0.1 µA is specified only for 0.5 V < V_OVLO < 1.5 V. The enable node is pulled to 3.16–3.44 V (10 k to 3.3 V) when off. TI does allow logic drive in prose: pin table "can also be used as an Active Low Enable", §8.1.1 "EN/UVLO or OVLO can also be driven from the host GPIO". Low side: the node sits at 0–0.7 V (LM393 V_OL ≤ 0.4 V at 25 °C, ≤ 0.7 V over 0–70 °C, onsemi LM393/D p.3); §6.5 is characterised with V_OVLO = 0 V, so low is fine and 0.7 V < V_OV(F) min 1.076 V.
- **Impact:** Inside abs max, outside recommended; leakage in the high state is unspecified (the 10 k pull-up makes that irrelevant). Unlikely to fail, but it's the only non-datasheet operating point on the TERMPWR path.
- **Fix (if strict compliance wanted):** feed OVLO from the node through a divider that lands in 1.25–1.5 V at 3.16–3.44 V, e.g. 14.3 k over 10 k (ratio 0.412 → 1.30–1.42 V high, ≤ 0.29 V low). The node itself stays at 3.3 V for the expander and LED. Otherwise ask TI (E2E) and accept.
- **Confidence:** high on the numbers; the practical risk is low.
- **Owner decision:** approved (2026-09-26)
- **Owner comment:** divider sgtm

### R063 [Info] Power: TERMPWR eFuse settings recomputed
- **Evidence:** EN/UVLO 39 k/15 k: 1.20 × 54/15 = **4.32 V rising (4.20–4.47 V)**, falling 3.92 V nom (**3.82–4.08 V**). EN pin at 5.93 V in = 1.65 V (< 5 V recommended). R_ILM 2.4 k + 330 = 2730 Ω → 3334/2730 = **1.22 A**; using the nearest datasheet row (3.32 kΩ: 0.850/1.007/1.150 A, −15.6 %/+14.2 %) plus 1 % R: **1.02–1.41 A** (NOTES 1.06–1.39 A used a narrower interpolation; both satisfy ≥ 0.9 A and ≤ 1.5 A). Recovering from OVLO bypasses dVdt: confirmed, §7.3.3 "While recovering from a OVLO event, the TPS259470x variants bypass the inrush control (dVdt) and start up in a current limited manner", t_SWOV 90 µs (§6.6). Reverse blocking when unpowered: I_REVLKG(OFF) ≤ 4.86 µA at V_OUT = 12 V, V_IN = 0 (§6.5). Short-circuit: fast trip at 2 × I_LIM then foldback limit below V_OUT 1.9 V (§7.3.5.3 note 2, §6.5 V_FB). R_ILM node must stay < 50 pF (§7.3.6 note): layout.
- **Confidence:** high.

### R064 [Low] Power: TERMPWR eFuse FLT goes low whenever another device's TERMPWR is higher than ours (reverse-current blocking)
- **Evidence:** SLVSFC9C Table 7-3: "Reverse Current ((V_OUT − V_IN) > V_REVTH) → Reverse Current Blocking, FLT **L**". V_REVTH −22.3 to −36.5 mV (§6.5). Another initiator (e.g. the G4's Adaptec, or a target that supplies TERMPWR) at 5.0 V while our USB-fed +5V_SYS sits at 4.6 V triggers it.
- **Impact:** TERMPWR_FLT_N reports a "TERMPWR fault" that is really "someone else is supplying more". Firmware would mis-diagnose.
- **Fix:** Firmware rule: FLT low with TERMPWR_OK high and no over-temperature symptoms = reverse blocking, not a short. Document it in NOTES next to the existing "ignore FLT for a few ms after enable" rule.
- **Confidence:** high.
- **Owner decision:** approved (2026-09-26)
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

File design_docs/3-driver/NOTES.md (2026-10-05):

# Phase 3: Driver PCB (USB-C ↔ SCSI initiator)

Goal: a board that plugs into a modern computer over USB-C and acts as the SCSI
**initiator** for the D4000. It also serves as the **bus snooper**. The separate snooper PCB
was dropped on 2026-09-23: the G4, the scanner and this board share one multi-initiator
chain (see `design_docs/1-bus-capture/NOTES.md` for the topology).

## Requirements (draft)
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

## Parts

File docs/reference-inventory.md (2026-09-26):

# Reference inventory and leads

This is what's in `reference/` (untracked) and how useful each item is.
Where each item came from, and how to rebuild the folder, is in `sources.md`.
★ = high-value lead for Phase 2.

## D4000 / 4500: our scanner family (`reference/HOWTEK/`)

| Path | What | Notes / leads |
|---|---|---|
| `D4000_4500/Scanmaster 4500 Service Guide/*.pdf` | Scanned service guide, no OCR text | 02 theory, 03 boards, 04 troubleshooting and error table, 08 error enum, 09 training handouts (block diagrams, CPU types, calibration flow). Covers the 4500, which is nearly identical to the D4000 |
| `D4000_4500/Firmware/4000/R535.exe` | ★ Zip: `R535.HEX` (D4000 FLASH R535), `SL4HTK.EXE` (DOS softloader R3.07), `FLASH.BAT` | The HEX splits into 5 per-CPU images (see `scanner-facts.md`). Main target for disassembly: MP and IOC are 16-bit x86 |
| `D4000_4500/Firmware/4500/R813.exe` | Self-extracting zip: `R813.HEX` (4500 FLASH) | Same layout. Diffing against R535 may help |
| `D4000_4500/Field_Service_Tests_D4000_4500/` | ★ DOS FST v3.2 (`FST4000.EXE`, `FST4500.EXE`), `ASPI8DOS.SYS`, `ZD16.HEX`, `ZD32.HEX` | FST talks to the scanner over ASPI and has 48 tests. It **uploads a debug monitor (ZDebug) into the scanner** with MEMRD/MEMWR/IORD/IOWR commands. That could let us dump the EPROM code we don't have. The DOS binaries could run under DOSBox (no SCSI) or be disassembled |
| `D4000_4500/Howtek Utilities for Mac/HowtekStuff/` | ★ MacUtil 3.7 / 4.0 / 4.0.1 (68k, code in resource forks), ZDebug HEX files, `HSI.INI`, `R813.HEX` | MacUtil 4.x statically links Howtek's **HSI library** (`hsicd*` API) and a `HASPI` SCSI layer with a CDB name table. **`HSI.INI` has `[HASPI] CDB DUMP=` and `DEBUG`/`VERBOSE` flags that log to `HSIDEBUG.TXT`.** We can try enabling them on the G4 for a free software-side CDB log. MacUtil runs on the G4 |
| `D4000_4500/Howtek Utilities for Mac/HowtekStuff.zip` | Same content, with resource forks preserved in `__MACOSX/` | The portable copy of the Mac apps |
| `D4000_4500/MISC/` | Native-resolution table, aperture study, battery replacement (3.6 V lithium on the MB, BBRAM), sample scans | The BBRAM battery could be dead on old units: check it. The aperture study says 8000 ppi addressing works, which is interesting for custom software |

## Sibling scanners, lower priority (`reference/HOWTEK/`)

| Path | What | Notes |
|---|---|---|
| `7500/ScanMaster7500-ServiceGuide.pdf` | 198 pages, OCR'd | Different board set (MCP, IOC, IEC1/2, SCD) but the same firmware lineage. Its IOC is 8-bit SE, sync up to 10 MHz, and it has an RS-232 diagnostic port. Its power-on self-test list is useful |
| `7500/Firmware_R014/` | `R014.exe` (zip: `R014.BIN` 7500 flash, `README.TXT`), `Loading_Firmware.txt` (forum post: flashing the 7500 from Trident on a Mac, OS 9.2 G4), `Trident4.0r46Drum.hqx` (Aztek Trident 4 scanning app, Mac), `scsi22.sea.hqx` (**Howtek Mac SCSI driver 2.2**) | ★ Trident is a third-party app that drives Howteks, with the command usage embedded. The Howtek driver 2.2 is what MacUtil needs. BinHex: decode with `macbinary`/`binhex` tools |
| `8000/` | HR8000 FST and firmware updater (Win32 PE) | Probably packed/installer. Low priority |
| `HTSAI10.DLL` | **0 bytes**, a placeholder | Need a real copy if it matters (Howtek TWAIN/SAI?) |
| `aspi_471a2.exe` | Adaptec ASPI 4.71 (zip, includes `scsidefs.h`, `srb32.h`) | Generic. The headers are handy for decoding the DOS/Win tools |
| `MISC/` | Shipping instructions, drum checklist, community notes | Operational only |

## Standards (`reference/standards/`)

| Path | What | Notes |
|---|---|---|
| `SCSI-2_X3T9.2-375R_rev10L.pdf` | ★ SCSI-2 working draft X3T9.2/375R rev 10L (1993-09-07), the revision approved as ANSI X3.131-1994. Downloaded from t10.org (`ftp/x3t9.2/drafts/s2/s2-r10l.pdf`) | 502 pages. §5 covers the physical/electrical layer, §6 messages, §7 common commands, **§15 scanner devices** (the command set Phase 2 expects) |
| `SCSI-2_X3T9.2-375R_rev10L.txt` | The same draft as plain text (MIT SIPB mirror) | Easiest to grep. Section numbers match the PDF |

## Third-party projects (`reference/third-party/`)

| Path | What | Notes |
|---|---|---|
| `BlueSCSI-v2/` | Shallow clone of github.com/BlueSCSI/BlueSCSI-v2 @ `92db68f` (2026-08-22) | KiCad hardware (CERN-OHL-S v2) and RP2040/RP2350 firmware (GPL-3), including initiator mode and SDIO. Analysis: `design_docs/3-driver/prior-art/bluescsi-v2.md` |
| `BlueSCSI-v2_Desktop_50_Pin_schematic.pdf`, `…_netlist.xml` | Exported with `kicad-cli` 9.0 | The quickest way to read the front end |

## Datasheets (`reference/datasheets/`)

Downloaded 2026-09-24. A text dump (PyMuPDF) greps well; regenerate it in a scratch directory
rather than storing it here.

| Path | What | Notes |
|---|---|---|
| `rp2350-datasheet.pdf` | RP2350 datasheet (1380 pp), datasheets.raspberrypi.com | §5.1 bootrom concepts (partitions, A/B, try-before-you-buy), §5.8 UART boot, §3.5.8 rescue reset, PIO GPIOBASE, GPIO function table |
| `hardware-design-with-rp2350.pdf` | Raspberry Pi "Hardware design with RP2350" (25 pp) | Reference schematic: crystal, core regulator, flash, USB |
| `DS_FT232H.pdf` | FTDI FT232H datasheet **v2.0** (FT_000288). Mirrored from github.com/standardsemiconductor/VELDT-info, because ftdichip.com blocks scripted downloads. FTDI's current version is 2.3 (`ftdichip.com/wp-content/uploads/2025/11/DS_FT232H.pdf`); fetch it in a browser if a detail matters | §3.5 per-mode pin tables, §4.5 async FIFO timing, §4.6 FT1248, §4.8 MPSSE, EEPROM (93LC56B; the 93LC46B won't work) |
| `AN_167_FT1248-Parallel-Serial-Interface-Basics.pdf` | FTDI AN_167 v1.1 (2018), FT1248 basics | SCLK ≤ 30 MHz, 30 MB/s at 8-bit; 1/2/4/8-bit waveforms; internal pull-ups on MIOSIO |
| `tca9535.pdf`, `tca9555.pdf`, `tca6416a.pdf` | TI I²C 16-bit I/O expanders | Push-pull P-ports that power up as inputs. The TCA9555 adds 100 kΩ pull-ups. All three spec a P-port clamp for VO > VCC, so an unpowered expander pin clamps toward 0 V |
| `mcp23017.pdf` | Microchip MCP23017 I²C 16-bit I/O expander, DS20001952D | **GPA7/GPB7 are output-only** (a datasheet revision). Pins are limited to VDD + 0.6 V, with clamps to VDD. Two INT pins, interrupt-on-change, 1.7 MHz I²C |
| `tusb321.pdf` | TI TUSB321 USB Type-C CC logic (no I²C) | UFP thresholds 0.66 V (≥1.5 A) and 1.23 V (3 A). Open-drain OUT1 = low when the source advertises ≥1.5 A; OUT2 = low at 3 A. Powered from VBUS (4.5–5.5 V) |
| `lm66100.pdf` | TI LM66100 single ideal diode, 1.5 A | **When disabled, the body diode still conducts IN→OUT** (Table 1), so it can't switch a rail off |
| `lm66200.pdf` | TI LM66200 dual ideal diode, shared output, 2.5 A/ch, ~40 mΩ | ON high → VOUT Hi-Z (true off). Reverse blocking when VOUT > VINx. ST shows which input is in use. ON thresholds not specified |
| `tps737.pdf` | TI TPS737 1 A LDO, adjustable, reverse-current protection | 2.2–5.5 V in, ~130 mV dropout at 1 A, stable with 1 µF ceramic. Accuracy 1 % initial, 3 % overall (legacy silicon) / 1.5 % (new) |
| `CH334DS1_en.pdf` | WCH CH334/CH335, English V2.5 | Same content as the Chinese V2.91 for our purposes: §6.2 crystal-free warning, built-in crystal capacitor, CH334P pinout. Use this one for design review |
| `CH334.pdf` | WCH CH334/CH335 USB 2.0 HS 4-port hub (Chinese) | Variant table §1.2: CH334P/R are MTT, with crystal-free operation optional (built-in clock), an internal 5 V→3.3 V LDO, built-in pull-up/pull-downs, and no over-current detection |
| `FE1.1s.pdf` | Terminus FE1.1s USB 2.0 HS 4-port hub | Single TT, needs a 12 MHz crystal, 0–70 °C |

## Missing but useful (to acquire)

- The FT232H datasheet v2.3, fetched in a browser.

- The Windows Howtek HSI DLLs referenced by `HSI.INI` (`HCDD400.DLL`, `HCD4500.DLL`). Win32
  x86 decompiles far more easily than 68k.
- The D4000 User's Guide (P/N HTM092) and any Howtek SCSI programming reference.
- EPROM dumps for MP (U15), SSC (U10) and IOC (U29, U45). The boot and IOC low-level code may
  live partly in EPROM.
- The SilverFast Howtek plug-in, from the working G4 (its code shows the exact command usage).

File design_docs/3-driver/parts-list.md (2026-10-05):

# Driver board: schematic-ready parts list

Status: 2026-09-26, after the design review (`docs/design-review-2026-09-26.md`; finding IDs
like R006 point there). This file collects every part decided in `NOTES.md`, so drawing the
schematic is mostly placing parts. **`NOTES.md` holds the reasoning** (values and worst cases:
"Resistor and small-part values"); this file holds the list. When a decision changes, update both.

Columns:
- **Tier:** JLC library tier. **B** = basic, **P** = preferred (both carry no loading fee),
  **E** = extended (one loading fee per unique part per order).
- **Fit:** **JLC** = JLC assembles it; **Hand** = owner solders it (LCSC or own stock);
  **DNP** = footprint only.
- Stock was checked on 2026-09-24 (2026-09-26 for new parts). Check it again before ordering.

## 1. Power (`blocks/1-power.md`)

| Qty | Function | Part | LCSC | Tier | Fit | Notes |
|---|---|---|---|---|---|---|
| 1 | Bench 5 V terminal | 2-pin 5.08 mm screw terminal (Kangnex WJ500V-5.08-2P) | C8465 | E | Hand | Plus a test loop per pole (any 0.1" loop, hand-soldered) |
| 2 | Bench-input eFuse; TERMPWR switch | TI TPS259470ARPWR | C3662799 | E | JLC | Bench: OVLO 5.35 V, ILIM 2.22 A, UVLO 4.22 V, EN Zener. TERMPWR: OVLO (via 56 k/47 k) = active-low enable, ILIM 1.22 A, UVLO 4.32 V |
| 1 | Power mux U1 (bench priority) | TI TPS2116DRLR | C3235557 | E | JLC | **Replaces the LM66200 (C3235556), 2026-09-26 (R068).** VIN1 = bench eFuse out, VIN2 = VBUS, MODE = VIN1, PR1 100 k/39 k, ST → expander P11 |
| 2 | 3.3 V rail; terminator 2.83 V | TI TPS73701DCQR | C56848 | E | JLC | 3.3 V = 47 k / 27 k (+ DNP 0603 across R2). 2.83 V = (39 k + 5.6 k) / 33 k. EN = 100 k / 75 k from IN |
| 1 | CC detection | onsemi LM393DR2G | C7955 | B | JLC | Supply from 5 V; thresholds 0.661 V rising / 0.651 V falling; outputs drive the TERMPWR enable node |
| 1 | CC threshold reference | CJ431 (TL431-type) SOT-23 | C3113 | B | JLC | 2.500 V from 3.3 V through **470 Ω**. **No cap on the cathode.** Rank (0.5 % / 1 %) unknown: check the reel |
| 1 | Bench eFuse EN clamp | BZT52C5V6, SOD-123 | C19077402 | P | JLC | EN/UVLO to GND (R057) |
| 2 | USB-C Rd | 5.1 kΩ 1 % 0402 | C25905 | B | JLC | |
| 1 | Bench-present switch | 2N7002 SOT-23 | C8545 | B | JLC | Pulls the TERMPWR enable node low. Gate fed from the bench eFuse *output* (10 k / 100 k) |
| 1 | TERMPWR disable jumper | 1×2 2.54 mm header + shunt | — | — | Hand | |
| 1 | TERMPWR OUT negative-spike clamp | SS14, SMA | C2480 | B | DNP | Cathode on TERMPWR. Fit only if OUT dips below −0.8 V on the scope (leakage counts against the 1 mA TERMPWR budget) |
| 1 | VBUS ESD | SMF6.0A | C19077499 | P | JLC | (also listed under USB) |
| 1 | TERMPWR ESD | SMF6.0A | C19077499 | P | JLC | |
| 1 | Bench-terminal TVS | **SMF15CA** (bidirectional) | C19077510 | P | DNP | Footprint only. Bidirectional, so reversed leads don't forward-bias it (R060) |

### Power-rail capacitors (R097; details in NOTES "Power mux", "eFuse startup", "Power budget")

| Qty | Value | Part | LCSC | Tier | Where |
|---|---|---|---|---|---|
| 1 | 1 µF 50 V X7R 0805 | Samsung CL21B105KBFNNNE | C28323 | B | Bench eFuse IN (rated ≥ 2 × V_IN) |
| 8 | 1 µF 25 V X5R 0402 | | C52923 | B | Bench eFuse OUT (C105), TPS2116 VIN1 at the mux (C114, added 2026-10-04), TPS2116 VIN2, TERMPWR eFuse OUT, LDO C_IN ×2, CC filters ×2 (PSRAM 1 µF listed in §3) |
| 3 | 4.7 µF 25 V X5R 0805 | Samsung CL21A475KAQNNNE | C1779 | B | VBUS snubber, in series with the 1 Ω below; TERMPWR bulk ×2, one at each SCSI connector's TERMPWR pin (C307 at J301.26, C308 at J302.38, added 2026-10-04) |
| 1 | 1 Ω 1 % 0603 | | C22936 | B | VBUS snubber |
| 1 | 22 µF 25 V X5R 0805 | Samsung CL21A226MAQNNNE | C45783 | B | +5V_SYS bulk (TPS2116 VOUT) |
| 2 | 10 µF 25 V X5R 0805 | | C15850 | B | LDO outputs (3.3 V, 2.83 V) |
| 2 | 2.2 nF X7R 50 V 0402 | | C1531 | P | eFuse dVdt, bench and TERMPWR (~5.5 ms ramp) |
| 0 (2 DNP) | 0402 pad, ~1 nF if fitted | — | — | — | eFuse ITIMER, open by default |
| 1 | 270 Ω 1 % 0603 (100 mW) | | C22966 | B | Terminator-rail bleed (10.5 mA, 30 mW) |
| — | 100 nF 50 V X7R 0402 | | C307331 | B | Bench eFuse IN, TERMPWR eFuse IN, TPS2116 VOUT, LM393, TERMPWR ADC pin (counted in the decoupling total, §5) |

## 2. SCSI front end (`blocks/2-scsi-frontend.md`)

| Qty | Function | Part | LCSC | Tier | Fit | Notes |
|---|---|---|---|---|---|---|
| 1 | SCSI connector | 2×25 keyed box header, 2.54 mm (BOOMELE) | C30006 | E | Hand | LCSC MOQ 5. Footprint `IDC-Header_2x25_P2.54mm_Vertical`. Pin 25 unconnected |
| 1 | Alt SCSI connector | Half-pitch 50-pin female, right angle | — | — | DNP | Not stocked anywhere; owner sources later. TERMPWR = pin 38; pin 13 unconnected |
| 8 | RESERVED lines to GND | 0 Ω 0402 | C17168 | B | JLC | All four RESERVED lines (SCSI-2 §5.4.4), grounded at each connector: R337–R340 at IDC50 23/24/27/28, R1–R4 at HD50 12/37/14/39 (added during layout). Remove all eight if mid-chain. Was 2 (24/28 only) until 2026-09-26 |
| 3 | Terminator switches | TI SN74LVTH245APWR | C2652121 | E | JLC | **Only 939 at JLC.** A1–A8 and DIR tied to the 2.83 V rail, `/OE` = enable. 2 × 100 nF each: C301–C303, plus C304–C306 at VCC pin 20 (added 2026-10-04) |
| 36 | Terminator resistors | 220 Ω 1 % 0402 (UNI-ROYAL) | C25091 | B | JLC | **Two in parallel per line = 110 Ω** (R006), ≤ 35 mW each. Replaces 18 × 110 Ω C2909312 (extended, would run at 100–110 % of rating) |
| 1 | Terminator on/off | 2-position DIP switch, SMD (SHOU HAN) | C6331180 | E | JLC | DIP 1 = default, DIP 2 = firmware may override (see `USAGE.md`) |
| 18 | SCSI ESD | H5VUD5BB SOD-523, 0.3 pF | C20615820 | P | JLC | At the connector |
| 14 | SCSI drivers (open-drain) | onsemi FDV301N SOT-23 | C15310 | E | JLC | DB0–7, DBP, ATN, ACK, SEL, BSY, RST. GPIO high = asserted. Fallback: 4 × SN74LVTH125PWR (C7042), see NOTES "SCSI drivers" |
| 14 | Driver gate series R | 100 Ω 1 % 0402 | C25076 | B | JLC | Edge-rate tuning on the bench (0 Ω or larger) |
| 14 | Driver gate pull-down | 4.7 kΩ 1 % 0402 | C25900 | B | JLC | Keeps lines released with the board off or the MCU in reset. ≤ 8.2 kΩ required by RP2350-E9 (A2 silicon) |
| 14 | Driver gate cap | 22 pF C0G 0402 | C1555 | B | DNP | Fit only if the bus-edge kick shows on the bus edge (bench check, R037) |
| 18 | SCSI receivers | **Nexperia** 74LVC1G17GW,125 SOT-353 | C426705 | E | JLC | Nexperia only (other vendors' limits differ). 3.3 V. Fallback: 3 × Nexperia 74LVC14APW (C6066 / -Q100 C548122) |
| 18 | Receiver decoupling | 100 nF X7R 0402 | C307331 | B | JLC | One per 1G17 |
| 20 | LA tap series R | 100 Ω 1 % 0402 | C25076 | B | JLC | At each 1G17 output (18) and marker GPIO (2); the receivers are the Schmitt buffers, so no second bank |
| 1 | LA header | BOOMELE 2×17 2.54 mm keyed box header | C20920 | E | Hand | Pins 1–32 copy the Digital Discovery DIN connector (ref. manual Fig. 8); 33/34 spare. 34-way ribbon to a 2×16 adapter board. Signal order: `USAGE.md`. Replaces the 2×16 BH-00169 (C2685073), 2026-09-27 |

## 3. RP2350B and support (`blocks/3-mcu-support.md`)

| Qty | Function | Part | LCSC | Tier | Fit | Notes |
|---|---|---|---|---|---|---|
| 1 | MCU | Raspberry Pi RP2350B, QFN-80 | C42415655 | E | JLC | 4,296 at JLC. Plan for A4 silicon. Exposed pad = the only GND |
| 1 | Core-regulator inductor | Abracon AOTA-B201610S3R3-101-T, 3.3 µH | C42411119 | E | JLC | Polarity mark on the footprint |
| 4 | Regulator caps | 4.7 µF X5R 10 V 0402 | C23733 | B | JLC | CIN, COUT, VREG_AVDD, and a 2nd on DVDD pin 32 (R081). Fallback 0603 C19666 for CIN if DC bias is a problem |
| 1 | VREG_AVDD filter R | 33 Ω 1 % 0402 | C25105 | B | JLC | |
| 1 | 3.3 V bulk | 10 µF X5R 0805 | C15850 | B | JLC | Near the MCU |
| 1 | QSPI flash | Winbond W25Q128JVSIQ, 16 MB | C97521 | B | JLC | |
| 1 | PSRAM | AP Memory APS6404L-3SQR-SN, 8 MB | C5333729 | E | JLC | CS1 = GPIO 47. 100 nF + 1 µF (C52923) decoupling. Rated 2.7–3.6 V (LCSC's "3.3 V max" is wrong) |
| 1 | PSRAM CS1 pull-up | **3.3 kΩ** 0402 | C25890 | B | JLC | Was 10 kΩ (R079) |
| 1 | QSPI_SS pull-up | 10 kΩ 0402 | C25744 | B | DNP | Guide R1 is DNF |
| 1 | 12 MHz crystal | Abracon ABM8-272-T3 | C20625731 | E | JLC | Same part ×3 on the board (see USB) |
| 2 | Crystal load caps | 15 pF C0G 0402 | C1548 | B | JLC | |
| 3 | 1 kΩ | 1 kΩ 1 % 0402 | C11702 | B | JLC | Crystal series, BOOTSEL, RUN |
| 2 | BOOTSEL, RUN buttons | Through-hole 6 × 6 mm tact switches (footprint and C-number: HRO K2-1102DP) | C110153 | E | Hand | Owner's own switches; size to check against the footprint |
| 1 | microSD socket | SHOU HAN TF PUSH | C393941 | E | JLC | Card detect → expander. 10 µF (C15850) + 100 nF at the socket |
| 1 | I²C expander | TI TCA9555PWR | C465732 | E | JLC | INT to a test point only (firmware polls) |
| 1 | TERMPWR sense divider | 100 kΩ + 100 kΩ 0402 + 100 nF | C25741 | B | JLC | TERMPWR → GPIO 46 (ADC6), R066. (Resistors counted in §6) |
| — | SWD | Tag-Connect TC2030-IDC footprint (pads + clip holes, no part) | — | — | — | 1 VCC, 2 SWDIO, 3 RUN, 4 SWCLK, 5 GND, 6 NC. Owner buys a TC2030-IDC cable + ARM20-CTX adapter for the J-Link EDU |
| 8 | LEDs | KENTO KT-0603R red (C2286) ×3, KT-0805Y yellow (C2296) ×3, KT-0805G green (C2297) ×2 | — | B | JLC | Red: TERMPWR enable (D201), activity (D502), spare (D503). Yellow: TERMPWR present (D202, 10 k on TERMPWR), status (D501), spare (D504). Green: spare (D505) and hub active (D607, on the CH334's PGANG) through **470 Ω**: at 1–2 mA it needs only ~2.4 V (owner's curve; the 2.6–3.1 V spec is at 5 mA). Expander LEDs on P02–P06 |

## 4. USB path (`blocks/4-usb.md`)

| Qty | Function | Part | LCSC | Tier | Fit | Notes |
|---|---|---|---|---|---|---|
| 1 | USB-C receptacle | Owner's own; footprint HRO TYPE-C-31-M-12 | (C165948) | — | Hand | 16-pin USB 2.0. Shell to GND through a 0 Ω (§6) |
| 1 | USB hub | WCH CH334P | C5373042 | E | JLC | External 3.3 V mode. 10 µF (C15850) + 2 × 100 nF on V5/VDD33. RESET#: **no pull-up**; expander P14 via the Schottky below |
| 1 | Hub reset diode | 1N5819WS Schottky, SOD-323 | C191023 | B | JLC | Anode at CH334 RESET#, cathode at expander P14 (R031) |
| 1 | Hub crystal | ABM8-272-T3 | C20625731 | E | JLC | Load caps DNP (internal ~16 pF) |
| 1 | HS USB bridge | **FTDI FT232HL-REEL (LQFP-48)** | C51997 | E | JLC | $9.36. Same pinout as the QFN; the QFN (C82158) is out of stock. Powered per DS Fig. 6.2: VCCD makes its own 3.3 V (`FT232H_3V3`) |
| 1 | FT232H config EEPROM | Microchip 93LC56BT-I/OT, SOT-23-6 | C190271 | E | JLC | Required. VCC from FT232H_3V3. Program over USB after assembly (`USAGE.md`) |
| 1 | FT232H crystal | ABM8-272-T3 + 2 × 15 pF | C20625731, C1548 | E, B | JLC | |
| 1 | FT232H REF | 12 kΩ 1 % 0402 | C25752 | B | JLC | REF to GND (R017) |
| 2 | FT232H VPHY/VPLL ferrites | Sunlord GZ1608D601TF, 600 Ω @ 100 MHz, 0603 | C1002 | B | JLC | From FT232H_3V3 |
| 2 | FT232H VREGIN, VCCD bulk | 4.7 µF X5R 10 V 0402 | C23733 | B | JLC | + 2 DNP 4.7 µF pads on VPHY/VPLL |
| 10 | FT232H decoupling | 100 nF X7R 0402 | C307331 | B | JLC | VREGIN, VCCD, VCCIO ×3, VPHY, VPLL, VCCA, VCORE, EEPROM |
| 1 | FT232H RESET# cap | 10 nF X7R 50 V 0402 | C15195 | B | JLC | With the 10 kΩ pull-up to FT232H_3V3 |
| 1 | FT232H EEPROM DO → DI | 2.2 kΩ 1 % 0402 | C25879 | B | JLC | Plus a 10 kΩ DO pull-up (§6) |
| 7 | FT1248 series R | 33 Ω 1 % 0402 | C25105 | B | JLC | At the RP2350 end (R021) |
| 2 | RP2350 USB series R | 27 Ω 1 % 0603 | C25190 | P | JLC | Close to the RP2350 |
| 2 | USB D± ESD | H5VUD5BB | C20615820 | P | JLC | |
| 2 | CC ESD | H7VL10B DFN1006 | C20615787 | P | JLC | |

## 5. Decoupling totals (100 nF X7R 50 V 0402, C307331)

14 (RP2350B ×13: IOVDD ×8, DVDD ×3, ADC_AVDD, USB_OTP+QSPI_IOVDD shared; + flash ×1; was miscounted as 13 until 2026-09-26) + 18 (1G17) + 10 (FT232H) + 6 ('245, two each) + 2 (CH334)
+ 1 (TCA9555) + 1 (PSRAM) + 1 (microSD) + 1 (LM393) + 3 (bench IN, TERMPWR IN, TPS2116 VOUT)
+ 1 (TERMPWR ADC pin) = **58**.

## 6. Resistors and small parts (values and reasoning: NOTES "Resistor and small-part values")

All 1 % 0402, no loading fee, unless noted. Rows above that already list a part (gate 100 Ω,
LA 100 Ω, 220 Ω terminators, 33 Ω, 12 k, 2.2 k, 3.3 k CS1, …) aren't repeated.

| Qty | Value | LCSC | Tier | Where |
|---|---|---|---|---|
| 1 | 47 kΩ | C25792 | B | 3.3 V LDO R1 |
| 1 | 27 kΩ | C25771 | P | 3.3 V LDO R2 (+ 1 DNP 0603 pad in parallel for trim, R030) |
| 1 | 39 kΩ + 1 × 5.6 kΩ | C25783, C25908 | P, P | 2.83 V LDO R1 (in series) |
| 1 | 33 kΩ | C25779 | B | 2.83 V LDO R2 |
| 2 | 75 kΩ | C25798 | P | LDO EN dividers (bottom) |
| 6 | 100 kΩ | C25741 | B | LDO EN dividers (top) ×2, TPS2116 PR1 top, bench-FET gate pull-down, TERMPWR ADC divider ×2 |
| 1 | 510 kΩ | C11616 | P | Bench eFuse string R1 (only ~8.5k in stock; fine at our volume) |
| 1 + 1 | 39 kΩ + 3.9 kΩ | C25783, C51721 | P, P | Bench eFuse string R2 = 42.9 k |
| 1 + 1 | 150 kΩ + 10 kΩ | C25755, C25744 | P, B | Bench eFuse string R3 = 160 k |
| 1 | 1.5 kΩ | C25867 | B | Bench eFuse R_ILM (2.22 A) |
| 1 | 39 kΩ | C25783 | P | TERMPWR eFuse UVLO top |
| 1 | 15 kΩ | C25756 | P | TERMPWR eFuse UVLO bottom |
| 1 + 1 | 2.4 kΩ + 330 Ω | C25882, C25104 | P, B | TERMPWR eFuse R_ILM (1.22 A) |
| 1 | 56 kΩ | C25796 | P | TERMPWR OVLO divider top (node → OVLO) |
| 1 | 47 kΩ | C25792 | B | TERMPWR OVLO divider bottom |
| 1 | 39 kΩ | C25783 | P | TPS2116 PR1 bottom |
| 18 | 10 kΩ | C25744 | B | Terminator /OE pull-up (to 2.83 V); enable-node pull-up; CC filters ×2; CC ref top (with 3.3 k); bench-FET gate series; SDIO pull-ups ×5; FT232H RESET#; FT232H EEPROM DO; FT232H WR#, SIWU# ×2; expander INT; TPS2116 ST; TERMPWR-present LED |
| 1 | 3.3 kΩ | C25890 | B | CC reference top (10 k + 3.3 k = 13.3 k) |
| 3 | 4.7 kΩ | C25900 | B | CC reference bottom; I²C SDA/SCL |
| 1 | 1 MΩ | C26083 | B | CC hysteresis |
| 3 | 470 Ω | C25117 | B | CJ431 bias (was 510 Ω, R087); green LEDs ×2 |
| 6 | 1 kΩ | C11702 | B | 3.3 V LEDs ×5 (TERMPWR enable, status, activity, spare red, spare yellow); terminator DIP 1 pull-down |
| 15 | 0 Ω | C17168 | B | FT1248 rework links: 5 fitted (GPIO 42–45, 34 → I²C/SD); RESERVED ×8 (§2); USB-C shell ×1; HD50 shell ×1 |
| 5 | 0 Ω 0805 | C17477 | B | FT1248 rework links, DNP (FT232H pins 17–20, 27). 0805 so they're easy to hand-solder at rework (owner, 2026-09-27) |

Dropped on 2026-09-26: 110 Ω C2909312 (→ 2 × 220 Ω), 20 kΩ and 15 kΩ of the old 2.80 V divider,
56 k/150 k/150 Ω of the old bench string (56 k now used for the OVLO divider, 150 k kept),
22 k/33 k TERMPWR_OK divider, 6.8 kΩ LED resistor, 510 Ω CJ431 bias, 10 kΩ CH334 reset
pull-up, LM66200 C3235556.

## Loading fees (extended parts JLC assembles)

16 unique extended parts: RP2350B, FT232HL, CH334P, 93LC56B, APS6404L, ABM8-272-T3, Abracon
inductor, TPS73701, TPS259470A, TPS2116 (replaced the LM66200: no change in count), TCA9555,
SN74LVTH245A, microSD socket, DIP switch, FDV301N, 74LVC1G17. The extended 110 Ω is gone (R006).
JLC's fee is a few dollars per unique extended part per order (from memory: check the current
rate). Parts that appear several times on the board cost one fee.

## Still open before the schematic is complete

1. ~~SCSI drivers and receivers~~: decided 2026-09-25 (FDV301N, Nexperia 74LVC1G17GW).
2. ~~LA header pinout~~: decided 2026-09-26, a copy of the Digital Discovery DIN connector (NOTES log).
3. ~~SWD connector style~~: decided 2026-09-25, Tag-Connect TC2030-IDC footprint.
4. ~~Resistor values~~: decided 2026-09-25, revised 2026-09-26 after the design review.
5. The owner's button size and USB-C part, to confirm the footprints.
6. ~~TPS2116 datasheet~~: in `reference/datasheets/tps2116.pdf` (2026-09-26).
7. Test points: +5V_SYS, 3.3 V, 2.83 V, TERMPWR, FT232H_3V3, GND, TCA9555 INT, TERMPWR_EN_INVERTED,
   expander P15–P17. The bench-input test loops (TP101/TP102) were dropped during layout.

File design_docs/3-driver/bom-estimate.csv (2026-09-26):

Block | Function | Part | LCSC | Tier | Fit | Qty/board | Unit USD | Ext USD/board | Notes
Power | Bench 5V screw terminal | Kangnex WJ500V-5.08-2P | C8465 | E | Hand | 1 | 0.15 | 0.15
Power | eFuse (bench, TERMPWR) | TI TPS259470ARPWR | C3662799 | E | JLC | 2 | 1.28 | 2.56
Power | Power mux (bench priority) | TI TPS2116DRLR | C3235557 | E | JLC | 1 | 0.4 | 0.4 | Replaced LM66200 C3235556 (review R068)
Power | LDO 3.3V / 2.83V term | TI TPS73701DCQR | C56848 | E | JLC | 2 | 1.1 | 2.2
Power | CC comparator | onsemi LM393DR2G | C7955 | B | JLC | 1 | 0.07 | 0.07
Power | CC reference | CJ431 SOT-23 | C3113 | B | JLC | 1 | 0.03 | 0.03
Power | Bench-present FET | 2N7002 | C8545 | B | JLC | 1 | 0.02 | 0.02
Power | TERMPWR disable jumper | 1x2 2.54mm header + shunt |  |  | Hand | 1 | 0.1 | 0.1
SCSI | SCSI connector | BOOMELE 2x25 box header | C30006 | E | Hand | 1 | 0.2 | 0.2
SCSI | Alt HD50 connector | Half-pitch 50-pin RA |  |  | DNP | 0 | 0 | 0
SCSI | Terminator switch | TI SN74LVTH245APWR | C2652121 | E | JLC | 3 | 1.08 | 3.24
SCSI | Terminator R 2x220R per line | UNI-ROYAL 0402 1% 220R | C25091 | B | JLC | 36 | 0.0034 | 0.1224 | Replaced 18x110R C2909312 (review R006)
SCSI | Terminator DIP switch | SHOU HAN 2P SMD DIP | C6331180 | E | JLC | 1 | 0.47 | 0.47
SCSI/USB | ESD 0.3pF (18 SCSI + 2 D+/-) | H5VUD5BB SOD-523 | C20615820 | P | JLC | 20 | 0.042 | 0.84
Power/USB | TVS TERMPWR + VBUS | SMF6.0A | C19077499 | P | JLC | 2 | 0.03 | 0.06
USB | CC ESD | H7VL10B DFN1006 | C20615787 | P | JLC | 2 | 0.03 | 0.06
Power | Bench TVS | SMF15CA (bidirectional) | C19077510 | P | DNP | 0 | 0 | 0 | DNP
SCSI | Driver NMOS | onsemi FDV301N | C15310 | E | JLC | 14 | 0.037 | 0.518
SCSI | Receiver Schmitt buffer | Nexperia 74LVC1G17GW,125 | C426705 | E | JLC | 18 | 0.11 | 1.98
SCSI | Driver gate cap 22pF | C0G 0402 | C1555 | B | DNP | 0 | 0 | 0
SCSI | LA header | 2x16 2.54mm pin header | C124382 | E | Hand | 1 | 0.15 | 0.15
MCU | MCU | Raspberry Pi RP2350B | C42415655 | E | JLC | 1 | 1.28 | 1.28
MCU | Core reg inductor 3.3uH | Abracon AOTA-B201610S3R3-101-T | C42411119 | E | JLC | 1 | 0.28 | 0.28
MCU | QSPI flash 16MB | Winbond W25Q128JVSIQ | C97521 | B | JLC | 1 | 2.55 | 2.55
MCU | PSRAM 8MB | AP Memory APS6404L-3SQR-SN | C5333729 | E | JLC | 1 | 3.96 | 3.96
MCU/USB | 12 MHz crystal (x3) | Abracon ABM8-272-T3 | C20625731 | E | JLC | 3 | 0.62 | 1.86
MCU | microSD socket | SHOU HAN TF PUSH | C393941 | E | JLC | 1 | 0.07 | 0.07
MCU | I2C expander | TI TCA9555PWR | C465732 | E | JLC | 1 | 0.73 | 0.73
MCU | LEDs | KENTO KT-0603R red | C2286 | B | JLC | 4 | 0.01 | 0.04
MCU | BOOTSEL/RUN buttons | Owner TH tact switch |  |  | Hand | 2 | 0 | 0
USB | USB-C receptacle | HRO TYPE-C-31-M-12 (owner stock) | C165948 |  | Hand | 1 | 0 | 0
USB | USB hub | WCH CH334P | C5373042 | E | JLC | 1 | 0.44 | 0.44
USB | HS USB bridge | FTDI FT232HL-REEL | C51997 | E | JLC | 1 | 9.36 | 9.36
USB | FT232H EEPROM | Microchip 93LC56BT-I/OT | C190271 | E | JLC | 1 | 0.44 | 0.44
USB | RP2350 USB series 27R | 0603 1% | C25190 | P | JLC | 2 | 0.005 | 0.01
Passive | 100nF X7R 0402 | decoupling (see parts-list §5) | C307331 | B | JLC | 54 | 0.003 | 0.162
Passive | 4.7uF X5R 0402 | RP2350 regulator x4, FT232H VREGIN/VCCD | C23733 | B | JLC | 6 | 0.01 | 0.06
Passive | 1uF X5R 0402 | CC filters, PSRAM, eFuse/mux/LDO in-out | C52923 | B | JLC | 8 | 0.005 | 0.04
Passive | 10uF X5R 0805 | 3.3V bulk, LDO outs x2, CH334, microSD | C15850 | B | JLC | 5 | 0.01 | 0.05
Passive | 15pF C0G 0402 | crystal load caps | C1548 | B | JLC | 4 | 0.002 | 0.008
Passive | 2.2nF X7R 0402 | eFuse dVdt | C1531 | P | JLC | 2 | 0.002 | 0.004
Passive | ALLOWANCE: caps not yet listed | (now itemised; small margin) | C307331 etc | B | JLC | 5 | 0.01 | 0.05
Passive | 100R 0402 | gate series (14) + LA taps (20) | C25076 | B | JLC | 34 | 0.001 | 0.034
Passive | 4.7k 0402 | gate pull-downs (14) + CC ref/I2C (3) | C25900 | B | JLC | 17 | 0.001 | 0.017
Passive | 10k 0402 | pull-ups etc | C25744 | B | JLC | 18 | 0.001 | 0.018
Passive | 1k 0402 | xtal/BOOTSEL/RUN/LEDs | C11702 | B | JLC | 6 | 0.001 | 0.006
Passive | 5.1k 0402 | USB-C Rd | C25905 | B | JLC | 2 | 0.001 | 0.002
Passive | Misc single-value 0402 R | 47kx2 27k 39kx4 5.6k 33k 75kx2 100kx6 510k 3.9k 150k 1.5k 2.4k 330R 56k 15k 3.3kx2 1M 470R 12k 2.2k 33Rx8 | various | B/P | JLC | 44 | 0.002 | 0.088
Passive | 0R links | FT1248 rework 5 fit + 5 DNP; RESERVED x2; USB shell | C17168 | B | JLC | 8 | 0.001 | 0.008
Power | Bench EN clamp Zener | BZT52C5V6 SOD-123 | C19077402 | P | JLC | 1 | 0.017 | 0.017 | review R057
Power | TERMPWR OUT spike clamp | SS14 SMA | C2480 | B | DNP | 0 | 0 | 0 | fit only if needed
Power | Bench IN cap 1uF 50V | Samsung CL21B105KBFNNNE 0805 | C28323 | B | JLC | 1 | 0.04 | 0.04
Power | VBUS snubber C 4.7uF 25V | Samsung CL21A475KAQNNNE 0805 | C1779 | B | JLC | 1 | 0.035 | 0.035 | review R074
Power | VBUS snubber R 1R | 0603 1% | C22936 | B | JLC | 1 | 0.003 | 0.003
Power | +5V_SYS bulk 22uF 25V | Samsung CL21A226MAQNNNE 0805 | C45783 | B | JLC | 1 | 0.22 | 0.22
Power | Terminator bleed 270R | 0603 1% | C22966 | B | JLC | 1 | 0.003 | 0.003 | review R042/R086
USB | FT232H VPHY/VPLL ferrite | Sunlord GZ1608D601TF | C1002 | B | JLC | 2 | 0.013 | 0.026 | review R016
USB | FT232H RESET# cap 10nF | 0402 X7R | C15195 | B | JLC | 1 | 0.005 | 0.005
USB | CH334 reset Schottky | 1N5819WS SOD-323 | C191023 | B | JLC | 1 | 0.014 | 0.014 | review R031

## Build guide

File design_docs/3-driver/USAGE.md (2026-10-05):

# Driver board: usage notes

How to set up and use the board. Design reasoning lives in `NOTES.md`.

## Termination switch

The board has a switchable active terminator. Terminate the board only when it is at a
physical end of the SCSI chain. The bus needs exactly two terminators, one at each end.

| DIP 1 | DIP 2 | Terminator |
|---|---|---|
| off | off | off, fixed |
| off | on | off by default; firmware can turn it on |
| on | off | on, fixed |
| on | on | on by default; firmware can turn it off |

- **End of chain (the usual setup):** use DIP 1 on (10 or 11). With DIP 2 off, the
  terminator stays on even when the board is unpowered, as long as TERMPWR is on the bus.
- **Mid-chain:** use off, fixed (00).
- **Caution for 01 (off by default, firmware may turn it on):** if the board is unpowered
  while another device supplies TERMPWR, the terminator can switch on by itself. Mid-chain,
  that gives the bus three terminators, which usually still works but can make transfers
  flaky. It doesn't damage anything. If the board is mid-chain and might be off, use 00.

The firmware-controlled positions (DIP 2) need the I²C GPIO expander, which is fitted as
standard. It is removed only in the FT1248/FIFO rework fallback; after that, DIP 2 does nothing.

## Logic-analyzer header (J303)

J303 is a 2×17 box header. Pins 1–32 copy the Digital Discovery's 2×16 DIN connector pin for
pin, so a ribbon to the analyzer needs no rewiring; pins 33/34 are spare. Each signal is the
3.3 V output of that line's receiver through 100 Ω. The receivers are non-inverting and the
SCSI bus is active-low, so **a tap reads low while its line is asserted**. MARKER0/1 are
driven by firmware (GPIO 33/32).

The signals are not in bus order: they were arranged during layout to suit the routing. Name
the channels in WaveForms from this table (source: `pcb/_gen/sheet_3_scsi.py`, `LA_PIN`).

| Channel | J303 pin | Signal |
|---|---|---|
| DIN0 | 29 | CD |
| DIN1 | 27 | IO |
| DIN2 | 25 | MSG |
| DIN3 | 23 | ATN |
| DIN4 | 30 | REQ |
| DIN5 | 28 | RST |
| DIN6 | 26 | SEL |
| DIN7 | 24 | BSY |
| DIN8 | 19 | ACK |
| DIN9 | 17 | DB7 |
| DIN10 | 15 | DB3 |
| DIN11 | 13 | DB5 |
| DIN12 | 20 | DB6 |
| DIN13 | 18 | DBP |
| DIN14 | 16 | DB4 |
| DIN15 | 14 | DB0 |
| DIN16 | 9 | DB1 |
| DIN17 | 7 | DB2 |
| DIN18 | 5 | MARKER1 |
| DIN19 | 3 | MARKER0 |
| DIN20 | 10 | not connected |
| DIN21 | 8 | not connected |
| DIN22 | 6 | not connected |
| DIN23 | 4 | not connected |

Ground is on pins 1, 2, 11, 12, 21, 22, 31 and 32.

## Power

- **USB-C is always connected**: it's the data link. On a port that offers ≥ 1.5 A (USB-C
  current advertisement), the board also supplies TERMPWR from USB.
- **Bench supply for extra current:** connect a 5 V supply to the screw terminal when the USB
  port can't do 1.5 A (e.g. a 500 mA port). While it's present, the bench supply powers the
  whole board, TERMPWR included; USB then carries data only.
  - Set it to **5.0 V** (5.1 V at most) and at least a 2.5 A current limit. The board's
    over-voltage cut-off is 5.14–5.59 V, and above it the bench input shuts off until the
    voltage drops below ~4.9 V.
  - Reversed leads and adapters up to 24 V are survivable, but don't try them on purpose.
  - Switch the bench supply off before switching off or sleeping the computer. With the bench
    on and the host off, the hub's D+ pull-up feeds a small current into the powered-down host
    (a known minor flaw).
- **Cables:** use a USB-C to C cable. A legacy USB-A to C cable reads as "default current", so
  TERMPWR stays off unless the bench supply is connected. A *non-compliant* A-to-C cable (10 kΩ
  pull-up) reads as 3 A and could overload a USB-A port: avoid unknown cables.
- The board draws ~0.2 A while the host has the USB bus suspended (outside the USB suspend
  limit, like most bus-powered hubs).

## First programming (fresh board)

1. **RP2350:** plug in USB-C. With blank flash the RP2350 comes up in its ROM bootloader
   (BOOTSEL) behind the on-board hub. Copy a UF2 onto the `RP2350` drive, or use
   `picotool load -x firmware.uf2`. Later updates: `picotool reboot -f -u`, then load. If USB
   doesn't work, use SWD (Tag-Connect TC2030 + J-Link) or hold BOOTSEL while pressing RUN.
2. **FT232H EEPROM** (93LC56B, blank from the factory; the FT232H can't be bricked by bad
   EEPROM contents, it falls back to defaults on a bad checksum):
   - Easiest: on a Windows PC, run FTDI's FT_PROG once: port A type **FT1248**, FT1248 clock
     polarity / bit order / flow control per the firmware, "Suspend on ACBus7 Low" **off**,
     self-powered, max power ~100 mA. Program, then save the 256-byte image.
   - From macOS: write the saved image with libftdi's `ftdi_eeprom` (`flash_raw = true`,
     `eeprom_type = 0x56`), run as root (Apple's built-in FTDI driver holds the interface).
     `ftdi_eeprom` can't set the FT1248 option bits itself, only the mode.
   - Check on the bench: with SS_n high and flow control on, MISO follows RXF# and MIOSIO0
     follows TXE#.
3. The firmware leaves the FT1248 pins as inputs until it has confirmed FT1248 mode.

## Bring-up checks (first board)

- 3.3 V rail under load (SD write + TERMPWR on): 3.20–3.40 V. If low, fit a resistor on the
  unfitted 0603 pads across the LDO's lower feedback resistor (1 MΩ raises it ≈ 55 mV).
- Terminator rail 2.72–2.94 V; scope it during G4 captures.
- VBUS at plug-in (no ringing above ~5.8 V at the mux input).
- TERMPWR at the connector under full load with your usual cable (≥ 4.25 V), and TERMPWR at
  plug-in on a 500 mA port (should show no pulse).
- Bench input: under-voltage trip ≈ 4.05–4.41 V and over-voltage trip ≈ 5.14–5.59 V (checks
  the EN Zener's leakage).
- '245 output resistance on one line (open vs. ~21 mA load). If > 22 Ω, change that line's
  resistors to 100 Ω.
- REQ ringing at the connector; data-to-ACK setup at the connector (≥ 55 ns; the firmware
  gives ~107 ns).
- Receiver thresholds: sweep one input slowly at the real 3.3 V.
- Driver gate kick with the board off while the G4 drives the bus: fit the 22 pF gate caps
  only if it shows on the bus edge.

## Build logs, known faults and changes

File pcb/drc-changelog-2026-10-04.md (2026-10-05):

# Via standardization and DRC cleanup, 2026-10-04

> **Superseded later the same day.** This records the state after the via and DRC cleanup only.
> The board has changed since: the D607 / C602 courtyard overlap is resolved, silkscreen
> warnings dropped from 311 to 7 (connector outlines over the board edge), four 0.8/0.4 vias
> are back on VBUS and +5V_SYS, and the pre-order review fixes are in. See the 2026-10-04
> entries in `design_docs/3-driver/NOTES.md`. Re-run DRC for current numbers.

Only `scsi-adapter.kicad_pcb` changed. Nothing is committed; `git diff` shows it all and
`git checkout pcb/scsi-adapter.kicad_pcb` undoes it. Most of the diff's line count is zone refill.

DRC (`kicad-cli pcb drc --schematic-parity --severity-all`, KiCad 9.0.9):

| | Before | After |
|---|---|---|
| Errors | 4 | 1 |
| Non-silkscreen warnings | 7 | 0 |
| Silkscreen warnings | 311 | 311 |
| Unconnected items | 0 | 0 |
| Schematic parity issues | 0 | 0 |

## 1. Vias

Standard is the Default net class size, 0.6 mm pad / 0.3 mm drill (434 of 455 vias already).

| Change | Net | Location (x, y mm) |
|---|---|---|
| 0.8/0.4 → 0.6/0.3 (15 vias) | VTERMINATOR | y = 72.5 at x = 162.6, 163.9, 165.2, 178.7, 180, 181.3, 182.6, 192.9, 194.3, 195.6, 196.9; y = 75.1 at x = 168.2, 183.196, 197.7; (168.2, 71.7) |
| 0.8/0.4 → 0.6/0.3 | GND | (194.7, 50.1) |
| 0.5/0.3 → 0.6/0.3 | GND | (160.1, 72.0) |
| **left at 0.5/0.3** (2 vias) | GND | (146.861, 62.394), (146.436, 62.818) |
| **left at 0.5/0.3** (2 vias) | /rp2350/DVDD_1V1 | (147.957, 64.692), (148.381, 64.268) |

- **VTERMINATOR group: please check.** All 15 sat in tidy rows under U301–U303, so they may have
  been deliberately larger. The other two VTERMINATOR vias and every +3V3 / TERMPWR via were
  already 0.6/0.3, so I standardized them. To restore: select them, Properties, pick the 0.8/0.4 preset.
- **The four left at 0.5/0.3** are two pairs by the RP2350 regulator at 0.6 mm pitch. At 0.6 mm the
  pads are exactly tangent, which gave four new "copper connection too narrow" warnings (0.079 mm)
  on B.Cu, In1.Cu and In2.Cu. I tried it, then put them back. Making them standard needs the pairs
  spread to about 0.75 mm pitch or more, which is a layout change.

## 2. DRC fixes

| # | Violation | Fix |
|---|---|---|
| 1 | Clearance 0.0005 mm and hole clearance 0.15 mm: GND via (200.3, 62.0) vs L3 +3V3 plane | Refilled all zones. The fill was stale; nothing moved. |
| 2 | Zones intersect: two "L3 +5V_SYS west-edge power-entry pour" zones on In2.Cu, both priority 1, sharing the edge at x = 112 | Merged into one L-shaped zone (kept UUID ccc15412, deleted 2267c869). Outline: (99.95, 29.95) (220.05, 29.95) (220.05, 34.15) (112, 34.15) (112, 120.05) (99.95, 120.05). Same settings. The old top strip had slightly skewed corners, (220, 30) and (112, 34.1); these are now square. |
| 3 | Co-located holes: two +3V3 vias at (187.4, 58.2) | Deleted one (b918f0d4). |
| 4 | Dangling track /ACK_RX, F.Cu, 0.0007 mm at (181.2018, 85.0605) | Deleted stub. |
| 5 | Dangling track /DB1_RX, F.Cu, 0.014 mm at (144.725, 89.455) | Deleted stub. |
| 6 | Dangling track /rp2350/QSPI_SD3, F.Cu, 0.246 mm, (146.684, 70.632) → (146.858, 70.458) | Deleted stub. |
| 7 | Dangling track /rp2350/QSPI_SS_INVERTED, F.Cu, 0.222 mm, (151.649, 65.949) → (151.492, 66.106) | Deleted stub. |
| 8 | Dangling track /scsi/TERMINATOR_OUT_MSG, B.Cu, 0.045 mm at (196.279, 81.5) | Deleted stub. |
| 9 | Dangling track /scsi/TERMINATOR_EN_INVERTED, In2.Cu | **Please check.** Removed an 8.9 mm dead-end tail: the In2 track along y = 77 ran past the via at (198.375, 77) to (200.075, 77), then up to (200.075, 72.917), (199.4, 72.242), and stopped at (199.4, 69.0) with nothing there. Trimmed the y = 77 track to end at the via and deleted the three segments beyond it. All six pads on the net (U301/U302/U303 pin 19, R341, SW301) are still connected. If that tail was heading for something not placed yet, it needs rerouting. |

Zones were refilled after each round of edits.

## 3. Not fixed

- **Courtyard overlap, D607 / C602 (error).** They overlap by about 0.05 mm at (112.4, 73–74.4).
  The column is packed: D601 above D607 and C601 below C602 have about 0.03 mm of slack in total,
  so no nudge clears it. One of the parts has to move sideways and be rerouted. The pads
  themselves are about 0.39 mm apart.
- **Silkscreen, 311 warnings, untouched.** Reference designators have not been placed yet:
  - 103 "clipped by solder mask": a reference sits on a pad.
  - 199 "overlap": a reference over another part's outline or reference.
  - 9 "clipped by board edge": the J101, J302, J501, J601 outlines overhang the edge (normal for
    edge connectors), and the H1 / H2 references sit at y = 29.85, just off the board.

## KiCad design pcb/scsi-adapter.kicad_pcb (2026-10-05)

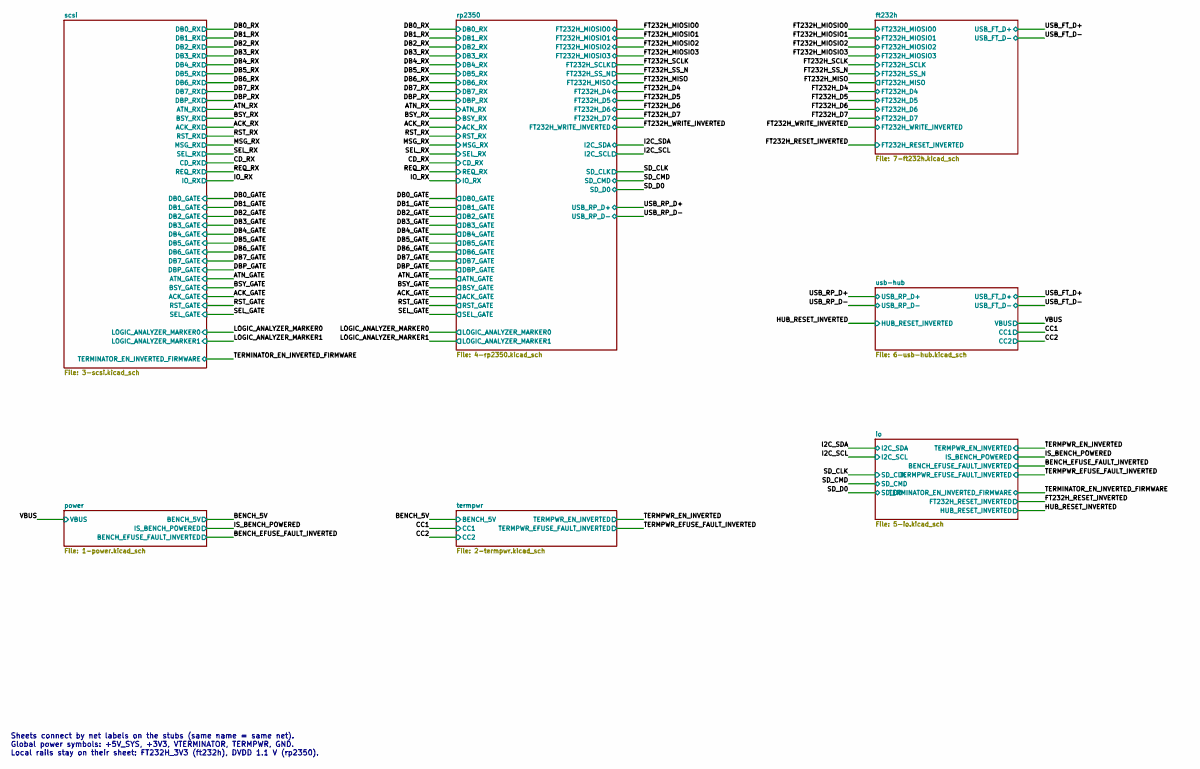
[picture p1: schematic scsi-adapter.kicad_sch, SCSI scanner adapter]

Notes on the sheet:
Sheets connect by net labels on the stubs (same name = same net). Global power symbols: +5V_SYS, +3V3, VTERMINATOR, TERMPWR, GND. Local rails stay on their sheet: FT232H_3V3 (ft232h), DVDD 1.1 V (rp2350).

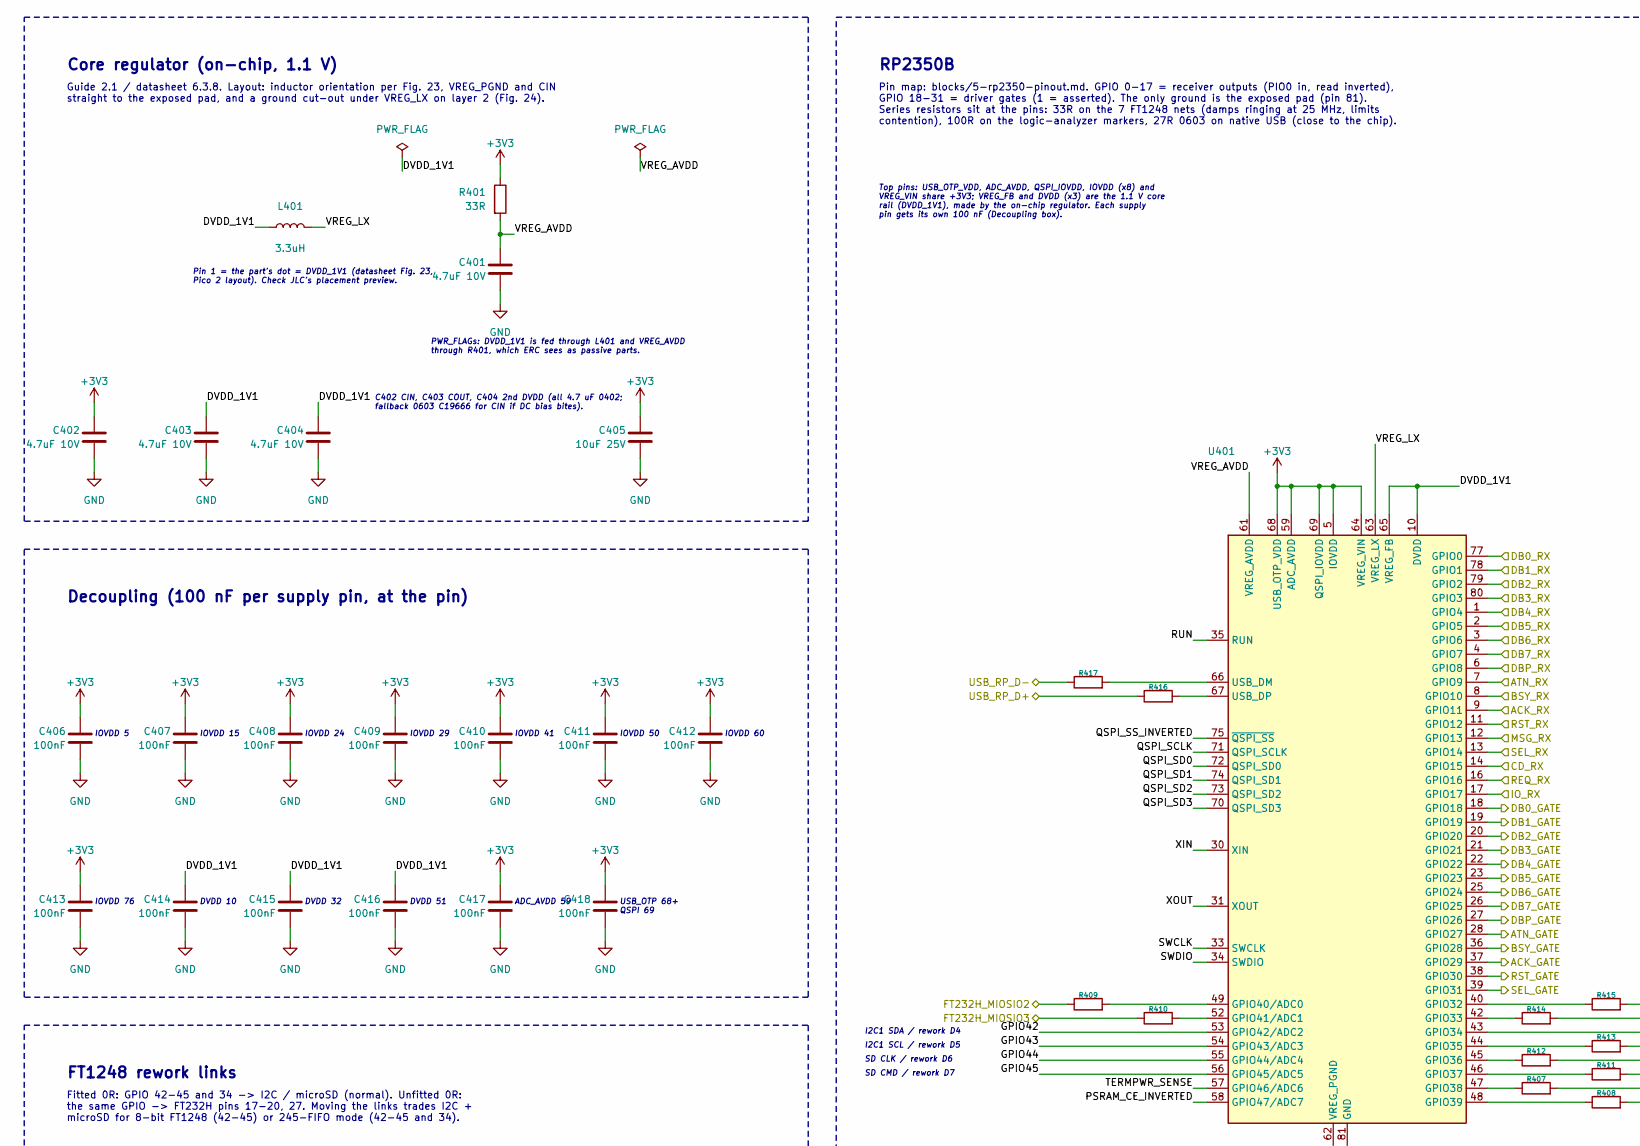
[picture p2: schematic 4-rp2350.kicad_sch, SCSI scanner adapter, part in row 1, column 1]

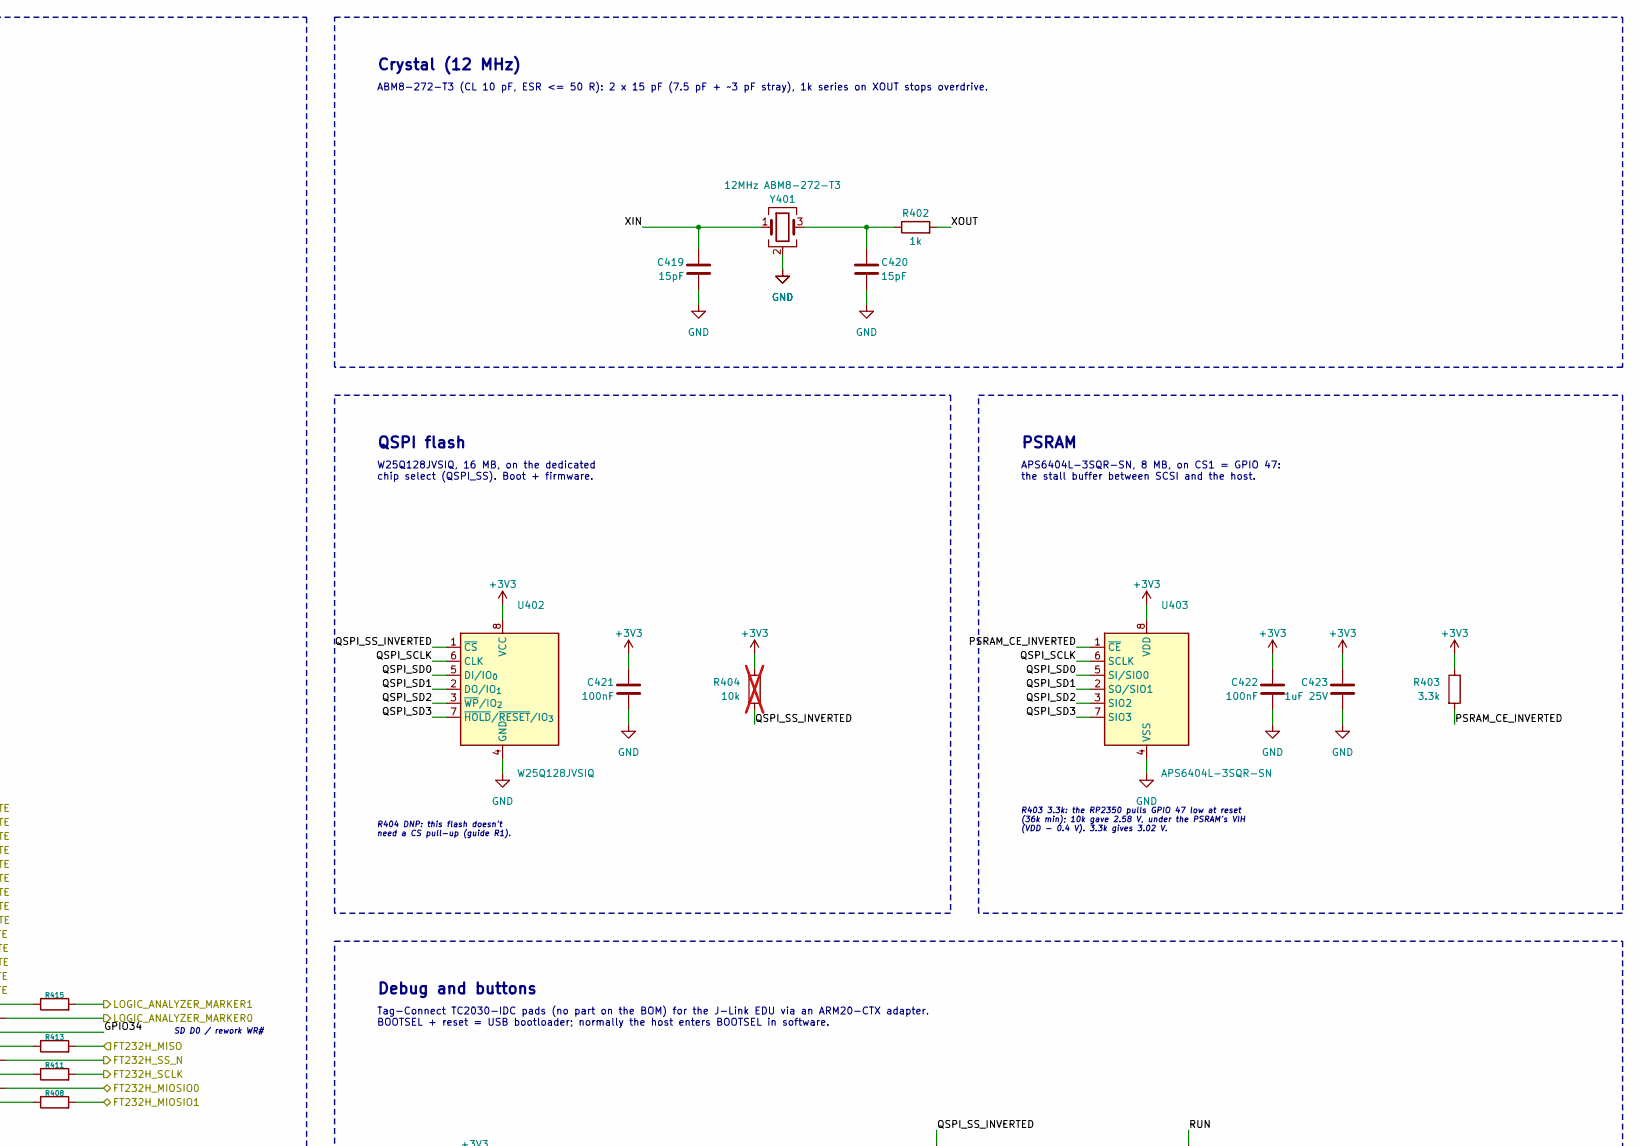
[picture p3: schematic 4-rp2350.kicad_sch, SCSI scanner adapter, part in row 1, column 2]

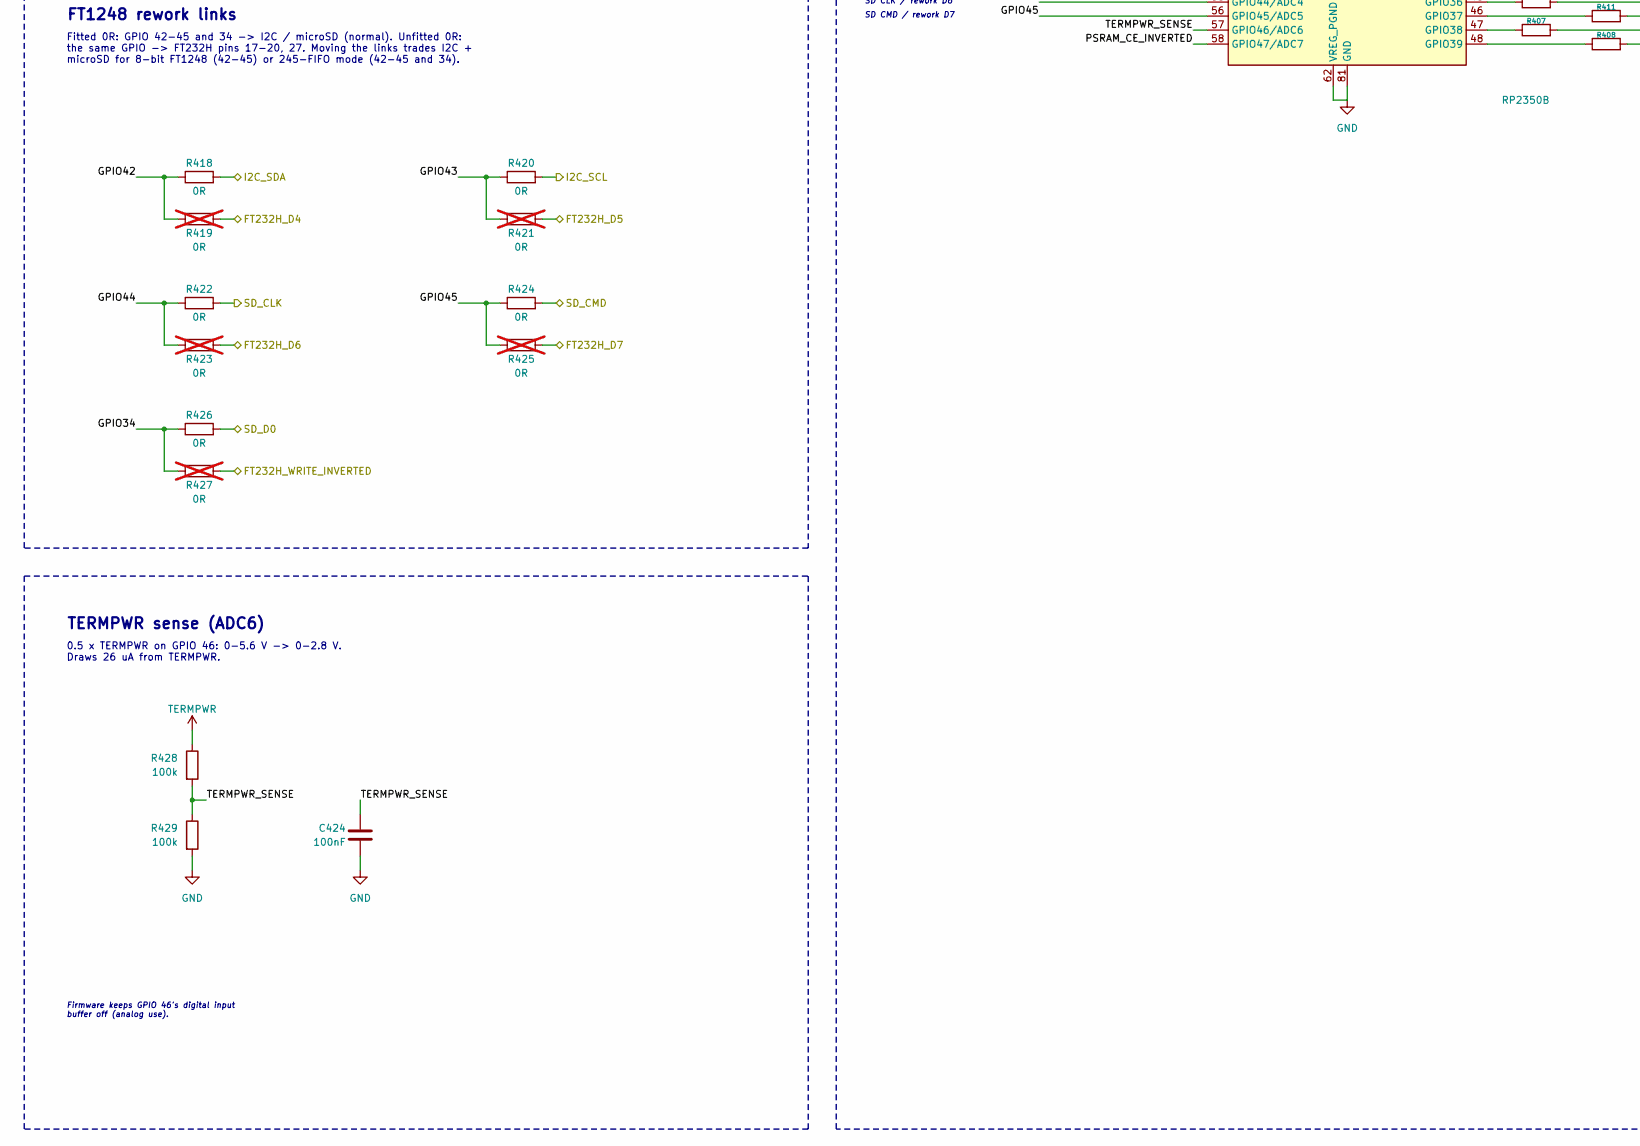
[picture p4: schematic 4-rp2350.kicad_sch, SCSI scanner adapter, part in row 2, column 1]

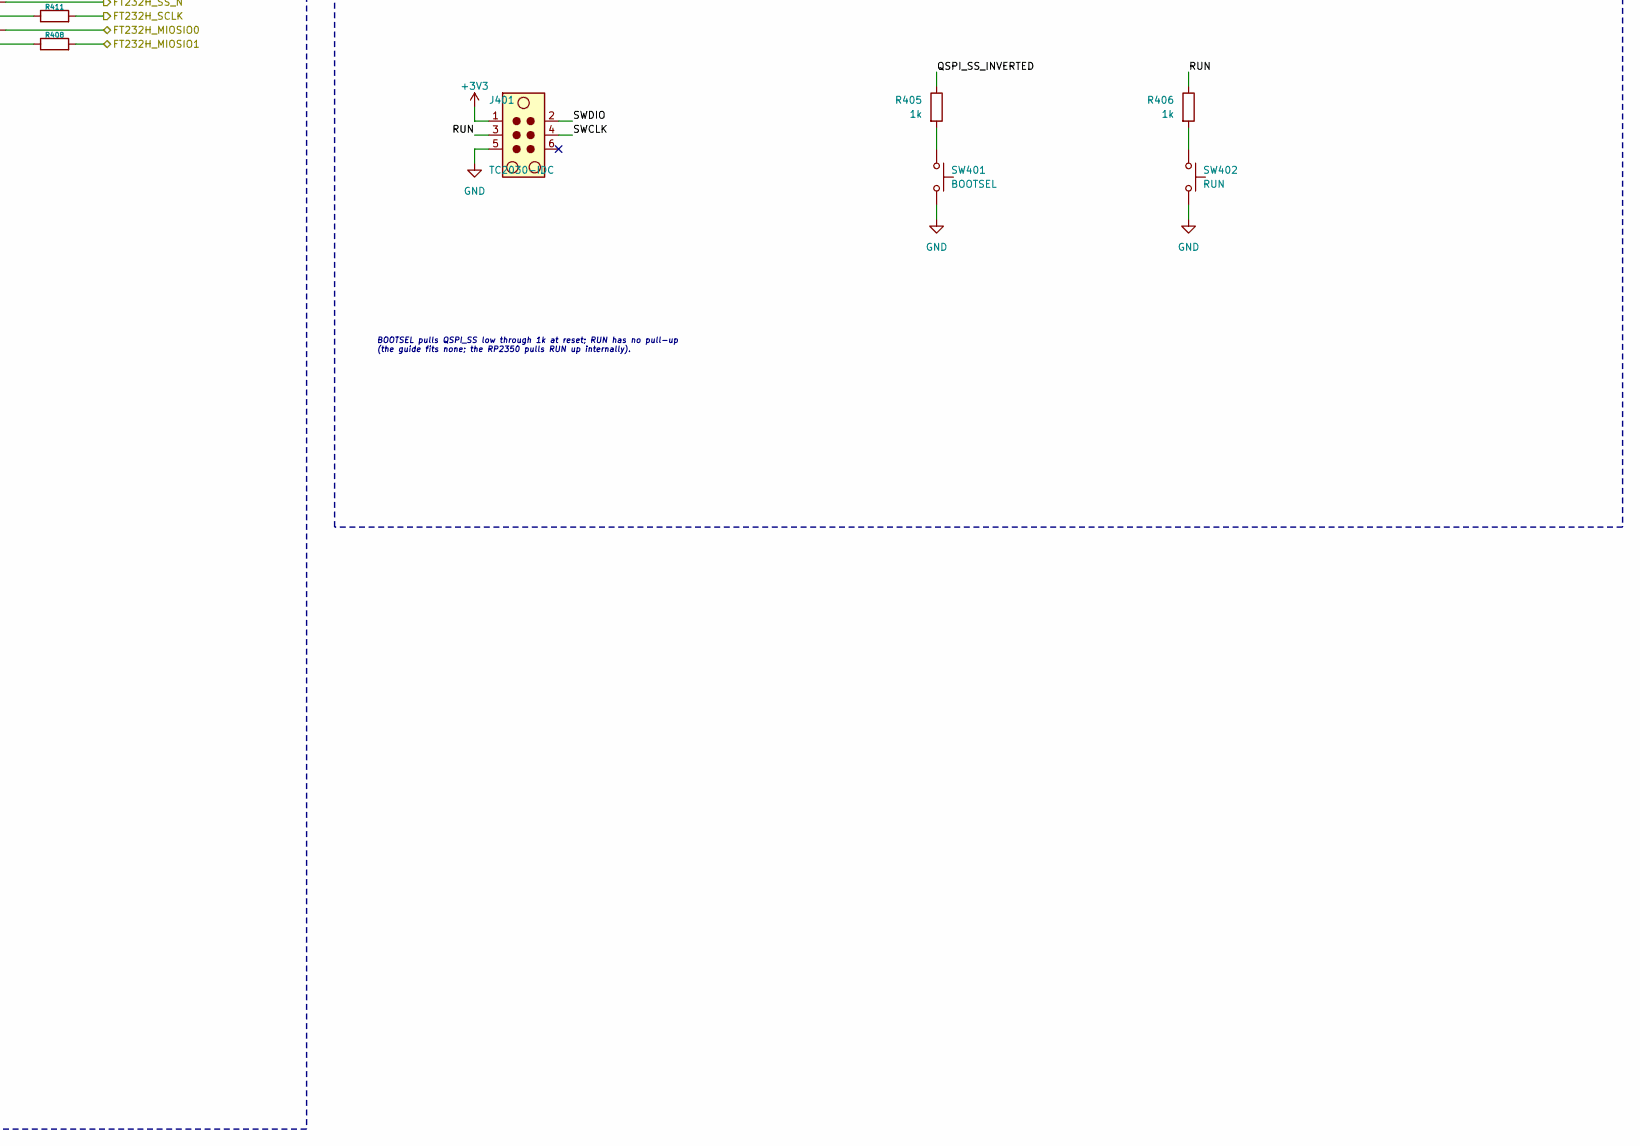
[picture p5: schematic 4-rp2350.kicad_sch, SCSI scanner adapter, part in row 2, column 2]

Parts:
C401, C404: 4.7uF 10V; C_0402_1005Metric; LCSC C23733
C402, C403: 4.7uF 10V; C_0402_1005Metric_Wide; LCSC C23733
C405: 10uF 25V; C_0805_2012Metric; LCSC C15850
C406, C407, C408, C409, C410, C411, C412, C413, C414, C415, C416, C417, C418, C421, C422, C424: 100nF; C_0402_1005Metric; LCSC C307331
C419, C420: 15pF; C_0402_1005Metric; LCSC C1548
C423: 1uF 25V; C_0402_1005Metric; LCSC C52923
J401: TC2030-IDC; Tag-Connect_TC2030-IDC-FP_2x03_P1.27mm_Vertical
L401: 3.3uH; L_Abracon_AOTA-B201610_2.0x1.6mm_Polarized; LCSC C42411119
R401, R407, R408, R409, R410, R411, R412, R413: 33R; R_0402_1005Metric; LCSC C25105
R402, R405, R406: 1k; R_0402_1005Metric; LCSC C11702
R403: 3.3k; R_0402_1005Metric; LCSC C25890
R404: 10k; R_0402_1005Metric; LCSC C25744; not fitted
R414, R415: 100R; R_0402_1005Metric; LCSC C25076
R416, R417: 27R; R_0603_1608Metric; LCSC C25190
R418, R420, R422, R424, R426: 0R; R_0402_1005Metric; LCSC C17168
R419, R421, R423, R425, R427: 0R; R_0805_2012Metric; LCSC C17477; not fitted
R428, R429: 100k; R_0402_1005Metric; LCSC C25741
SW401: BOOTSEL; SW_PUSH_6mm; LCSC C110153
SW402: RUN; SW_PUSH_6mm; LCSC C110153
U401: RP2350B; QFN-80-1EP_10x10mm_P0.4mm_EP3.4x3.4mm; LCSC C42415655
U402: W25Q128JVSIQ; SOIC-8_5.3x5.3mm_P1.27mm; LCSC C97521
U403: APS6404L-3SQR-SN; SOIC-8_3.9x4.9mm_P1.27mm; LCSC C5333729
Y401: 12MHz ABM8-272-T3; Crystal_SMD_3225-4Pin_3.2x2.5mm; LCSC C20625731

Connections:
+3V3: C402.1, C405.1, C406.1, C407.1, C408.1, C409.1, C410.1, C411.1, C412.1, C413.1, C417.1, C418.1, C421.1, C422.1, C423.1, J401.1, R401.1, R403.1, R404.1, U401.5 (IOVDD), U401.15 (IOVDD), U401.24 (IOVDD), U401.29 (IOVDD), U401.41 (IOVDD), U401.50 (IOVDD), U401.59 (ADC_AVDD), U401.60 (IOVDD), U401.64 (VREG_VIN), U401.68 (USB_OTP_VDD), U401.69 (QSPI_IOVDD), U401.76 (IOVDD), U402.8 (VCC), U403.8 (VDD); also elsewhere on the board
/ACK_GATE: U401.37 (GPIO29); also elsewhere on the board
/ACK_RX: U401.9 (GPIO11); also elsewhere on the board
/ATN_GATE: U401.28 (GPIO27); also elsewhere on the board
/ATN_RX: U401.7 (GPIO9); also elsewhere on the board
/BSY_GATE: U401.36 (GPIO28); also elsewhere on the board
/BSY_RX: U401.8 (GPIO10); also elsewhere on the board
/CD_RX: U401.14 (GPIO15); also elsewhere on the board
/DB0_GATE: U401.18 (GPIO18); also elsewhere on the board
/DB0_RX: U401.77 (GPIO0); also elsewhere on the board
/DB1_GATE: U401.19 (GPIO19); also elsewhere on the board
/DB1_RX: U401.78 (GPIO1); also elsewhere on the board
/DB2_GATE: U401.20 (GPIO20); also elsewhere on the board
/DB2_RX: U401.79 (GPIO2); also elsewhere on the board
/DB3_GATE: U401.21 (GPIO21); also elsewhere on the board
/DB3_RX: U401.80 (GPIO3); also elsewhere on the board
/DB4_GATE: U401.22 (GPIO22); also elsewhere on the board
/DB4_RX: U401.1 (GPIO4); also elsewhere on the board
/DB5_GATE: U401.23 (GPIO23); also elsewhere on the board
/DB5_RX: U401.2 (GPIO5); also elsewhere on the board
/DB6_GATE: U401.25 (GPIO24); also elsewhere on the board
/DB6_RX: U401.3 (GPIO6); also elsewhere on the board
/DB7_GATE: U401.26 (GPIO25); also elsewhere on the board
/DB7_RX: U401.4 (GPIO7); also elsewhere on the board
/DBP_GATE: U401.27 (GPIO26); also elsewhere on the board
/DBP_RX: U401.6 (GPIO8); also elsewhere on the board
/FT232H_D4: R419.2; also elsewhere on the board
/FT232H_D5: R421.2; also elsewhere on the board
/FT232H_D6: R423.2; also elsewhere on the board
/FT232H_D7: R425.2; also elsewhere on the board
/FT232H_MIOSIO0: R407.2; also elsewhere on the board
/FT232H_MIOSIO1: R408.2; also elsewhere on the board
/FT232H_MIOSIO2: R409.1; also elsewhere on the board
/FT232H_MIOSIO3: R410.1; also elsewhere on the board
/FT232H_MISO: R413.2; also elsewhere on the board
/FT232H_SCLK: R411.2; also elsewhere on the board
/FT232H_SS_N: R412.2; also elsewhere on the board
/FT232H_WRITE_INVERTED: R427.2; also elsewhere on the board
/I2C_SCL: R420.2; also elsewhere on the board
/I2C_SDA: R418.2; also elsewhere on the board
/IO_RX: U401.17 (GPIO17); also elsewhere on the board
/LOGIC_ANALYZER_MARKER0: R414.2; also elsewhere on the board
/LOGIC_ANALYZER_MARKER1: R415.2; also elsewhere on the board
/MSG_RX: U401.12 (GPIO13); also elsewhere on the board
/REQ_RX: U401.16 (GPIO16); also elsewhere on the board
/RST_GATE: U401.38 (GPIO30); also elsewhere on the board
/RST_RX: U401.11 (GPIO12); also elsewhere on the board
/SD_CLK: R422.2; also elsewhere on the board
/SD_CMD: R424.2; also elsewhere on the board
/SD_D0: R426.2; also elsewhere on the board
/SEL_GATE: U401.39 (GPIO31); also elsewhere on the board
/SEL_RX: U401.13 (GPIO14); also elsewhere on the board
/USB_RP_D+: R416.1; also elsewhere on the board
/USB_RP_D-: R417.1; also elsewhere on the board
/rp2350/DVDD_1V1: C403.1, C404.1, C414.1, C415.1, C416.1, L401.1, U401.10 (DVDD), U401.32 (DVDD), U401.51 (DVDD), U401.65 (VREG_FB)
/rp2350/GPIO34: R426.1, R427.1, U401.43 (GPIO34)
/rp2350/GPIO42: R418.1, R419.1, U401.53 (GPIO42/ADC2)
/rp2350/GPIO43: R420.1, R421.1, U401.54 (GPIO43/ADC3)
/rp2350/GPIO44: R422.1, R423.1, U401.55 (GPIO44/ADC4)
/rp2350/GPIO45: R424.1, R425.1, U401.56 (GPIO45/ADC5)
/rp2350/PSRAM_CE_INVERTED: R403.2, U401.58 (GPIO47/ADC7), U403.1 (~CE)
/rp2350/QSPI_SCLK: U401.71 (QSPI_SCLK), U402.6 (CLK), U403.6 (SCLK)
/rp2350/QSPI_SD0: U401.72 (QSPI_SD0), U402.5 (DI/IO_{0}), U403.5 (SI/SIO0)
/rp2350/QSPI_SD1: U401.74 (QSPI_SD1), U402.2 (DO/IO_{1}), U403.2 (SO/SIO1)
/rp2350/QSPI_SD2: U401.73 (QSPI_SD2), U402.3 (~WP/IO_{2}), U403.3 (SIO2)
/rp2350/QSPI_SD3: U401.70 (QSPI_SD3), U402.7 (~HOLD/~RESET/IO_{3}), U403.7 (SIO3)
/rp2350/QSPI_SS_INVERTED: R404.2, R405.1, U401.75 (~QSPI_SS), U402.1 (~CS)
/rp2350/RUN: J401.3, R406.1, U401.35 (RUN)
/rp2350/SWCLK: J401.4, U401.33 (SWCLK)
/rp2350/SWDIO: J401.2, U401.34 (SWDIO)
/rp2350/TERMPWR_SENSE: C424.1, R428.2, R429.1, U401.57 (GPIO46/ADC6)
/rp2350/VREG_AVDD: C401.1, R401.2, U401.61 (VREG_AVDD)
/rp2350/VREG_LX: L401.2, U401.63 (VREG_LX)
/rp2350/XIN: C419.1, U401.30 (XIN), Y401.1
/rp2350/XOUT: R402.2, U401.31 (XOUT)
GND: C401.2, C402.2, C403.2, C404.2, C405.2, C406.2, C407.2, C408.2, C409.2, C410.2, C411.2, C412.2, C413.2, C414.2, C415.2, C416.2, C417.2, C418.2, C419.2, C420.2, C421.2, C422.2, C423.2, C424.2, J401.5, R429.2, SW401.2, SW402.2, U401.62 (VREG_PGND), U401.81 (GND), U402.4 (GND), U403.4 (VSS), Y401.2 (G), Y401.4 (G); also elsewhere on the board
unnamed: C420.1, R402.1, Y401.3
unnamed: R405.2, SW401.1
unnamed: R406.2, SW402.1
unnamed: R415.1, U401.40 (GPIO32)
unnamed: R414.1, U401.42 (GPIO33)
unnamed: R413.1, U401.44 (GPIO35)
unnamed: R412.1, U401.45 (GPIO36)
unnamed: R411.1, U401.46 (GPIO37)
unnamed: R407.1, U401.47 (GPIO38)
unnamed: R408.1, U401.48 (GPIO39)
unnamed: R409.2, U401.49 (GPIO40/ADC0)
unnamed: R410.2, U401.52 (GPIO41/ADC1)
unnamed: R417.2, U401.66 (USB_DM)
unnamed: R416.2, U401.67 (USB_DP)
TERMPWR: R428.1; also elsewhere on the board

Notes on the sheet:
BOOTSEL pulls QSPI_SS low through 1k at reset; RUN has no pull-up (the guide fits none; the RP2350 pulls RUN up internally).
USB_OTP 68+ QSPI 69
R404 DNP: this flash doesn't need a CS pull-up (guide R1).
PWR_FLAGs: DVDD_1V1 is fed through L401 and VREG_AVDD through R401, which ERC sees as passive parts.
ADC_AVDD 59
SD CLK / rework D6
I2C1 SDA / rework D4
Tag-Connect TC2030-IDC pads (no part on the BOM) for the J-Link EDU via an ARM20-CTX adapter. BOOTSEL + reset = USB bootloader; normally the host enters BOOTSEL in software.
Pin map: blocks/5-rp2350-pinout.md. GPIO 0-17 = receiver outputs (PIO0 in, read inverted), GPIO 18-31 = driver gates (1 = asserted). The only ground is the exposed pad (pin 81). Series resistors sit at the pins: 33R on the 7 FT1248 nets (damps ringing at 25 MHz, limits contention), 100R on the logi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
IOVDD 41
IOVDD 24
Firmware keeps GPIO 46's digital input buffer off (analog use).
IOVDD 50
W25Q128JVSIQ, 16 MB, on the dedicated chip select (QSPI_SS). Boot + firmware.
IOVDD 29
DVDD 10
Fitted 0R: GPIO 42-45 and 34 -> I2C / microSD (normal). Unfitted 0R: the same GPIO -> FT232H pins 17-20, 27. Moving the links trades I2C + microSD for 8-bit FT1248 (42-45) or 245-FIFO mode (42-45 and 34).
DVDD 51
ABM8-272-T3 (CL 10 pF, ESR <= 50 R): 2 x 15 pF (7.5 pF + ~3 pF stray), 1k series on XOUT stops overdrive.
Pin 1 = the part's dot = DVDD_1V1 (datasheet Fig. 23, Pico 2 layout). Check JLC's placement preview.
IOVDD 15
Guide 2.1 / datasheet 6.3.8. Layout: inductor orientation per Fig. 23, VREG_PGND and CIN straight to the exposed pad, and a ground cut-out under VREG_LX on layer 2 (Fig. 24).
PSRAM
APS6404L-3SQR-SN, 8 MB, on CS1 = GPIO 47: the stall buffer between SCSI and the host.
QSPI flash
IOVDD 76
SD CMD / rework D7
Core regulator (on-chip, 1.1 V)
FT1248 rework links
R403 3.3k: the RP2350 pulls GPIO 47 low at reset (36k min); 10k gave 2.58 V, under the PSRAM's VIH (VDD - 0.4 V). 3.3k gives 3.02 V.
DVDD 32
C402 CIN, C403 COUT, C404 2nd DVDD (all 4.7 uF 0402; fallback 0603 C19666 for CIN if DC bias bites).
RP2350B
0.5 x TERMPWR on GPIO 46: 0-5.6 V -> 0-2.8 V. Draws 26 uA from TERMPWR.
Decoupling (100 nF per supply pin, at the pin)
Debug and buttons
SD D0 / rework WR#
Crystal (12 MHz)
IOVDD 5
Top pins: USB_OTP_VDD, ADC_AVDD, QSPI_IOVDD, IOVDD (x8) and VREG_VIN share +3V3; VREG_FB and DVDD (x3) are the 1.1 V core rail (DVDD_1V1), made by the on-chip regulator. Each supply pin gets its own 100 nF (Decoupling box).

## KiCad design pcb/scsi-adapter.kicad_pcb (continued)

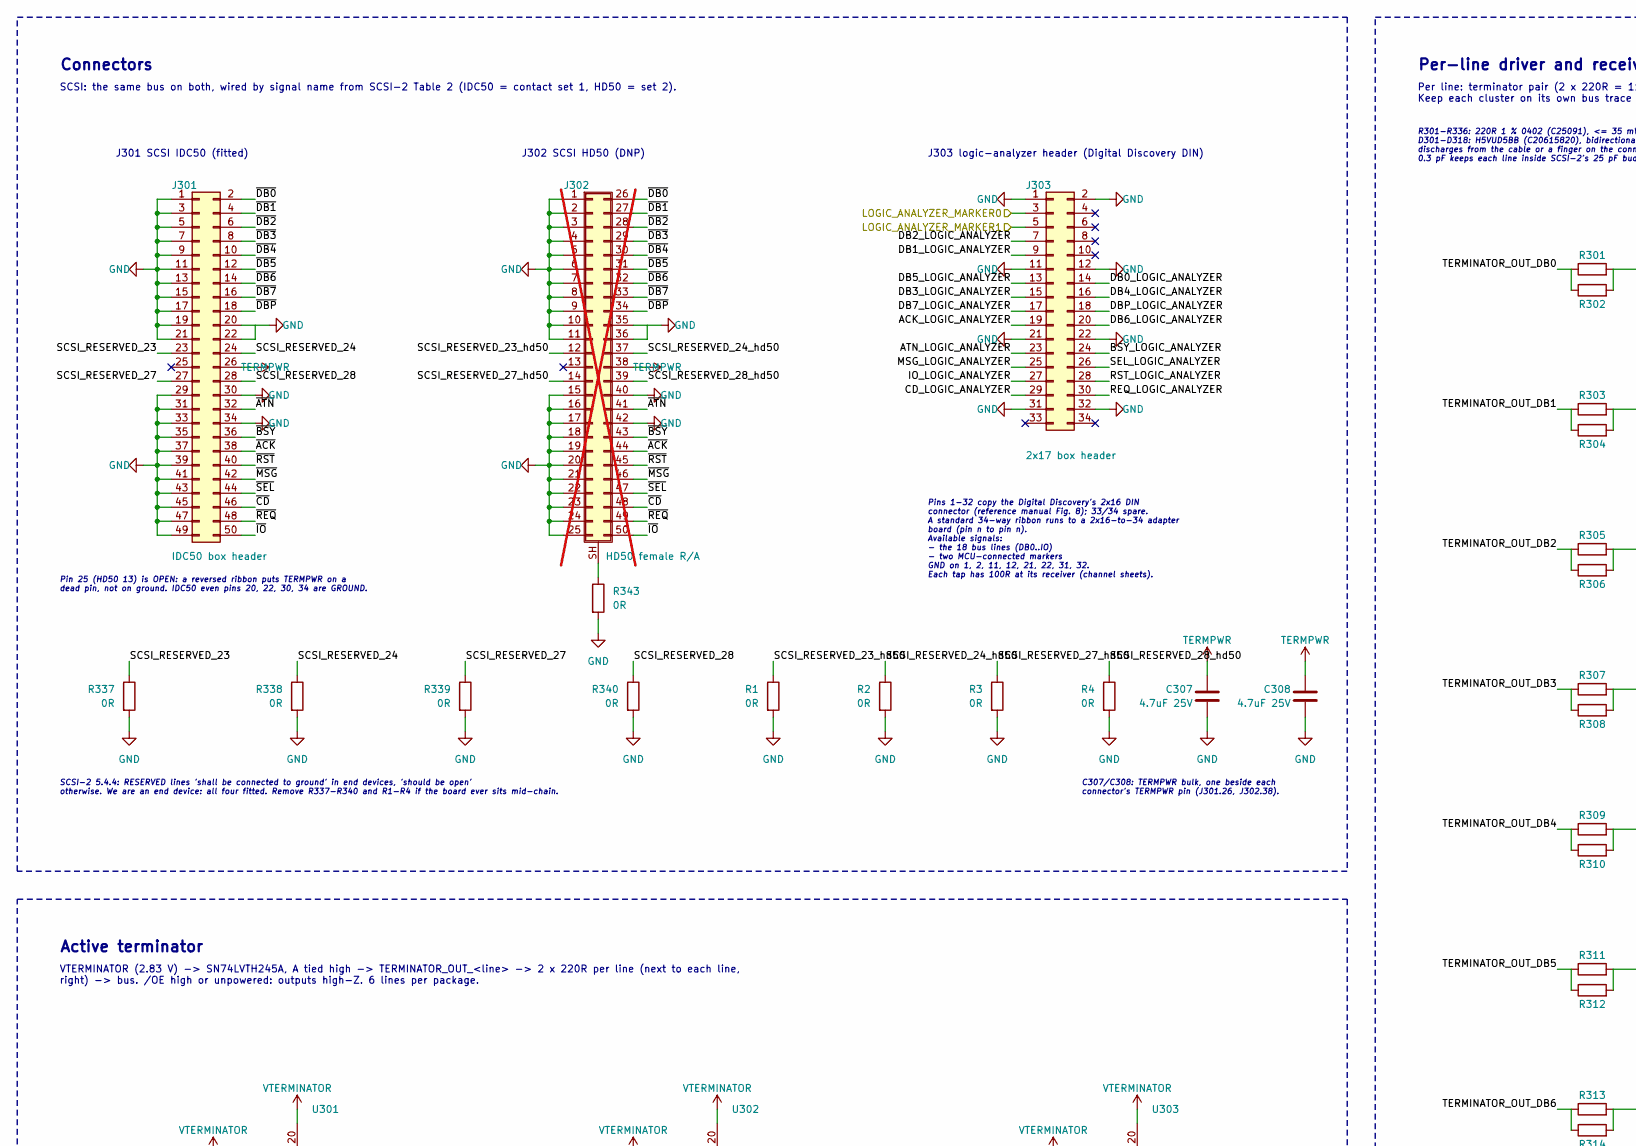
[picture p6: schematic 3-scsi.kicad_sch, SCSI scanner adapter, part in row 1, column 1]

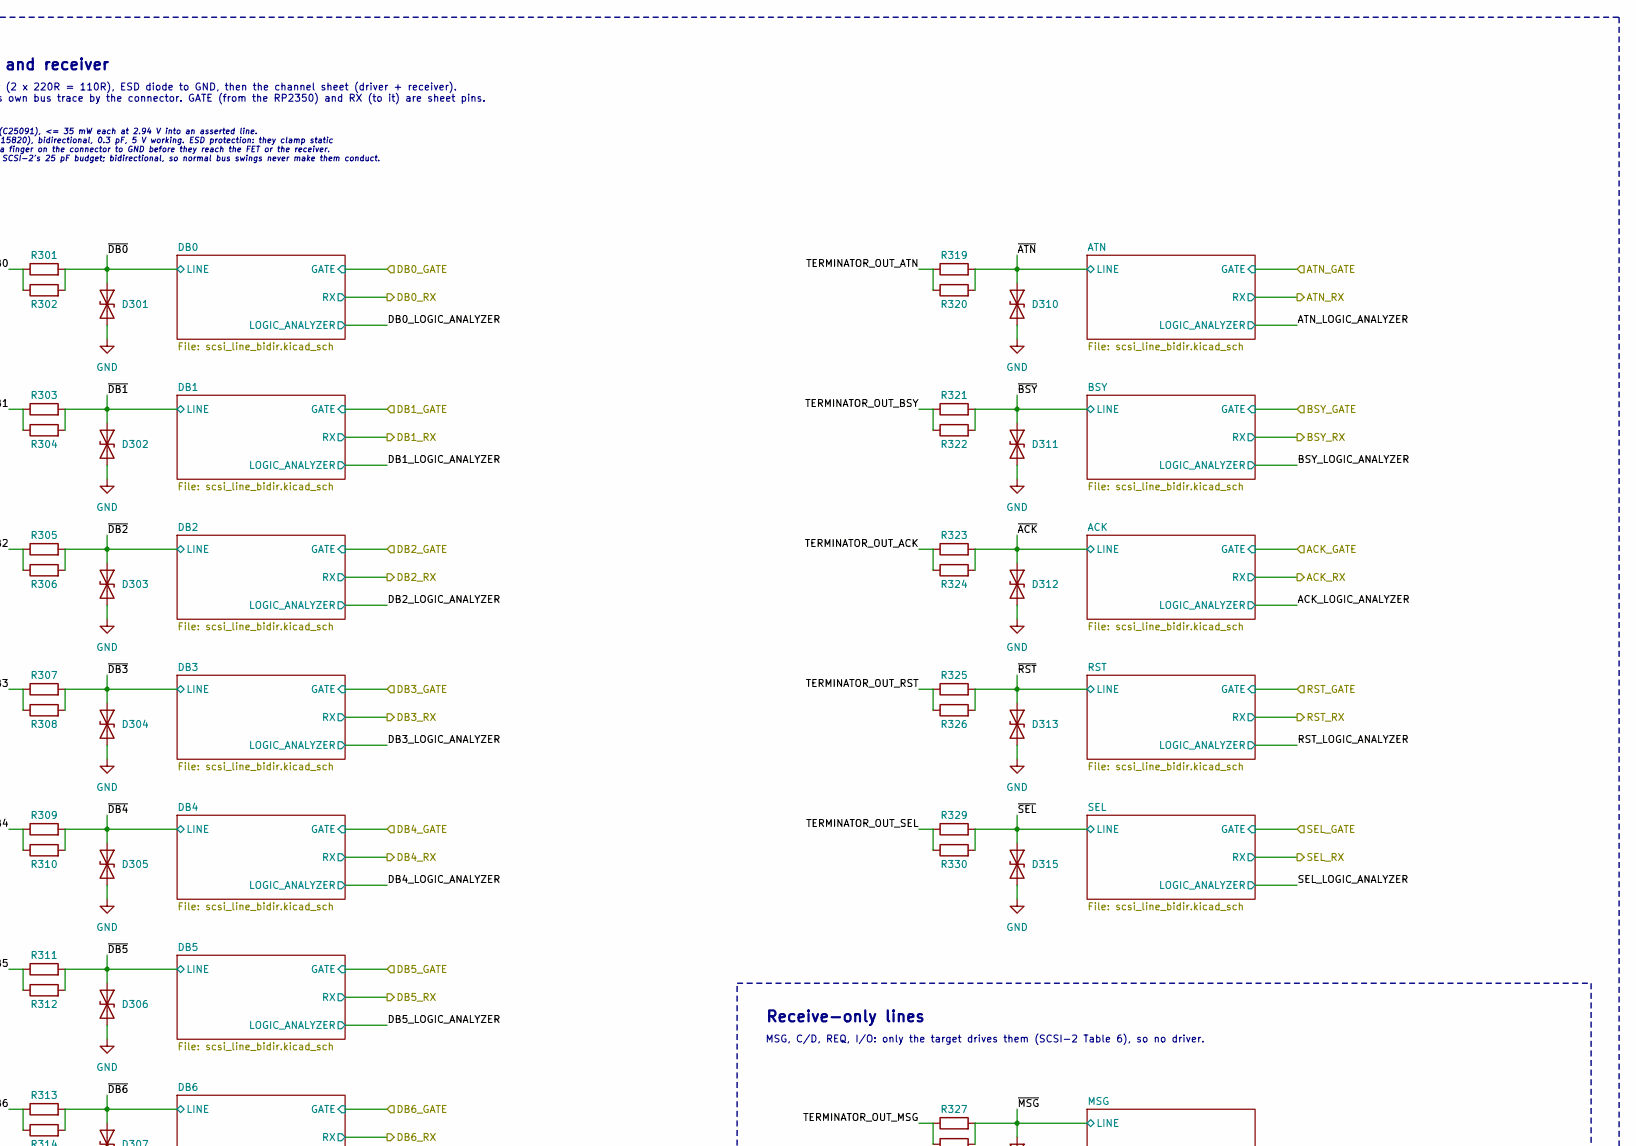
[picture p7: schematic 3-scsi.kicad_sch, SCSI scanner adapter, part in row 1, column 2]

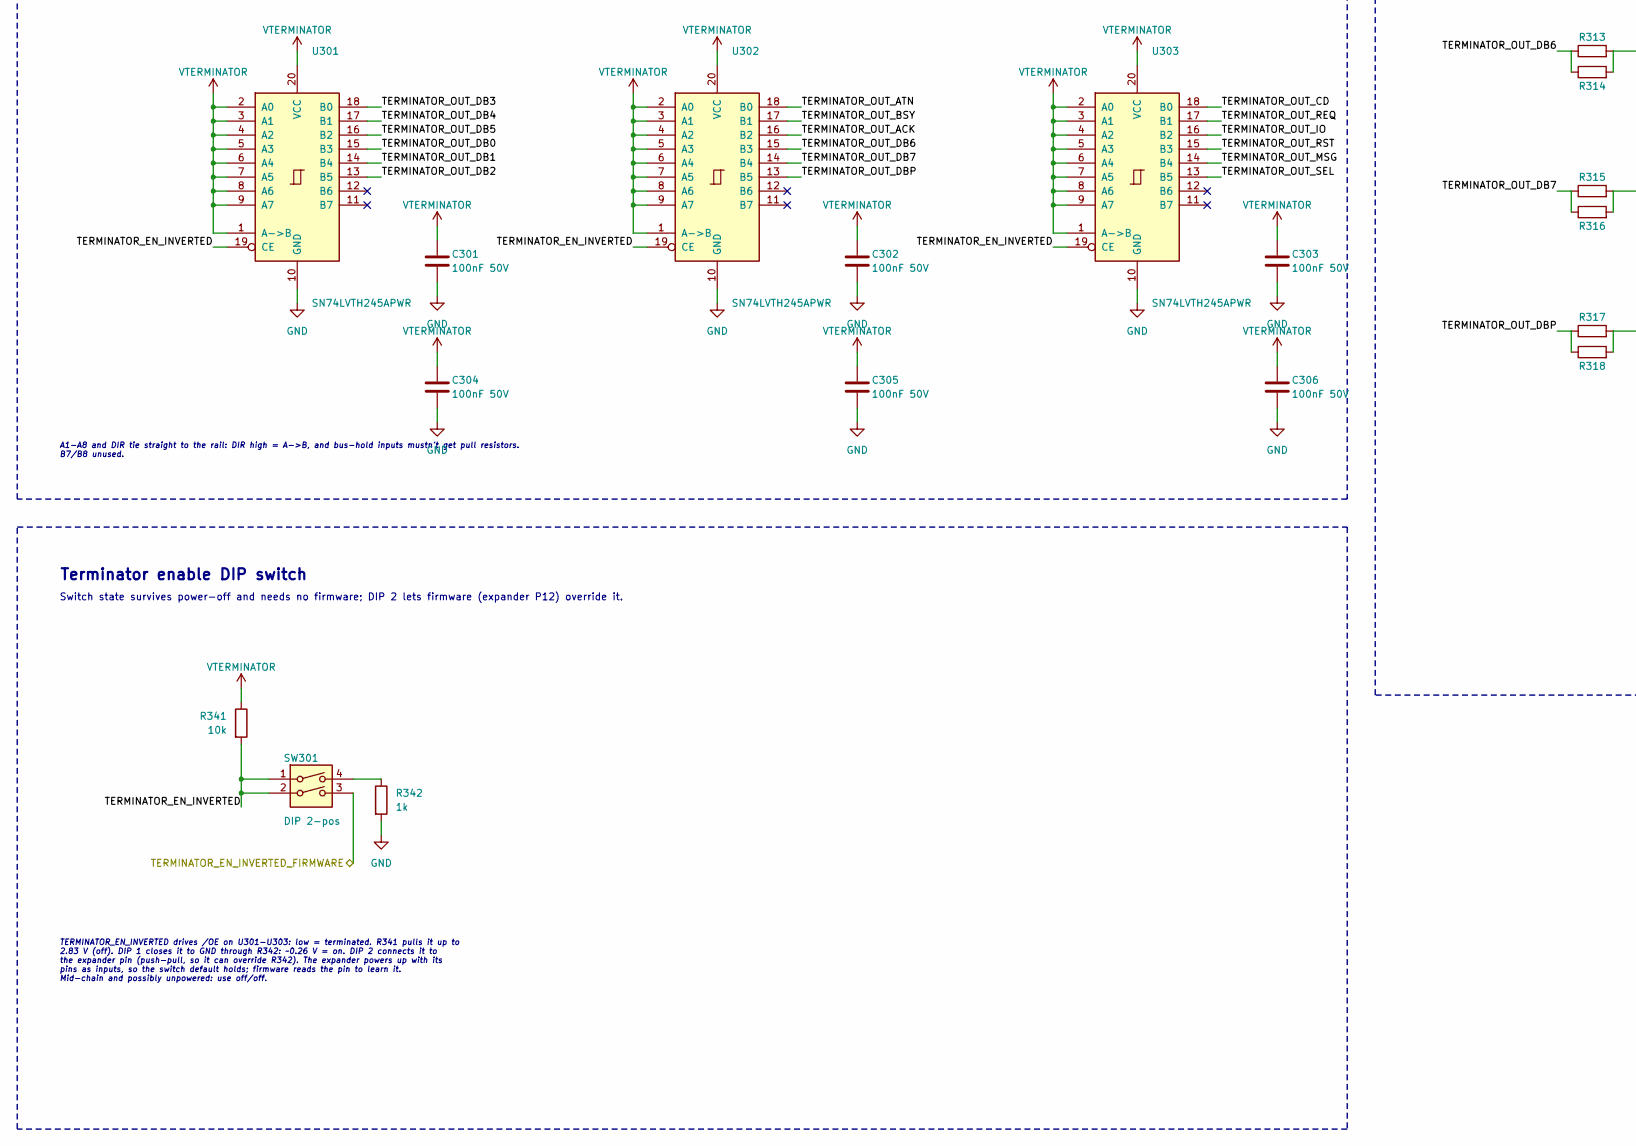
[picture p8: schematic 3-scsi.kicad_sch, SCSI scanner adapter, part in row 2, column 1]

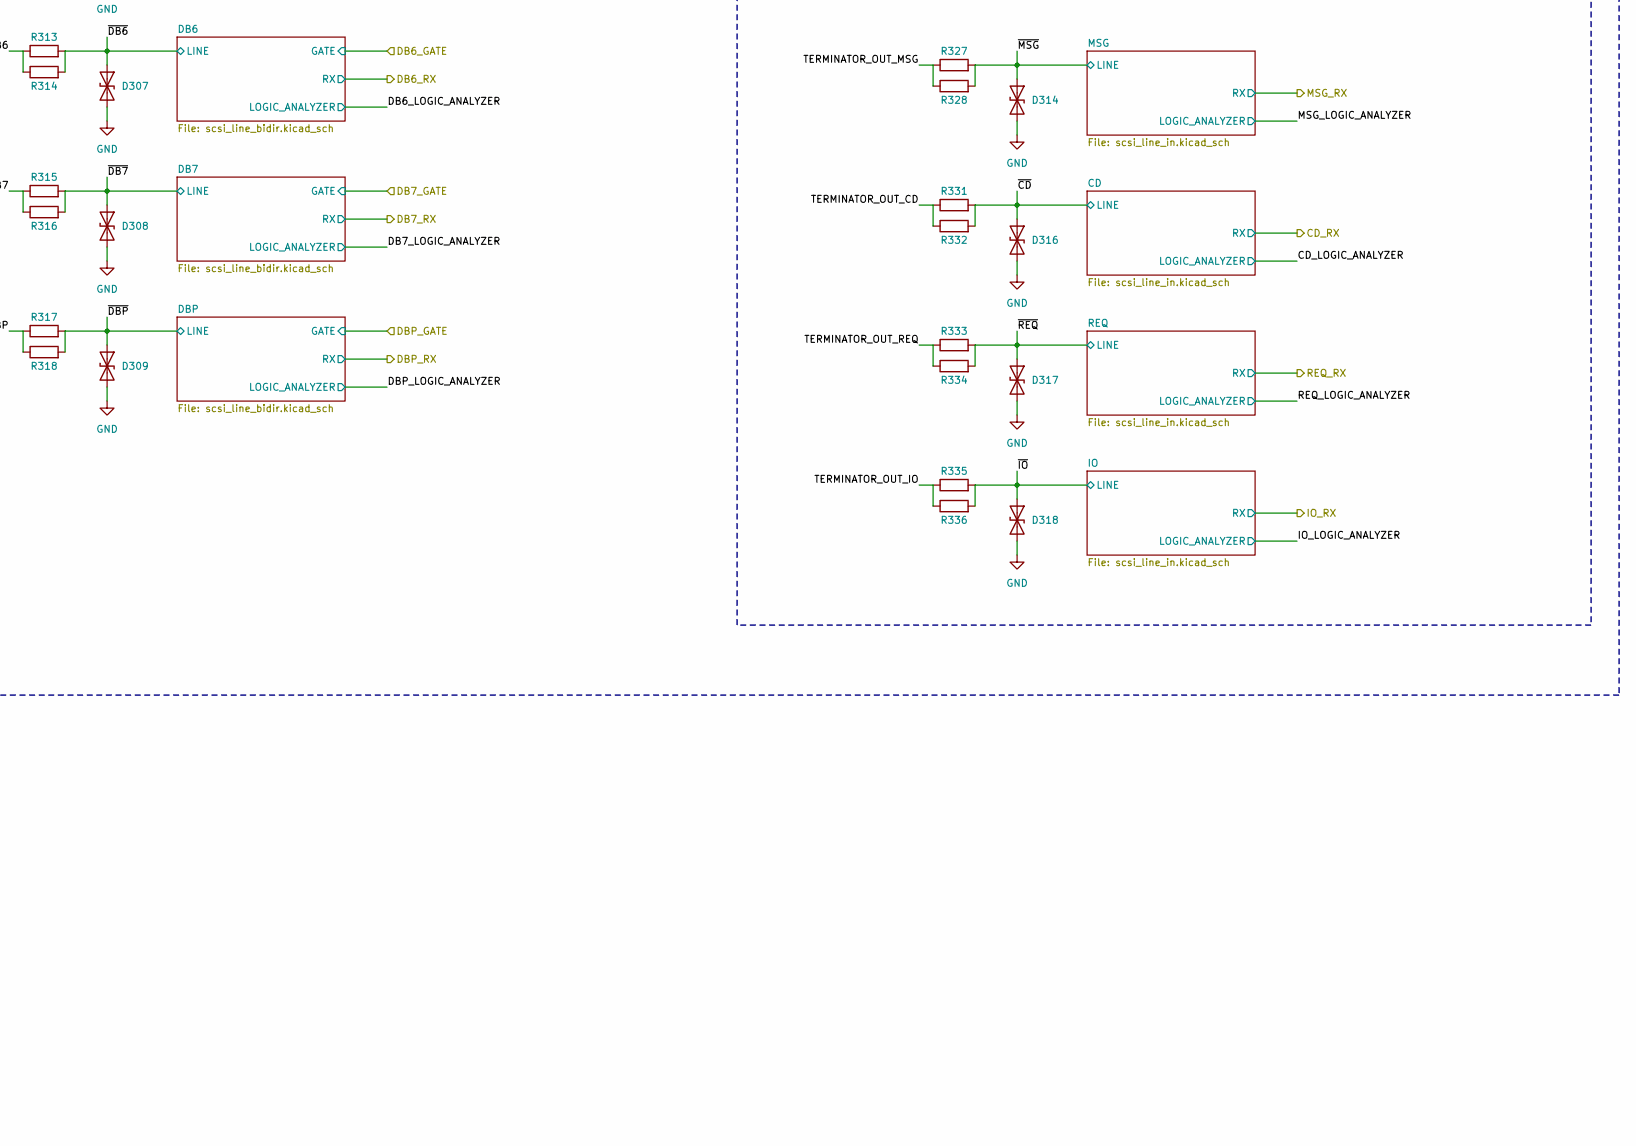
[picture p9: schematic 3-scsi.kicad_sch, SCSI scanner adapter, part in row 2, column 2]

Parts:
C301, C302, C303, C304, C305, C306: 100nF 50V; C_0402_1005Metric; LCSC C307331
C307, C308: 4.7uF 25V; C_0805_2012Metric; LCSC C1779
D301, D302, D303, D304, D305, D306, D307, D308, D309, D310, D311, D312, D313, D314, D315, D316, D317, D318: H5VUD5BB; D_SOD-523; LCSC C20615820
J301: IDC50 box header; IDC-Header_2x25_P2.54mm_Vertical; LCSC C30006
J302: HD50 female R/A; TE_AMPLIMITE-050_5787082-5_50pos_P1.27mm_Horizontal; not fitted
J303: 2x17 box header; IDC-Header_2x17_P2.54mm_Vertical; LCSC C20920
R1, R2, R3, R4, R337, R338, R339, R340, R343: 0R; R_0402_1005Metric; LCSC C17168
R301, R302, R303, R304, R305, R306, R307, R308, R309, R310, R311, R312, R313, R314, R315, R316, R317, R318, R319, R320, R321, R322, R323, R324, R325, R326, R327, R328, R329, R330, R331, R332, R333, R334, R335, R336: 220R; R_0402_1005Metric; LCSC C25091
R341: 10k; R_0402_1005Metric; LCSC C25744
R342: 1k; R_0402_1005Metric; LCSC C11702
SW301: DIP 2-pos; SW_DIP_SPSTx02_Slide_SHOUHAN_2.54-2P-TPGT_W8.8mm_P2.54mm; LCSC C6331180
U301, U302, U303: SN74LVTH245APWR; TSSOP-20_4.4x6.5mm_P0.65mm; LCSC C2652121

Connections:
/LOGIC_ANALYZER_MARKER0: J303.3; also elsewhere on the board
/LOGIC_ANALYZER_MARKER1: J303.5; also elsewhere on the board
/TERMINATOR_EN_INVERTED_FIRMWARE: SW301.3; also elsewhere on the board
/scsi/ACK_LOGIC_ANALYZER: J303.19; also elsewhere on the board
/scsi/ATN_LOGIC_ANALYZER: J303.23; also elsewhere on the board
/scsi/BSY_LOGIC_ANALYZER: J303.24; also elsewhere on the board
/scsi/CD_LOGIC_ANALYZER: J303.29; also elsewhere on the board
/scsi/DB0_LOGIC_ANALYZER: J303.14; also elsewhere on the board
/scsi/DB1_LOGIC_ANALYZER: J303.9; also elsewhere on the board
/scsi/DB2_LOGIC_ANALYZER: J303.7; also elsewhere on the board
/scsi/DB3_LOGIC_ANALYZER: J303.15; also elsewhere on the board
/scsi/DB4_LOGIC_ANALYZER: J303.16; also elsewhere on the board
/scsi/DB5_LOGIC_ANALYZER: J303.13; also elsewhere on the board
/scsi/DB6_LOGIC_ANALYZER: J303.20; also elsewhere on the board
/scsi/DB7_LOGIC_ANALYZER: J303.17; also elsewhere on the board
/scsi/DBP_LOGIC_ANALYZER: J303.18; also elsewhere on the board
/scsi/IO_LOGIC_ANALYZER: J303.27; also elsewhere on the board
/scsi/MSG_LOGIC_ANALYZER: J303.25; also elsewhere on the board
/scsi/REQ_LOGIC_ANALYZER: J303.30; also elsewhere on the board
/scsi/RST_LOGIC_ANALYZER: J303.28; also elsewhere on the board
/scsi/SCSI_RESERVED_23: J301.23, R337.1
/scsi/SCSI_RESERVED_23_hd50: J302.12, R1.1
/scsi/SCSI_RESERVED_24: J301.24, R338.1
/scsi/SCSI_RESERVED_24_hd50: J302.37, R2.1
/scsi/SCSI_RESERVED_27: J301.27, R339.1
/scsi/SCSI_RESERVED_27_hd50: J302.14, R3.1
/scsi/SCSI_RESERVED_28: J301.28, R340.1
/scsi/SCSI_RESERVED_28_hd50: J302.39, R4.1
/scsi/SEL_LOGIC_ANALYZER: J303.26; also elsewhere on the board
/scsi/TERMINATOR_EN_INVERTED: R341.2, SW301.1, SW301.2, U301.19 (CE), U302.19 (CE), U303.19 (CE)
/scsi/TERMINATOR_OUT_ACK: R323.1, R324.1, U302.16 (B2)
/scsi/TERMINATOR_OUT_ATN: R319.1, R320.1, U302.18 (B0)
/scsi/TERMINATOR_OUT_BSY: R321.1, R322.1, U302.17 (B1)
/scsi/TERMINATOR_OUT_CD: R331.1, R332.1, U303.18 (B0)
/scsi/TERMINATOR_OUT_DB0: R301.1, R302.1, U301.15 (B3)
/scsi/TERMINATOR_OUT_DB1: R303.1, R304.1, U301.14 (B4)
/scsi/TERMINATOR_OUT_DB2: R305.1, R306.1, U301.13 (B5)
/scsi/TERMINATOR_OUT_DB3: R307.1, R308.1, U301.18 (B0)
/scsi/TERMINATOR_OUT_DB4: R309.1, R310.1, U301.17 (B1)
/scsi/TERMINATOR_OUT_DB5: R311.1, R312.1, U301.16 (B2)
/scsi/TERMINATOR_OUT_DB6: R313.1, R314.1, U302.15 (B3)
/scsi/TERMINATOR_OUT_DB7: R315.1, R316.1, U302.14 (B4)
/scsi/TERMINATOR_OUT_DBP: R317.1, R318.1, U302.13 (B5)
/scsi/TERMINATOR_OUT_IO: R335.1, R336.1, U303.16 (B2)
/scsi/TERMINATOR_OUT_MSG: R327.1, R328.1, U303.14 (B4)
/scsi/TERMINATOR_OUT_REQ: R333.1, R334.1, U303.17 (B1)
/scsi/TERMINATOR_OUT_RST: R325.1, R326.1, U303.15 (B3)
/scsi/TERMINATOR_OUT_SEL: R329.1, R330.1, U303.13 (B5)
/scsi/~ACK: D312.1 (A1), J301.38, J302.44, R323.2, R324.2; also elsewhere on the board
/scsi/~ATN: D310.1 (A1), J301.32, J302.41, R319.2, R320.2; also elsewhere on the board
/scsi/~BSY: D311.1 (A1), J301.36, J302.43, R321.2, R322.2; also elsewhere on the board
/scsi/~CD: D316.1 (A1), J301.46, J302.48, R331.2, R332.2; also elsewhere on the board
/scsi/~DB0: D301.1 (A1), J301.2, J302.26, R301.2, R302.2; also elsewhere on the board
/scsi/~DB1: D302.1 (A1), J301.4, J302.27, R303.2, R304.2; also elsewhere on the board
/scsi/~DB2: D303.1 (A1), J301.6, J302.28, R305.2, R306.2; also elsewhere on the board
/scsi/~DB3: D304.1 (A1), J301.8, J302.29, R307.2, R308.2; also elsewhere on the board
/scsi/~DB4: D305.1 (A1), J301.10, J302.30, R309.2, R310.2; also elsewhere on the board
/scsi/~DB5: D306.1 (A1), J301.12, J302.31, R311.2, R312.2; also elsewhere on the board
/scsi/~DB6: D307.1 (A1), J301.14, J302.32, R313.2, R314.2; also elsewhere on the board
/scsi/~DB7: D308.1 (A1), J301.16, J302.33, R315.2, R316.2; also elsewhere on the board
/scsi/~DBP: D309.1 (A1), J301.18, J302.34, R317.2, R318.2; also elsewhere on the board
/scsi/~IO: D318.1 (A1), J301.50, J302.50, R335.2, R336.2; also elsewhere on the board
/scsi/~MSG: D314.1 (A1), J301.42, J302.46, R327.2, R328.2; also elsewhere on the board
/scsi/~REQ: D317.1 (A1), J301.48, J302.49, R333.2, R334.2; also elsewhere on the board
/scsi/~RST: D313.1 (A1), J301.40, J302.45, R325.2, R326.2; also elsewhere on the board
/scsi/~SEL: D315.1 (A1), J301.44, J302.47, R329.2, R330.2; also elsewhere on the board
GND: C301.2, C302.2, C303.2, C304.2, C305.2, C306.2, C307.2, C308.2, D301.2 (A2), D302.2 (A2), D303.2 (A2), D304.2 (A2), D305.2 (A2), D306.2 (A2), D307.2 (A2), D308.2 (A2), D309.2 (A2), D310.2 (A2), D311.2 (A2), D312.2 (A2), D313.2 (A2), D314.2 (A2), D315.2 (A2), D316.2 (A2), D317.2 (A2), D318.2 (A2), J301.1, J301.3, J301.5, J301.7, J301.9, J301.11, J301.13, J301.15, J301.17, J301.19, J301.20, J301.21, J301.22, J301.29, J301.30, J301.31, J301.33, J301.34, J301.35, J301.37, J301.39, J301.41, J301.43, J301.45, J301.47, J301.49, J302.1, J302.2, J302.3, J302.4, J302.5, J302.6, J302.7, J302.8, J302.9, J302.10, J302.11, J302.15, J302.16, J302.17, J302.18, J302.19, J302.20, J302.21, J302.22, J302.23, J302.24, J302.25, J302.35, J302.36, J302.40, J302.42, J303.1, J303.2, J303.11, J303.12, J303.21, J303.22, J303.31, J303.32, R1.2, R2.2, R3.2, R4.2, R337.2, R338.2, R339.2, R340.2, R342.2, R343.2, U301.10 (GND), U302.10 (GND), U303.10 (GND); also elsewhere on the board
unnamed: J302.SH (Shield), R343.1
unnamed: R342.1, SW301.4
TERMPWR: C307.1, C308.1, J301.26, J302.38; also elsewhere on the board
VTERMINATOR: C301.1, C302.1, C303.1, C304.1, C305.1, C306.1, R341.1, U301.1 (A->B), U301.2 (A0), U301.3 (A1), U301.4 (A2), U301.5 (A3), U301.6 (A4), U301.7 (A5), U301.8 (A6), U301.9 (A7), U301.20 (VCC), U302.1 (A->B), U302.2 (A0), U302.3 (A1), U302.4 (A2), U302.5 (A3), U302.6 (A4), U302.7 (A5), U302.8 (A6), U302.9 (A7), U302.20 (VCC), U303.1 (A->B), U303.2 (A0), U303.3 (A1), U303.4 (A2), U303.5 (A3), U303.6 (A4), U303.7 (A5), U303.8 (A6), U303.9 (A7), U303.20 (VCC); also elsewhere on the board

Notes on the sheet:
Pins 1-32 copy the Digital Discovery's 2x16 DIN connector (reference manual Fig. 8); 33/34 spare. A standard 34-way ribbon runs to a 2x16-to-34 adapter board (pin n to pin n). Available signals: - the 18 bus lines (DB0..IO) - two MCU-connected markers GND on 1, 2, 11, 12, 21, 22, 31, 32. Each tap h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
SCSI: the same bus on both, wired by signal name from SCSI-2 Table 2 (IDC50 = contact set 1, HD50 = set 2).
Receive-only lines
Connectors
Active terminator
R301-R336: 220R 1 % 0402 (C25091), <= 35 mW each at 2.94 V into an asserted line. D301-D318: H5VUD5BB (C20615820), bidirectional, 0.3 pF, 5 V working. ESD protection: they clamp static discharges from the cable or a finger on the connector to GND before they reach the FET or the receiver. 0.3 pF ke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
Pin 25 (HD50 13) is OPEN: a reversed ribbon puts TERMPWR on a dead pin, not on ground. IDC50 even pins 20, 22, 30, 34 are GROUND.
SCSI-2 5.4.4: RESERVED lines 'shall be connected to ground' in end devices, 'should be open' otherwise. We are an end device: all four fitted. Remove R337-R340 and R1-R4 if the board ever sits mid-chain.
Per line: terminator pair (2 x 220R = 110R), ESD diode to GND, then the channel sheet (driver + receiver). Keep each cluster on its own bus trace by the connector. GATE (from the RP2350) and RX (to it) are sheet pins.
Switch state survives power-off and needs no firmware; DIP 2 lets firmware (expander P12) override it.
A1-A8 and DIR tie straight to the rail: DIR high = A->B, and bus-hold inputs mustn't get pull resistors. B7/B8 unused.
Terminator enable DIP switch
J303 logic-analyzer header (Digital Discovery DIN)
TERMINATOR_EN_INVERTED drives /OE on U301-U303: low = terminated. R341 pulls it up to 2.83 V (off). DIP 1 closes it to GND through R342: ~0.26 V = on. DIP 2 connects it to the expander pin (push-pull, so it can override R342). The expander powers up with its pins as inputs, so the switch default ho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
J302 SCSI HD50 (DNP)
MSG, C/D, REQ, I/O: only the target drives them (SCSI-2 Table 6), so no driver.
VTERMINATOR (2.83 V) -> SN74LVTH245A, A tied high -> TERMINATOR_OUT_<line> -> 2 x 220R per line (next to each line, right) -> bus. /OE high or unpowered: outputs high-Z. 6 lines per package.
Per-line driver and receiver
J301 SCSI IDC50 (fitted)
C307/C308: TERMPWR bulk, one beside each connector's TERMPWR pin (J301.26, J302.38).

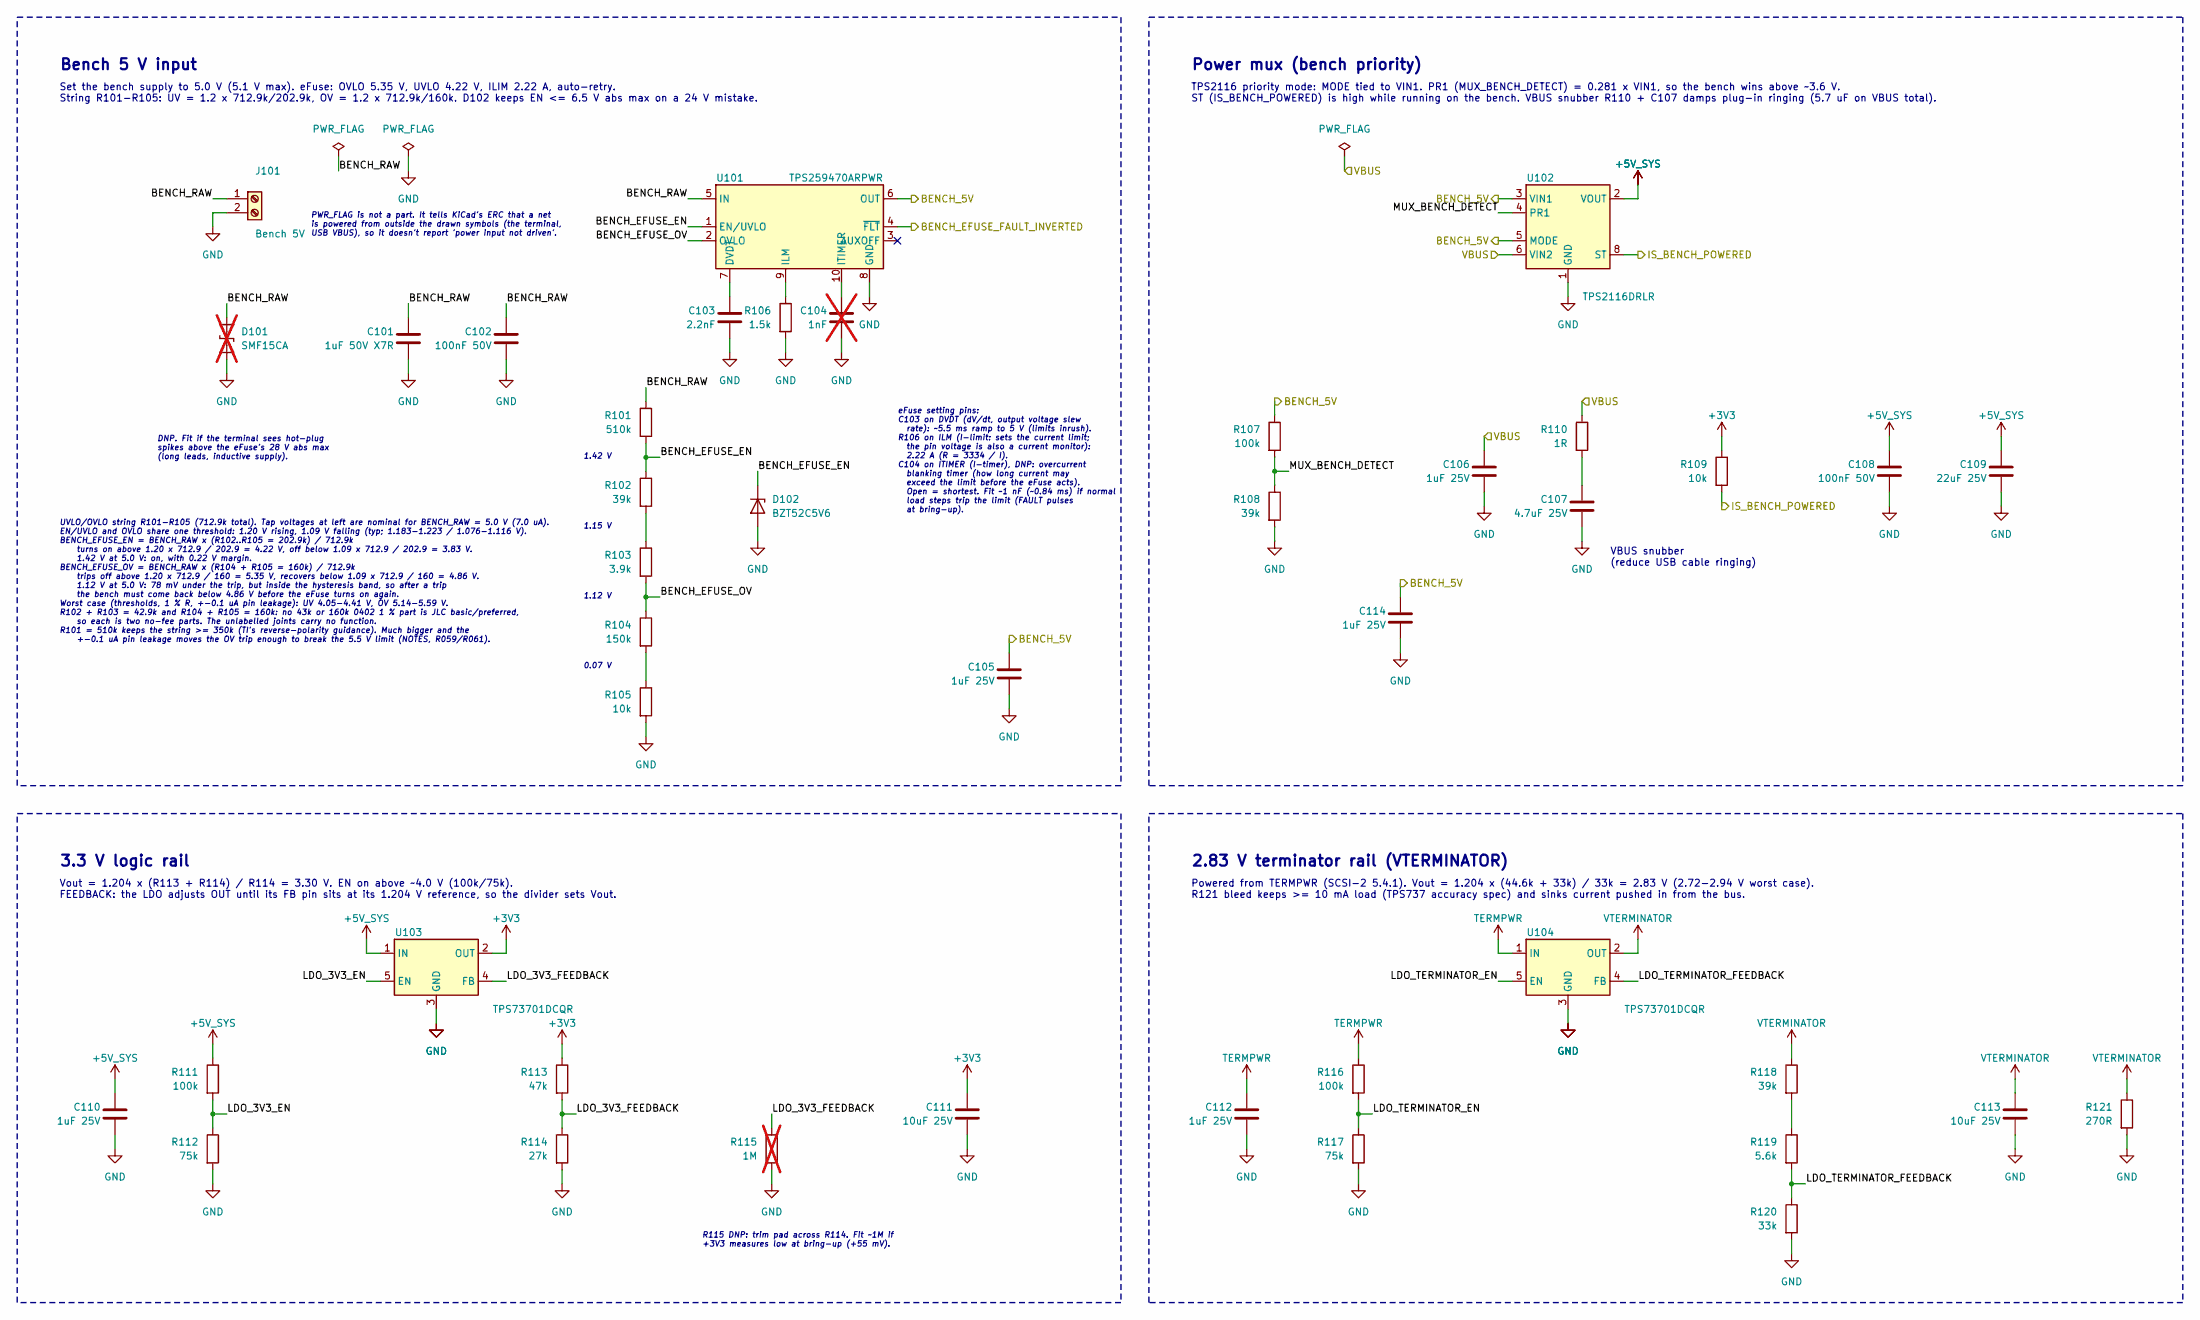
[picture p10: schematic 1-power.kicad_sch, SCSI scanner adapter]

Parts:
C101: 1uF 50V X7R; C_0805_2012Metric; LCSC C28323
C102, C108: 100nF 50V; C_0402_1005Metric; LCSC C307331
C103: 2.2nF; C_0402_1005Metric; LCSC C1531
C104: 1nF; C_0402_1005Metric; not fitted
C105, C106, C110, C112, C114: 1uF 25V; C_0402_1005Metric; LCSC C52923
C107: 4.7uF 25V; C_0805_2012Metric; LCSC C1779
C109: 22uF 25V; C_0805_2012Metric; LCSC C45783
C111, C113: 10uF 25V; C_0805_2012Metric; LCSC C15850
D101: SMF15CA; D_SOD-123F; LCSC C19077510; not fitted
D102: BZT52C5V6; D_SOD-123; LCSC C19077402
J101: Bench 5V; TerminalBlock_Kangnex_WJ500V-5.08-2P_1x02_P5.08mm_Horizontal; LCSC C8465
R101: 510k; R_0402_1005Metric; LCSC C11616
R102, R108, R118: 39k; R_0402_1005Metric; LCSC C25783
R103: 3.9k; R_0402_1005Metric; LCSC C51721
R104: 150k; R_0402_1005Metric; LCSC C25755
R105, R109: 10k; R_0402_1005Metric; LCSC C25744
R106: 1.5k; R_0402_1005Metric; LCSC C25867
R107, R111, R116: 100k; R_0402_1005Metric; LCSC C25741
R110: 1R; R_0603_1608Metric; LCSC C22936
R112, R117: 75k; R_0402_1005Metric; LCSC C25798
R113: 47k; R_0402_1005Metric; LCSC C25792
R114: 27k; R_0402_1005Metric; LCSC C25771
R115: 1M; R_0603_1608Metric; not fitted
R119: 5.6k; R_0402_1005Metric; LCSC C25908
R120: 33k; R_0402_1005Metric; LCSC C25779
R121: 270R; R_0603_1608Metric; LCSC C22966
U101: TPS259470ARPWR; Texas_RPW0010A_VQFN-HR-10_2x2mm_P0.45mm; LCSC C3662799
U102: TPS2116DRLR; SOT-583-8; LCSC C3235557
U103, U104: TPS73701DCQR; SOT-223-6; LCSC C56848

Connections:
+3V3: C111.1, R109.1, R113.1, U103.2 (OUT); also elsewhere on the board
+5V_SYS: C108.1, C109.1, C110.1, R111.1, U102.2 (VOUT), U102.7 (VOUT), U103.1 (IN); also elsewhere on the board
/BENCH_5V: C105.1, C114.1, R107.1, U101.6 (OUT), U102.3 (VIN1), U102.5 (MODE); also elsewhere on the board
/BENCH_EFUSE_FAULT_INVERTED: U101.4 (~FLT); also elsewhere on the board
/IS_BENCH_POWERED: R109.2, U102.8 (ST); also elsewhere on the board
/VBUS: C106.1, R110.1, U102.6 (VIN2); also elsewhere on the board
/power/BENCH_EFUSE_EN: D102.1 (K), R101.2, R102.1, U101.1 (EN/UVLO)
/power/BENCH_EFUSE_OV: R103.2, R104.1, U101.2 (OVLO)
/power/BENCH_RAW: C101.1, C102.1, D101.1 (A1), J101.1, R101.1, U101.5 (IN)
/power/LDO_3V3_EN: R111.2, R112.1, U103.5 (EN)
/power/LDO_3V3_FEEDBACK: R113.2, R114.1, R115.1, U103.4 (FB)
/power/LDO_TERMINATOR_EN: R116.2, R117.1, U104.5 (EN)
/power/LDO_TERMINATOR_FEEDBACK: R119.2, R120.1, U104.4 (FB)
/power/MUX_BENCH_DETECT: R107.2, R108.1, U102.4 (PR1)
GND: C101.2, C102.2, C103.2, C104.2, C105.2, C106.2, C107.2, C108.2, C109.2, C110.2, C111.2, C112.2, C113.2, C114.2, D101.2 (A2), D102.2 (A), J101.2, R105.2, R106.2, R108.2, R112.2, R114.2, R115.2, R117.2, R120.2, R121.2, U101.8 (GND), U102.1 (GND), U103.3 (GND), U103.6 (GND), U104.3 (GND), U104.6 (GND); also elsewhere on the board
unnamed: C107.1, R110.2
unnamed: R102.2, R103.1
unnamed: R104.2, R105.1
unnamed: R118.2, R119.1
unnamed: C103.1, U101.7 (DVDT)
unnamed: R106.1, U101.9 (ILM)
unnamed: C104.1, U101.10 (ITIMER)
TERMPWR: C112.1, R116.1, U104.1 (IN); also elsewhere on the board
VTERMINATOR: C113.1, R118.1, R121.1, U104.2 (OUT); also elsewhere on the board

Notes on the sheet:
0.07 V
1.12 V
R115 DNP: trim pad across R114. Fit ~1M if +3V3 measures low at bring-up (+55 mV).
Powered from TERMPWR (SCSI-2 5.4.1). Vout = 1.204 x (44.6k + 33k) / 33k = 2.83 V (2.72-2.94 V worst case). R121 bleed keeps >= 10 mA load (TPS737 accuracy spec) and sinks current pushed in from the bus.
3.3 V logic rail
Bench 5 V input
Set the bench supply to 5.0 V (5.1 V max). eFuse: OVLO 5.35 V, UVLO 4.22 V, ILIM 2.22 A, auto-retry. String R101-R105: UV = 1.2 x 712.9k/202.9k, OV = 1.2 x 712.9k/160k. D102 keeps EN <= 6.5 V abs max on a 24 V mistake.
UVLO/OVLO string R101-R105 (712.9k total). Tap voltages at left are nominal for BENCH_RAW = 5.0 V (7.0 uA). EN/UVLO and OVLO share one threshold: 1.20 V rising, 1.09 V falling (typ; 1.183-1.223 / 1.076-1.116 V). BENCH_EFUSE_EN = BENCH_RAW x (R102..R105 = 202.9k) / 712.9k turns on above 1.20 x 712.9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
PWR_FLAG is not a part. It tells KiCad's ERC that a net is powered from outside the drawn symbols (the terminal, USB VBUS), so it doesn't report 'power input not driven'.
eFuse setting pins: C103 on DVDT (dV/dt, output voltage slew rate): ~5.5 ms ramp to 5 V (limits inrush). R106 on ILM (I-limit: sets the current limit; the pin voltage is also a current monitor): 2.22 A (R = 3334 / I). C104 on ITIMER (I-timer), DNP: overcurrent blanking timer (how long current may e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
1.42 V
2.83 V terminator rail (VTERMINATOR)
Power mux (bench priority)
Vout = 1.204 x (R113 + R114) / R114 = 3.30 V. EN on above ~4.0 V (100k/75k). FEEDBACK: the LDO adjusts OUT until its FB pin sits at its 1.204 V reference, so the divider sets Vout.
TPS2116 priority mode: MODE tied to VIN1. PR1 (MUX_BENCH_DETECT) = 0.281 x VIN1, so the bench wins above ~3.6 V. ST (IS_BENCH_POWERED) is high while running on the bench. VBUS snubber R110 + C107 damps plug-in ringing (5.7 uF on VBUS total).
DNP. Fit if the terminal sees hot-plug spikes above the eFuse's 28 V abs max (long leads, inductive supply).
1.15 V
VBUS snubber (reduce USB cable ringing)

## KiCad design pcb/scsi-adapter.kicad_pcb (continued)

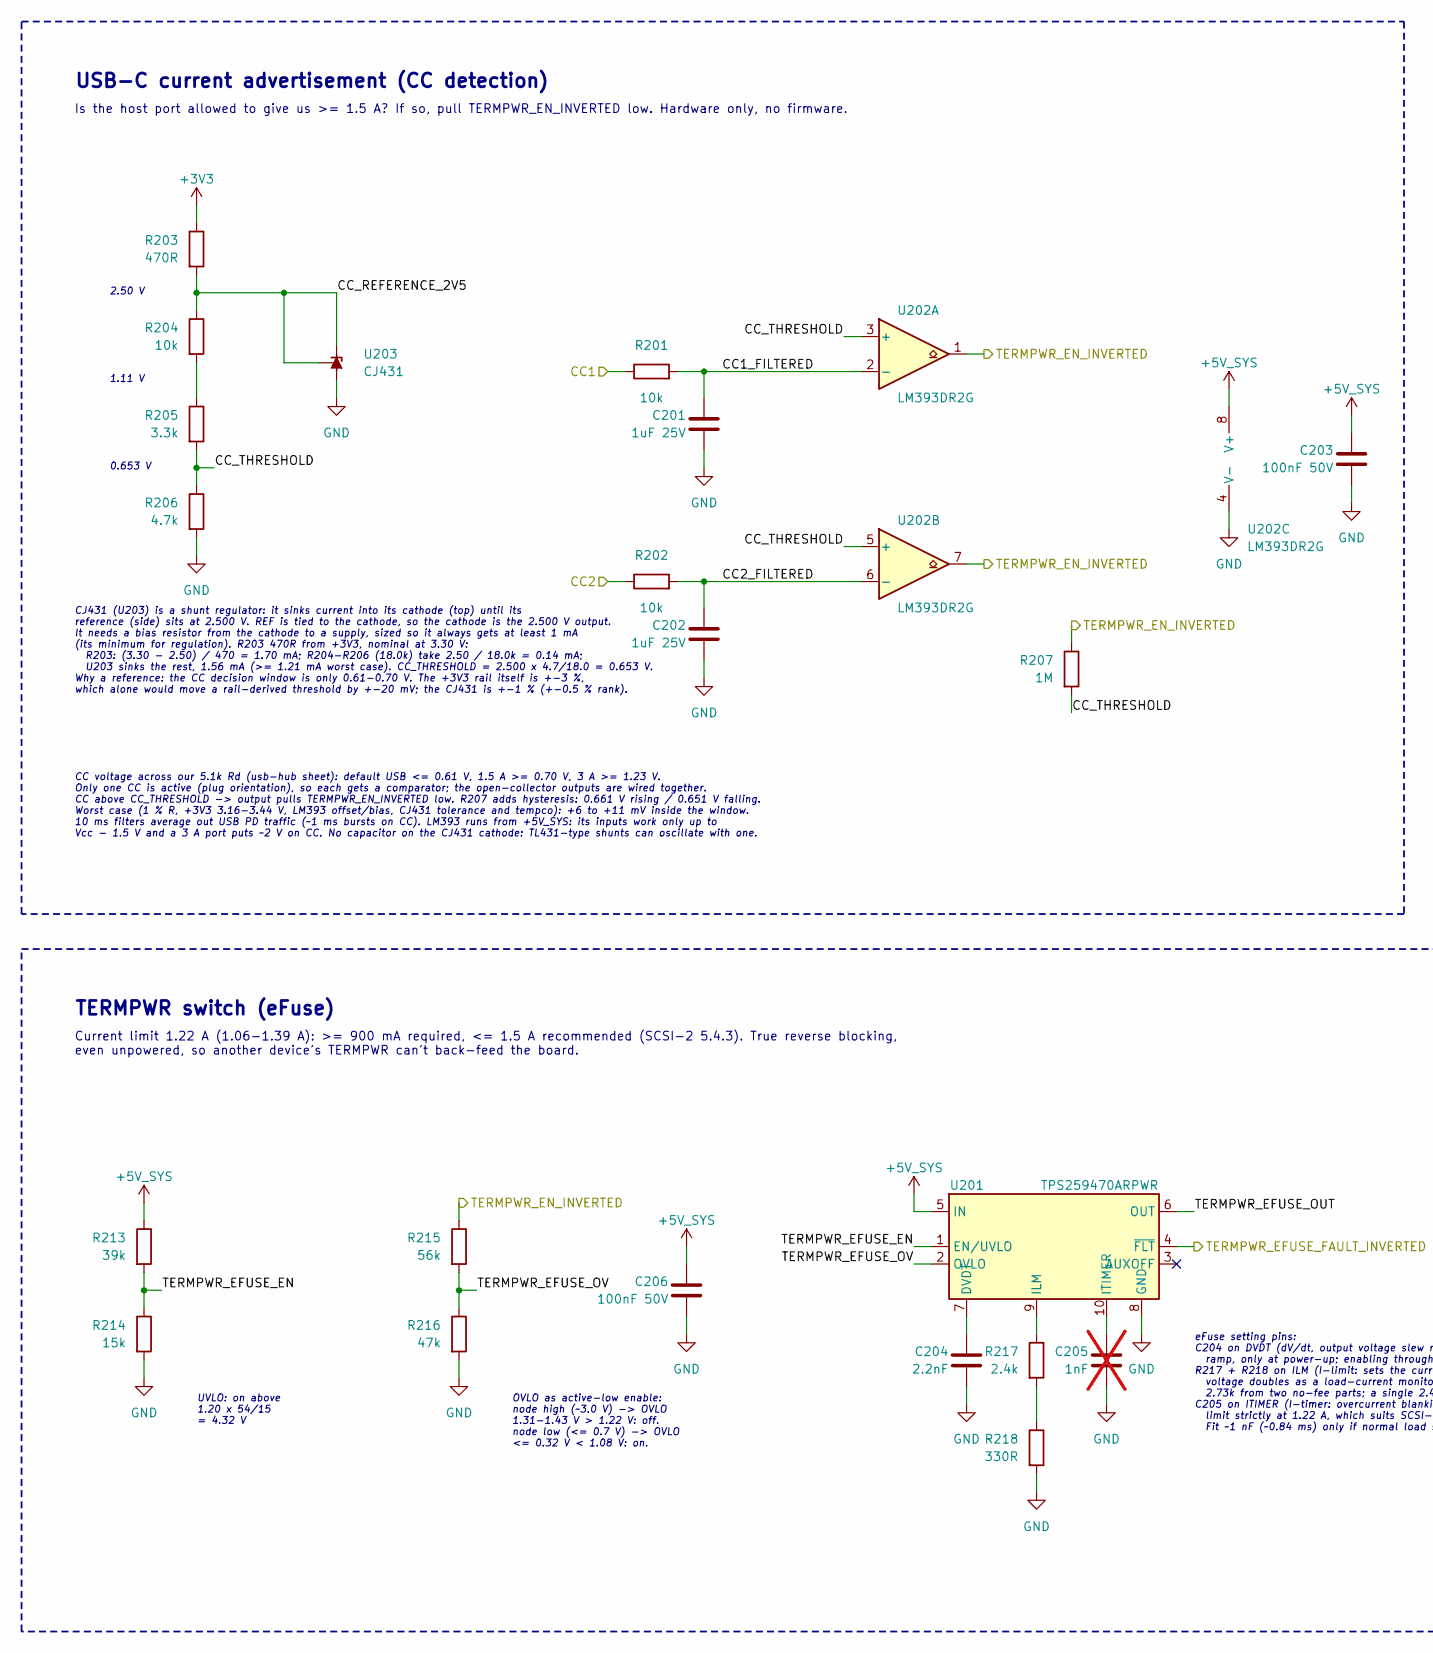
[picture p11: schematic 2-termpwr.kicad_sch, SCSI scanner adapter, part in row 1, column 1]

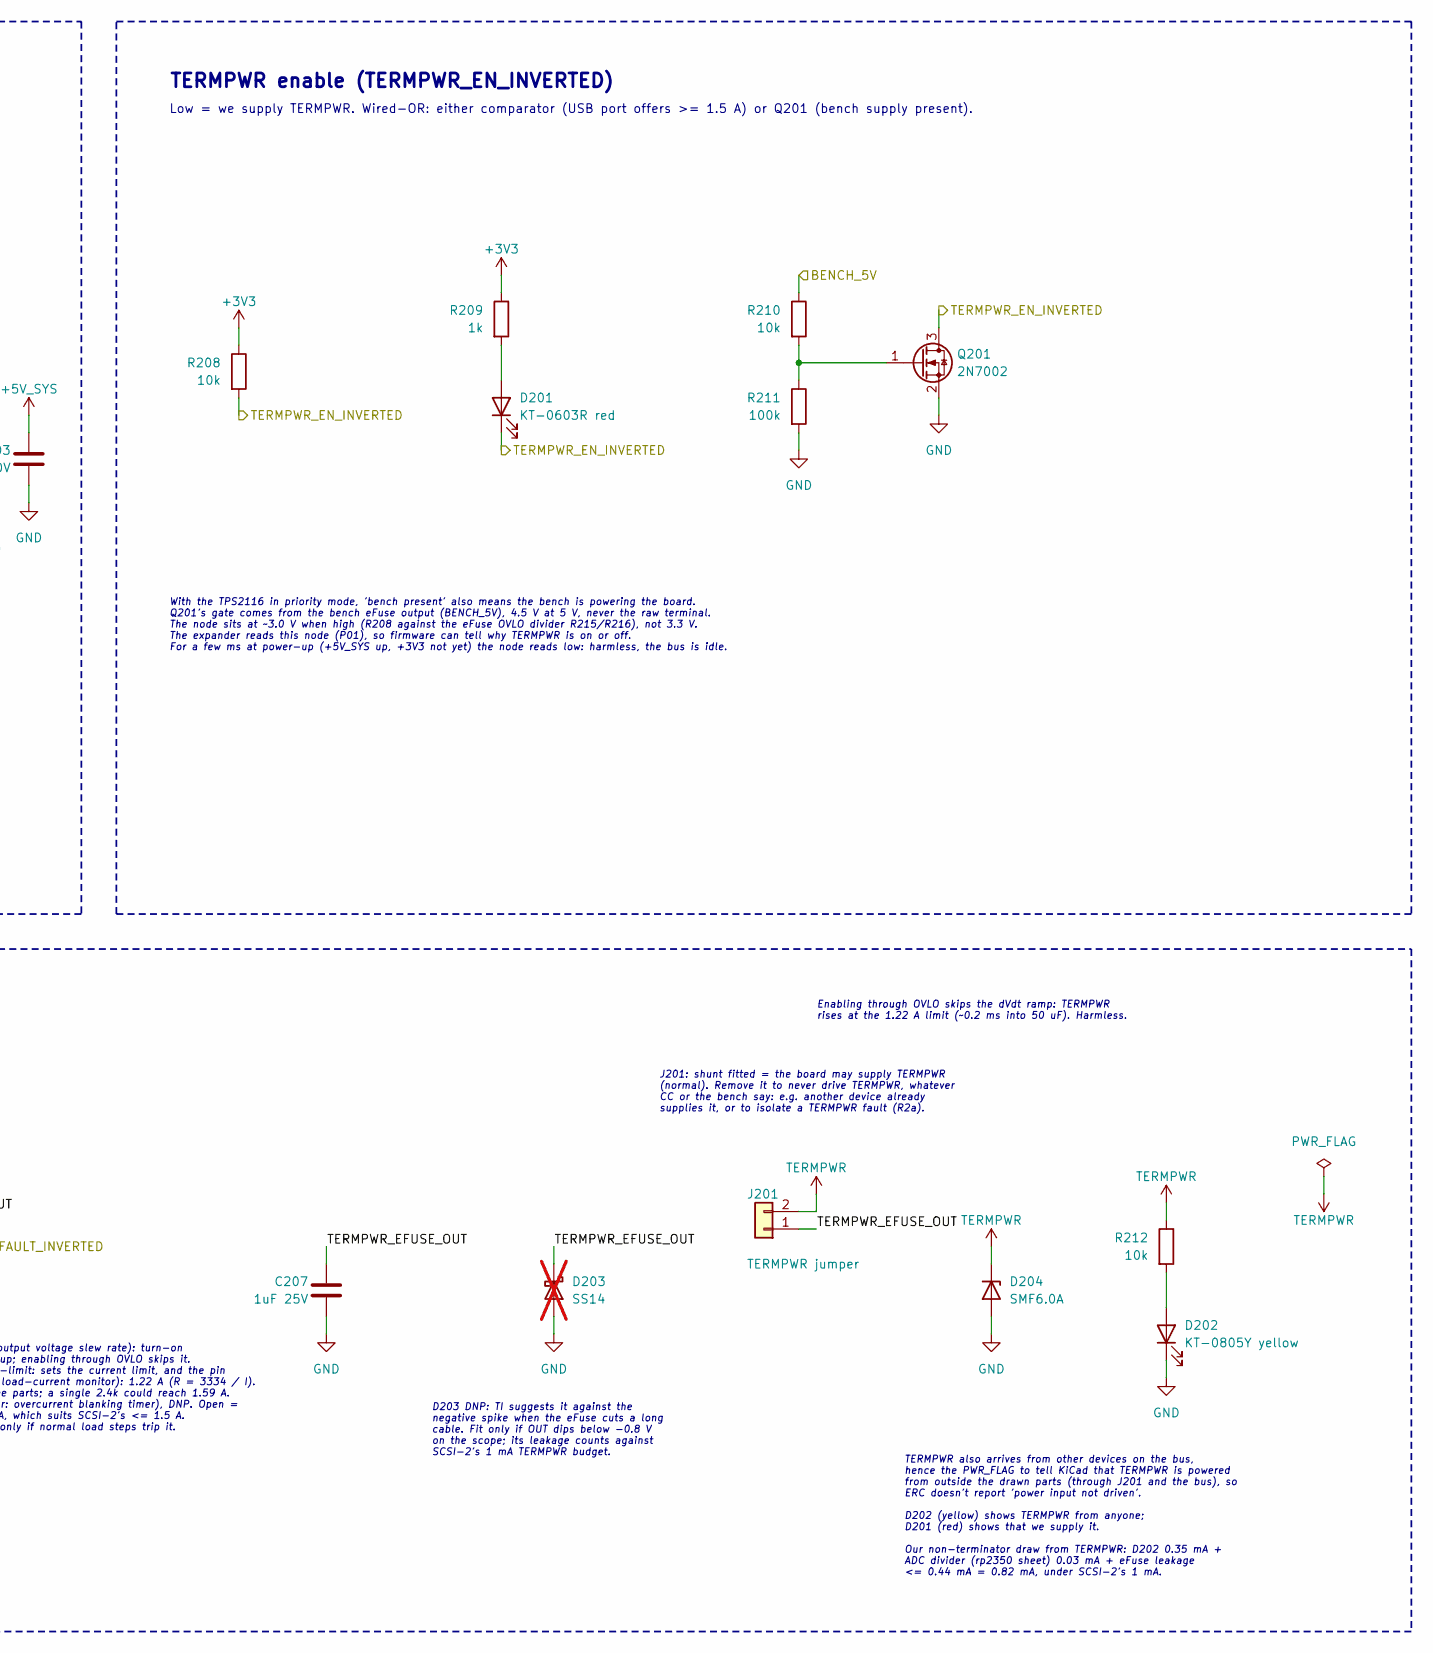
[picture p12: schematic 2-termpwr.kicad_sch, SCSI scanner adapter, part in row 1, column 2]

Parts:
C201, C202, C207: 1uF 25V; C_0402_1005Metric; LCSC C52923
C203, C206: 100nF 50V; C_0402_1005Metric; LCSC C307331
C204: 2.2nF; C_0402_1005Metric; LCSC C1531
C205: 1nF; C_0402_1005Metric; not fitted
D201: KT-0603R red; LED_0603_1608Metric; LCSC C2286
D202: KT-0805Y yellow; LED_0805_2012Metric; LCSC C2296
D203: SS14; D_SMA; LCSC C2480; not fitted
D204: SMF6.0A; D_SOD-123F; LCSC C19077499
J201: TERMPWR jumper; PinHeader_1x02_P2.54mm_Vertical
Q201: 2N7002; SOT-23; LCSC C8545
R201, R202, R204, R208, R210, R212: 10k; R_0402_1005Metric; LCSC C25744
R203: 470R; R_0402_1005Metric; LCSC C25117
R205: 3.3k; R_0402_1005Metric; LCSC C25890
R206: 4.7k; R_0402_1005Metric; LCSC C25900
R207: 1M; R_0402_1005Metric; LCSC C26083
R209: 1k; R_0402_1005Metric; LCSC C11702
R211: 100k; R_0402_1005Metric; LCSC C25741
R213: 39k; R_0402_1005Metric; LCSC C25783
R214: 15k; R_0402_1005Metric; LCSC C25756
R215: 56k; R_0402_1005Metric; LCSC C25796
R216: 47k; R_0402_1005Metric; LCSC C25792
R217: 2.4k; R_0402_1005Metric; LCSC C25882
R218: 330R; R_0402_1005Metric; LCSC C25104
U201: TPS259470ARPWR; Texas_RPW0010A_VQFN-HR-10_2x2mm_P0.45mm; LCSC C3662799
U202: LM393DR2G; SOIC-8_3.9x4.9mm_P1.27mm; LCSC C7955
U203: CJ431; SOT-23; LCSC C3113

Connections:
+3V3: R203.1, R208.1, R209.1; also elsewhere on the board
+5V_SYS: C203.1, C206.1, R213.1, U201.5 (IN), U202.8 (V+); also elsewhere on the board
/BENCH_5V: R210.1; also elsewhere on the board
/CC1: R201.1; also elsewhere on the board
/CC2: R202.1; also elsewhere on the board
/TERMPWR_EFUSE_FAULT_INVERTED: U201.4 (~FLT); also elsewhere on the board
/TERMPWR_EN_INVERTED: D201.1 (K), Q201.3 (D), R207.1, R208.2, R215.1, U202.1, U202.7; also elsewhere on the board
/termpwr/CC1_FILTERED: C201.1, R201.2, U202.2 (-)
/termpwr/CC2_FILTERED: C202.1, R202.2, U202.6 (-)
/termpwr/CC_REFERENCE_2V5: R203.2, R204.1, U203.1 (REF), U203.2 (K)
/termpwr/CC_THRESHOLD: R205.2, R206.1, R207.2, U202.3 (+), U202.5 (+)
/termpwr/TERMPWR_EFUSE_EN: R213.2, R214.1, U201.1 (EN/UVLO)
/termpwr/TERMPWR_EFUSE_OUT: C207.1, D203.1 (K), J201.1, U201.6 (OUT)
/termpwr/TERMPWR_EFUSE_OV: R215.2, R216.1, U201.2 (OVLO)
GND: C201.2, C202.2, C203.2, C204.2, C205.2, C206.2, C207.2, D202.1 (K), D203.2 (A), D204.2 (A), Q201.2 (S), R206.2, R211.2, R214.2, R216.2, R218.2, U201.8 (GND), U202.4 (V-), U203.3 (A); also elsewhere on the board
unnamed: D201.2 (A), R209.2
unnamed: D202.2 (A), R212.2
unnamed: Q201.1 (G), R210.2, R211.1
unnamed: R204.2, R205.1
unnamed: R217.2, R218.1
unnamed: C204.1, U201.7 (DVDT)
unnamed: R217.1, U201.9 (ILM)
unnamed: C205.1, U201.10 (ITIMER)
TERMPWR: D204.1 (K), J201.2, R212.1; also elsewhere on the board

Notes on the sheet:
With the TPS2116 in priority mode, 'bench present' also means the bench is powering the board. Q201's gate comes from the bench eFuse output (BENCH_5V), 4.5 V at 5 V, never the raw terminal. The node sits at ~3.0 V when high (R208 against the eFuse OVLO divider R215/R216), not 3.3 V. The expander r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
Current limit 1.22 A (1.06-1.39 A): >= 900 mA required, <= 1.5 A recommended (SCSI-2 5.4.3). True reverse blocking, even unpowered, so another device's TERMPWR can't back-feed the board.
Enabling through OVLO skips the dVdt ramp: TERMPWR rises at the 1.22 A limit (~0.2 ms into 50 uF). Harmless.
CC voltage across our 5.1k Rd (usb-hub sheet): default USB <= 0.61 V, 1.5 A >= 0.70 V, 3 A >= 1.23 V. Only one CC is active (plug orientation), so each gets a comparator; the open-collector outputs are wired together. CC above CC_THRESHOLD -> output pulls TERMPWR_EN_INVERTED low. R207 adds hysteres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
USB-C current advertisement (CC detection)
TERMPWR enable (TERMPWR_EN_INVERTED)
0.653 V
J201: shunt fitted = the board may supply TERMPWR (normal). Remove it to never drive TERMPWR, whatever CC or the bench say: e.g. another device already supplies it, or to isolate a TERMPWR fault (R2a).
CJ431 (U203) is a shunt regulator: it sinks current into its cathode (top) until its reference (side) sits at 2.500 V. REF is tied to the cathode, so the cathode is the 2.500 V output. It needs a bias resistor from the cathode to a supply, sized so it always gets at least 1 mA (its minimum for regu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
2.50 V
1.11 V
TERMPWR switch (eFuse)
UVLO: on above 1.20 x 54/15 = 4.32 V
eFuse setting pins: C204 on DVDT (dV/dt, output voltage slew rate): turn-on ramp, only at power-up; enabling through OVLO skips it. R217 + R218 on ILM (I-limit: sets the current limit, and the pin voltage doubles as a load-current monitor): 1.22 A (R = 3334 / I). 2.73k from two no-fee parts; a sing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
Is the host port allowed to give us >= 1.5 A? If so, pull TERMPWR_EN_INVERTED low. Hardware only, no firmware.
Low = we supply TERMPWR. Wired-OR: either comparator (USB port offers >= 1.5 A) or Q201 (bench supply present).
D203 DNP: TI suggests it against the negative spike when the eFuse cuts a long cable. Fit only if OUT dips below -0.8 V on the scope; its leakage counts against SCSI-2's 1 mA TERMPWR budget.
TERMPWR also arrives from other devices on the bus, hence the PWR_FLAG to tell KiCad that TERMPWR is powered from outside the drawn parts (through J201 and the bus), so ERC doesn't report 'power input not driven'. D202 (yellow) shows TERMPWR from anyone; D201 (red) shows that we supply it. Our non-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
OVLO as active-low enable: node high (~3.0 V) -> OVLO 1.31-1.43 V > 1.22 V: off. node low (<= 0.7 V) -> OVLO <= 0.32 V < 1.08 V: on.


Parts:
C501, C503: 100nF; C_0402_1005Metric; LCSC C307331
C502: 10uF 25V; C_0805_2012Metric; LCSC C15850
D501, D504: KT-0805Y yellow; LED_0805_2012Metric; LCSC C2296
D502, D503: KT-0603R red; LED_0603_1608Metric; LCSC C2286
D505: KT-0805G green; LED_0805_2012Metric; LCSC C2297
J501: TF PUSH; microSD_SHOUHAN_TF-PUSH_PushPush_CardDetect; LCSC C393941
R501, R502: 4.7k; R_0402_1005Metric; LCSC C25900
R503, R506, R507, R508, R509, R510: 10k; R_0402_1005Metric; LCSC C25744
R504, R505, R511, R512: 1k; R_0402_1005Metric; LCSC C11702
R513: 470R; R_0402_1005Metric; LCSC C25117
TP501: INT; TestPoint_Pad_D1.5mm
TP502: +5V_SYS; TestPoint_Pad_D1.5mm
TP503: +3V3; TestPoint_Pad_D1.5mm
TP504: VTERM; TestPoint_Pad_D1.5mm
TP505: TERMPWR; TestPoint_Pad_D1.5mm
TP506: TP_EN; TestPoint_Pad_D1.5mm
TP507: GND; TestPoint_Pad_D1.5mm
TP508: P15; TestPoint_Pad_D1.5mm
TP509: P16; TestPoint_Pad_D1.5mm
TP510: P17; TestPoint_Pad_D1.5mm
U501: TCA9555PWR; TSSOP-24_4.4x7.8mm_P0.65mm; LCSC C465732

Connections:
+3V3: C501.1, C502.1, C503.1, J501.4 (VDD), R501.1, R502.1, R503.1, R504.1, R505.1, R506.1, R507.1, R508.1, R509.1, R510.1, R511.1, R512.1, R513.1, TP503.1, U501.24 (VCC); also elsewhere on the board
/BENCH_EFUSE_FAULT_INVERTED: U501.11 (P07); also elsewhere on the board
/FT232H_RESET_INVERTED: U501.16 (P13); also elsewhere on the board
/HUB_RESET_INVERTED: U501.17 (P14); also elsewhere on the board
/I2C_SCL: R502.2, U501.22 (SCL); also elsewhere on the board
/I2C_SDA: R501.2, U501.23 (SDA); also elsewhere on the board
/IS_BENCH_POWERED: U501.14 (P11); also elsewhere on the board
/SD_CLK: J501.5 (CLK); also elsewhere on the board
/SD_CMD: J501.3 (CMD), R506.2; also elsewhere on the board
/SD_D0: J501.7 (DAT0), R507.2; also elsewhere on the board
/TERMINATOR_EN_INVERTED_FIRMWARE: U501.15 (P12); also elsewhere on the board
/TERMPWR_EFUSE_FAULT_INVERTED: U501.4 (P00); also elsewhere on the board
/TERMPWR_EN_INVERTED: TP506.1, U501.5 (P01); also elsewhere on the board
/io/EXPANDER_INTERRUPT_INVERTED: R503.2, TP501.1, U501.1 (~INT); also elsewhere on the board
/io/EXPANDER_P15: TP508.1, U501.18 (P15); also elsewhere on the board
/io/EXPANDER_P16: TP509.1, U501.19 (P16); also elsewhere on the board
/io/EXPANDER_P17: TP510.1, U501.20 (P17); also elsewhere on the board
/io/LED_ACTIVITY_INVERTED: D502.1 (K), U501.9 (P05)
/io/LED_GREEN_INVERTED: D505.1 (K), U501.6 (P02)
/io/LED_RED_INVERTED: D503.1 (K), U501.8 (P04)
/io/LED_STATUS_INVERTED: D501.1 (K), U501.10 (P06)
/io/LED_YELLOW_INVERTED: D504.1 (K), U501.7 (P03)
/io/SD_CARD_DETECT: J501.9 (DET), U501.13 (P10)
/io/SD_D1: J501.8 (DAT1), R508.2
/io/SD_D2: J501.1 (DAT2), R509.2
/io/SD_D3: J501.2 (DAT3/CD), R510.2
GND: C501.2, C502.2, C503.2, J501.6 (VSS), J501.10 (SHIELD), TP507.1, U501.2 (A1), U501.3 (A2), U501.12 (GND), U501.21 (A0); also elsewhere on the board
unnamed: D501.2 (A), R504.2
unnamed: D502.2 (A), R505.2
unnamed: D503.2 (A), R511.2
unnamed: D504.2 (A), R512.2
unnamed: D505.2 (A), R513.2

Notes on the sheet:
I/O expander (TCA9555, I2C0 address 0x20)
Test points
LEDs
Bare pads for probing at bring-up (not on the BOM). P15-P17: spare expander pins; INT: the expander interrupt (firmware polls, so it goes nowhere else).
Pull-ups 10k (SD spec: 10-100k) on CMD and D0-D3. D3 doubles as card detect in SPI mode; we use the socket's switch instead (DET -> P10). DET = the drawing's 'Cd' pad; it switches against the shell (GND). P10's internal pull-up (TCA9555) is the only pull-up. Polarity (closed with or without a card)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
Slow signals: inputs and outputs are mixed across both ports to suit the routing (every pin has its own direction bit; see the table). All pins power up as inputs with ~100k pull-ups, so the board is safe with no firmware.
microSD (1-bit SDIO on PIO2)
Spill-over storage when the host stalls. CLK, CMD, D0 go to the RP2350 (through the rework links); D1-D3 are only pulled up.
1k: ~1.3 mA red/yellow. Green (KT-0805G, Vf 2.6-3.1 V at 5 mA) gets 470R: ~2.4 V at low current, so ~1.8 mA typical, >= ~0.7 mA at the top of the Vf spread.
FT232H_3V3 gets its own pad on the ft232h sheet.
Lit when the expander drives the pin low. P02-P04: spare, use decided in firmware.


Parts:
C701, C703: 4.7uF 10V; C_0402_1005Metric; LCSC C23733
C702, C704, C705, C706, C707, C708, C710, C712, C713, C714: 100nF; C_0402_1005Metric; LCSC C307331
C709, C711: 4.7uF; C_0402_1005Metric; LCSC C23733; not fitted
C715, C716: 15pF; C_0402_1005Metric; LCSC C1548
C717: 10nF; C_0402_1005Metric; LCSC C15195
FB701, FB702: 600R@100MHz; L_0603_1608Metric; LCSC C1002
R701: 12k 1%; R_0402_1005Metric; LCSC C25752
R702, R703, R705, R706: 10k; R_0402_1005Metric; LCSC C25744
R704: 2.2k; R_0402_1005Metric; LCSC C25879
TP701: FT232H_3V3; TestPoint_Pad_D1.5mm
U701: FT232HL; LQFP-48_7x7mm_P0.5mm; LCSC C51997
U702: 93LC56BT-I/OT; SOT-23-6; LCSC C190271
Y701: 12MHz ABM8-272-T3; Crystal_SMD_3225-4Pin_3.2x2.5mm; LCSC C20625731

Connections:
+5V_SYS: C701.1, C702.1, U701.40 (VREGIN); also elsewhere on the board
/FT232H_D4: U701.17 (ADBUS4); also elsewhere on the board
/FT232H_D5: U701.18 (ADBUS5); also elsewhere on the board
/FT232H_D6: U701.19 (ADBUS6); also elsewhere on the board
/FT232H_D7: U701.20 (ADBUS7); also elsewhere on the board
/FT232H_MIOSIO0: U701.13 (ADBUS0); also elsewhere on the board
/FT232H_MIOSIO1: U701.14 (ADBUS1); also elsewhere on the board
/FT232H_MIOSIO2: U701.15 (ADBUS2); also elsewhere on the board
/FT232H_MIOSIO3: U701.16 (ADBUS3); also elsewhere on the board
/FT232H_MISO: U701.26 (ACBUS2); also elsewhere on the board
/FT232H_RESET_INVERTED: C717.1, R702.2, U701.34 (~RESET); also elsewhere on the board
/FT232H_SCLK: U701.21 (ACBUS0); also elsewhere on the board
/FT232H_SS_N: U701.25 (ACBUS1); also elsewhere on the board
/FT232H_WRITE_INVERTED: R705.2, U701.27 (ACBUS3); also elsewhere on the board
/USB_FT_D+: U701.7 (DP); also elsewhere on the board
/USB_FT_D-: U701.6 (DM); also elsewhere on the board
/ft232h/FT232H_EECLK: U701.44 (EECLK), U702.4 (CLK)
/ft232h/FT232H_EECS: U701.45 (EECS), U702.5 (CS)
/ft232h/FT232H_EEDATA: R704.2, U701.43 (EEDATA), U702.3 (DI)
/ft232h/FT232H_EEPROM_DO: R703.2, R704.1, U702.1 (DO)
/ft232h/FT232H_REF: R701.1, U701.5 (REF)
/ft232h/FT232H_SIWU_N: R706.2, U701.28 (ACBUS4)
/ft232h/FT232H_VCCA: C712.1, U701.37 (VCCA)
/ft232h/FT232H_VCORE: C713.1, U701.38 (VCCCORE)
/ft232h/FT232H_VPHY: C708.1, C709.1, FB701.2, U701.3 (VPHY)
/ft232h/FT232H_VPLL: C710.1, C711.1, FB702.2, U701.8 (VPLL)
/ft232h/FT232H_XCSI: C715.1, U701.1 (XCSI), Y701.1
/ft232h/FT232H_XCSO: C716.1, U701.2 (XCSO), Y701.3
FT232H_3V3: C703.1, C704.1, C705.1, C706.1, C707.1, C714.1, FB701.1, FB702.1, R702.1, R703.1, R705.1, R706.1, TP701.1, U701.12 (VCCIO), U701.24 (VCCIO), U701.39 (VCCD), U701.46 (VCCIO), U702.6 (VCC); also elsewhere on the board
GND: C701.2, C702.2, C703.2, C704.2, C705.2, C706.2, C707.2, C708.2, C709.2, C710.2, C711.2, C712.2, C713.2, C714.2, C715.2, C716.2, C717.2, R701.2, U701.4 (AGND), U701.9 (AGND), U701.10 (GND), U701.11 (GND), U701.22 (GND), U701.23 (GND), U701.35 (GND), U701.36 (GND), U701.41 (AGND), U701.42 (TEST), U701.47 (GND), U701.48 (GND), U702.2 (GND), Y701.2 (G), Y701.4 (G); also elsewhere on the board

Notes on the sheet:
Holds FT1248 mode. Programmed over USB after assembly (USAGE.md). The 93LC46B won't work.
WR# (27) and SIWU# (28) are pulled up so the 245-FIFO fallback never floats them; harmless in FT1248 mode.
VREGIN from +5V_SYS. VCCD is then an OUTPUT: the chip's own 3.3 V (FT232H_3V3), feeding VCCIO x3, VPHY and VPLL (through 600R ferrites) and the EEPROM. Never connect FT232H_3V3 to the board's +3V3.
PWR_FLAGs: VPHY and VPLL are fed through ferrites (passive to ERC). U701 is a project copy of KiCad's FT232H with VCCD, EECS, EECLK typed as outputs. C709/C711 DNP: 4.7 uF pads per FTDI, fit if the PHY/PLL rails need more bulk.
12 MHz crystal (same ABM8 as the RP2350 and hub) with 2 x 15 pF; REF 12k 1 % (DS Table 3.2); RESET# 10k + 10 nF (the expander's P13 can also pull it low); WR#/SIWU# pull-ups for the FIFO fallback.
Support parts
FT1248 4-bit to the RP2350 (MIOSIO0-3, SCLK, SS_N, MISO; 33R series at the RP2350 end). The EEPROM selects FT1248 mode: without it the chip starts in UART mode. D4-D7 and WR# only reach the RP2350 through the unfitted rework links (245-FIFO fallback). SCLK/SS_N/MISO sit on the FIFO's RXF#/TXE#/RD# 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
EEDATA drives DI directly and reads DO through R704 (DS Table 3.3; the figure shows 2k).
FT232H (USB 2.0 high speed <-> FT1248)
ACBUS5/6/8/9: free (CBUS bit-bang possible later). ACBUS7 = PWRSAV#: leave open, with 'Suspend on ACBus7 Low' OFF in the EEPROM. TEST (42) to GND.
Power (DS Fig. 6.2, exactly)
Configuration EEPROM (93LC56B, required)

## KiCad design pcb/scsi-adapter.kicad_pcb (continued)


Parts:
C601: 10uF 25V; C_0805_2012Metric; LCSC C15850
C602, C603: 100nF; C_0402_1005Metric; LCSC C307331
C604, C605: DNP; C_0402_1005Metric; not fitted
D601, D602: H5VUD5BB; D_SOD-523; LCSC C20615820
D603, D604: H7VL10B; D_0402_1005Metric; LCSC C20615787
D605: SMF6.0A; D_SOD-123F; LCSC C19077499
D606: 1N5819WS; D_SOD-323; LCSC C191023
D607: KT-0805G green; LED_0805_2012Metric; LCSC C2297
J601: USB-C (HRO TYPE-C-31-M-12); USB_C_Receptacle_HRO_TYPE-C-31-M-12
R601, R602: 5.1k; R_0402_1005Metric; LCSC C25905
R603: 0R; R_0402_1005Metric; LCSC C17168
R604: 470R; R_0402_1005Metric; LCSC C25117
U601: CH334P; QFN-16-1EP_3x3mm_P0.5mm_EP1.75x1.75mm; LCSC C5373042
Y601: 12MHz ABM8-272-T3; Crystal_SMD_3225-4Pin_3.2x2.5mm; LCSC C20625731

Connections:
+3V3: C601.1, C602.1, C603.1, R604.1, U601.15 (V5), U601.16 (VDD33); also elsewhere on the board
/CC1: D603.1 (A1), J601.A5 (CC1), R601.1; also elsewhere on the board
/CC2: D604.1 (A1), J601.B5 (CC2), R602.1; also elsewhere on the board
/HUB_RESET_INVERTED: D606.1 (K); also elsewhere on the board
/USB_FT_D+: U601.10 (DP1); also elsewhere on the board
/USB_FT_D-: U601.9 (DM1); also elsewhere on the board
/USB_RP_D+: U601.8 (DP2); also elsewhere on the board
/USB_RP_D-: U601.7 (DM2); also elsewhere on the board
/VBUS: D605.1 (K), J601.A4 (VBUS), J601.A9 (VBUS), J601.B4 (VBUS), J601.B9 (VBUS); also elsewhere on the board
/usb-hub/HUB_ACTIVE_INVERTED: D607.1 (K), U601.14 (PGANG)
/usb-hub/HUB_XI: C604.1, U601.2 (XI), Y601.1
/usb-hub/HUB_XO: C605.1, U601.1 (XO), Y601.3
/usb-hub/USB_D+: D601.1 (A1), J601.A6 (D+), J601.B6 (D+), U601.12 (DPU)
/usb-hub/USB_D-: D602.1 (A1), J601.A7 (D-), J601.B7 (D-), U601.11 (DMU)
GND: C601.2, C602.2, C603.2, C604.2, C605.2, D601.2 (A2), D602.2 (A2), D603.2 (A2), D604.2 (A2), D605.2 (A), J601.A1 (GND), J601.A12 (GND), J601.B1 (GND), J601.B12 (GND), R601.2, R602.2, R603.2, U601.17 (GND), Y601.2 (G), Y601.4 (G); also elsewhere on the board
unnamed: D606.2 (A), U601.13 (~RESET/CDP)
unnamed: D607.2 (A), R604.2
unnamed: J601.S1 (SHIELD), R603.1

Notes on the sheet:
PGANG ('power gang': on bigger CH334 packages it selects ganged port power and overcurrent control; our reading, WCH doesn't spell it out). Its internal pull-up keeps the default mode at reset; afterwards it outputs low while the hub is active, high in suspend. D607 is the 'hub active' LED on it (d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
C604/C605 DNP: the CH334 has ~16 pF on each pin (datasheet V2.91 6.1), which suits the ABM8's CL 10 pF. Fit only if the oscillator is off-frequency or slow to start.
RESET#: no external pull-up. The internal ~25k means 'run'; a pin driven high at power-up would enable CDP charging and turn off hub sleep (WCH). The expander (P14) can only pull it low, via D606.
ESD at the connector
Clamp static from the cable or a finger to GND before it reaches the hub or the CC comparators. D+/D-: H5VUD5BB, 0.3 pF (fine at 480 Mbit/s). CC: H7VL10B, 7 V working (CC can sit near 5.5 V). VBUS: SMF6.0A, above VBUS's 5.5 V max. Place all five right at the receptacle.
Shell: 0R to GND (R603). Swap for 1M || 4.7 nF if EMC testing wants the shield separated from GND.
External 3.3 V mode: V5 and VDD33 both on +3V3 (its low-voltage reset can trip as high as 3.2 V, so no internal LDO). Known flaw: no VBUS sense, so on the bench supply with the host off, the 1.5k D+ pull-up back-drives the host. Switch the bench off first.
Upstream from the USB-C; port 1 -> FT232H (high speed, the scan data), port 2 -> RP2350 native USB (full speed: updates and console). The hub's transaction translators keep port 1 at full HS bandwidth. USB_D+/- and USB_FT_D+/- are 90R pairs (net class USB_HS); each segment <= ~15 mm.
USB-C receptacle (USB 2.0)
Both D+ pins and both D- pins are tied, so the plug works either way round. SBU unused. 5.1k Rd on each CC makes us a sink; the CC voltage tells the TERMPWR sheet the port's current.
D603/D604 are DFN1006 (1.0 x 0.6 mm); the 0402 footprint is a stand-in to check.
USB 2.0 hub (CH334P)
Hub active: lit while the hub isn't suspended.
Ports 3 and 4 unused (built-in pull-downs; leave open).

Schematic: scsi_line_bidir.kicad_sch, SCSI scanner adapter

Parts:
C901: 22pF C0G; C_0402_1005Metric; LCSC C1555; not fitted
C902: 100nF 50V; C_0402_1005Metric; LCSC C307331
Q901: FDV301N; SOT-23; LCSC C15310
R901, R903: 100R; R_0402_1005Metric; LCSC C25076
R902: 4.7k; R_0402_1005Metric; LCSC C25900
U901: 74LVC1G17GW; SOT-353_SC-70-5; LCSC C426705

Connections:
+3V3: C902.1, U901.5 (VCC); also elsewhere on the board
/DB0_GATE: R901.1; also elsewhere on the board
/DB0_RX: R903.1, U901.4; also elsewhere on the board
/scsi/DB0_LOGIC_ANALYZER: R903.2; also elsewhere on the board
/scsi/~DB0: Q901.3 (D), U901.2; also elsewhere on the board
GND: C901.2, C902.2, Q901.2 (S), R902.2, U901.3 (GND); also elsewhere on the board
unnamed: C901.1, Q901.1 (G), R901.2, R902.1

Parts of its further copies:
C1001, C1101, C1201, C1301, C1401, C1501, C1601, C1701, C1801, C1901, C2001, C2101, C2301: 22pF C0G; C_0402_1005Metric; LCSC C1555; not fitted
C1002, C1102, C1202, C1302, C1402, C1502, C1602, C1702, C1802, C1902, C2002, C2102, C2302: 100nF 50V; C_0402_1005Metric; LCSC C307331
Q1001, Q1101, Q1201, Q1301, Q1401, Q1501, Q1601, Q1701, Q1801, Q1901, Q2001, Q2101, Q2301: FDV301N; SOT-23; LCSC C15310
R1001, R1003, R1101, R1103, R1201, R1203, R1301, R1303, R1401, R1403, R1501, R1503, R1601, R1603, R1701, R1703, R1801, R1803, R1901, R1903, R2001, R2003, R2101, R2103, R2301, R2303: 100R; R_0402_1005Metric; LCSC C25076
R1002, R1102, R1202, R1302, R1402, R1502, R1602, R1702, R1802, R1902, R2002, R2102, R2302: 4.7k; R_0402_1005Metric; LCSC C25900
U1001, U1101, U1201, U1301, U1401, U1501, U1601, U1701, U1801, U1901, U2001, U2101, U2301: 74LVC1G17GW; SOT-353_SC-70-5; LCSC C426705

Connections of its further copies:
+3V3: C1002.1, C1102.1, C1202.1, C1302.1, C1402.1, C1502.1, C1602.1, C1702.1, C1802.1, C1902.1, C2002.1, C2102.1, C2302.1, U1001.5 (VCC), U1101.5 (VCC), U1201.5 (VCC), U1301.5 (VCC), U1401.5 (VCC), U1501.5 (VCC), U1601.5 (VCC), U1701.5 (VCC), U1801.5 (VCC), U1901.5 (VCC), U2001.5 (VCC), U2101.5 (VCC), U2301.5 (VCC); also elsewhere on the board
/ACK_GATE: R2001.1; also elsewhere on the board
/ACK_RX: R2003.1, U2001.4; also elsewhere on the board
/ATN_GATE: R1801.1; also elsewhere on the board
/ATN_RX: R1803.1, U1801.4; also elsewhere on the board
/BSY_GATE: R1901.1; also elsewhere on the board
/BSY_RX: R1903.1, U1901.4; also elsewhere on the board
/DB1_GATE: R1001.1; also elsewhere on the board
/DB1_RX: R1003.1, U1001.4; also elsewhere on the board
/DB2_GATE: R1101.1; also elsewhere on the board
/DB2_RX: R1103.1, U1101.4; also elsewhere on the board
/DB3_GATE: R1201.1; also elsewhere on the board
/DB3_RX: R1203.1, U1201.4; also elsewhere on the board
/DB4_GATE: R1301.1; also elsewhere on the board
/DB4_RX: R1303.1, U1301.4; also elsewhere on the board
/DB5_GATE: R1401.1; also elsewhere on the board
/DB5_RX: R1403.1, U1401.4; also elsewhere on the board
/DB6_GATE: R1501.1; also elsewhere on the board
/DB6_RX: R1503.1, U1501.4; also elsewhere on the board
/DB7_GATE: R1601.1; also elsewhere on the board
/DB7_RX: R1603.1, U1601.4; also elsewhere on the board
/DBP_GATE: R1701.1; also elsewhere on the board
/DBP_RX: R1703.1, U1701.4; also elsewhere on the board
/RST_GATE: R2101.1; also elsewhere on the board
/RST_RX: R2103.1, U2101.4; also elsewhere on the board
/SEL_GATE: R2301.1; also elsewhere on the board
/SEL_RX: R2303.1, U2301.4; also elsewhere on the board
/scsi/ACK_LOGIC_ANALYZER: R2003.2; also elsewhere on the board
/scsi/ATN_LOGIC_ANALYZER: R1803.2; also elsewhere on the board
/scsi/BSY_LOGIC_ANALYZER: R1903.2; also elsewhere on the board
/scsi/DB1_LOGIC_ANALYZER: R1003.2; also elsewhere on the board
/scsi/DB2_LOGIC_ANALYZER: R1103.2; also elsewhere on the board
/scsi/DB3_LOGIC_ANALYZER: R1203.2; also elsewhere on the board
/scsi/DB4_LOGIC_ANALYZER: R1303.2; also elsewhere on the board
/scsi/DB5_LOGIC_ANALYZER: R1403.2; also elsewhere on the board
/scsi/DB6_LOGIC_ANALYZER: R1503.2; also elsewhere on the board
/scsi/DB7_LOGIC_ANALYZER: R1603.2; also elsewhere on the board
/scsi/DBP_LOGIC_ANALYZER: R1703.2; also elsewhere on the board
/scsi/RST_LOGIC_ANALYZER: R2103.2; also elsewhere on the board
/scsi/SEL_LOGIC_ANALYZER: R2303.2; also elsewhere on the board
/scsi/~ACK: Q2001.3 (D), U2001.2; also elsewhere on the board
/scsi/~ATN: Q1801.3 (D), U1801.2; also elsewhere on the board
/scsi/~BSY: Q1901.3 (D), U1901.2; also elsewhere on the board
/scsi/~DB1: Q1001.3 (D), U1001.2; also elsewhere on the board
/scsi/~DB2: Q1101.3 (D), U1101.2; also elsewhere on the board
/scsi/~DB3: Q1201.3 (D), U1201.2; also elsewhere on the board
/scsi/~DB4: Q1301.3 (D), U1301.2; also elsewhere on the board
/scsi/~DB5: Q1401.3 (D), U1401.2; also elsewhere on the board
/scsi/~DB6: Q1501.3 (D), U1501.2; also elsewhere on the board
/scsi/~DB7: Q1601.3 (D), U1601.2; also elsewhere on the board
/scsi/~DBP: Q1701.3 (D), U1701.2; also elsewhere on the board
/scsi/~RST: Q2101.3 (D), U2101.2; also elsewhere on the board
/scsi/~SEL: Q2301.3 (D), U2301.2; also elsewhere on the board
GND: C1001.2, C1002.2, C1101.2, C1102.2, C1201.2, C1202.2, C1301.2, C1302.2, C1401.2, C1402.2, C1501.2, C1502.2, C1601.2, C1602.2, C1701.2, C1702.2, C1801.2, C1802.2, C1901.2, C1902.2, C2001.2, C2002.2, C2101.2, C2102.2, C2301.2, C2302.2, Q1001.2 (S), Q1101.2 (S), Q1201.2 (S), Q1301.2 (S), Q1401.2 (S), Q1501.2 (S), Q1601.2 (S), Q1701.2 (S), Q1801.2 (S), Q1901.2 (S), Q2001.2 (S), Q2101.2 (S), Q2301.2 (S), R1002.2, R1102.2, R1202.2, R1302.2, R1402.2, R1502.2, R1602.2, R1702.2, R1802.2, R1902.2, R2002.2, R2102.2, R2302.2, U1001.3 (GND), U1101.3 (GND), U1201.3 (GND), U1301.3 (GND), U1401.3 (GND), U1501.3 (GND), U1601.3 (GND), U1701.3 (GND), U1801.3 (GND), U1901.3 (GND), U2001.3 (GND), U2101.3 (GND), U2301.3 (GND); also elsewhere on the board
unnamed: C1001.1, Q1001.1 (G), R1001.2, R1002.1
unnamed: C1101.1, Q1101.1 (G), R1101.2, R1102.1
unnamed: C1201.1, Q1201.1 (G), R1201.2, R1202.1
unnamed: C1301.1, Q1301.1 (G), R1301.2, R1302.1
unnamed: C1401.1, Q1401.1 (G), R1401.2, R1402.1
unnamed: C1501.1, Q1501.1 (G), R1501.2, R1502.1
unnamed: C1601.1, Q1601.1 (G), R1601.2, R1602.1
unnamed: C1701.1, Q1701.1 (G), R1701.2, R1702.1
unnamed: C1801.1, Q1801.1 (G), R1801.2, R1802.1
unnamed: C1901.1, Q1901.1 (G), R1901.2, R1902.1
unnamed: C2001.1, Q2001.1 (G), R2001.2, R2002.1
unnamed: C2101.1, Q2101.1 (G), R2101.2, R2102.1
unnamed: C2301.1, Q2301.1 (G), R2301.2, R2302.1

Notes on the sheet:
SCSI line with driver
C1 DNP: fit only if a rising bus edge, coupled through the FET's gate-drain capacitance, makes a visible dip or step (board off, G4 driving the bus).
x14: DB0-7, DBP, ATN, BSY, ACK, RST, SEL (pages 9-21 except MSG). References: page x 100 + n. Driver: GATE high = line asserted (Q1 pulls it to ~0.2 V). Receiver: RX low = line asserted (the RP2350 pad inverts it). Place this cluster on its own bus trace next to the connector.
R3 feeds the logic-analyzer header; the RP2350 input takes RX straight from U1.

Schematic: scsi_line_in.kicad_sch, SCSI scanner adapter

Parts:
C2202: 100nF 50V; C_0402_1005Metric; LCSC C307331
R2203: 100R; R_0402_1005Metric; LCSC C25076
U2201: 74LVC1G17GW; SOT-353_SC-70-5; LCSC C426705

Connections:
+3V3: C2202.1, U2201.5 (VCC); also elsewhere on the board
/MSG_RX: R2203.1, U2201.4; also elsewhere on the board
/scsi/MSG_LOGIC_ANALYZER: R2203.2; also elsewhere on the board
/scsi/~MSG: U2201.2; also elsewhere on the board
GND: C2202.2, U2201.3 (GND); also elsewhere on the board

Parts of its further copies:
C2402, C2502, C2602: 100nF 50V; C_0402_1005Metric; LCSC C307331
R2403, R2503, R2603: 100R; R_0402_1005Metric; LCSC C25076
U2401, U2501, U2601: 74LVC1G17GW; SOT-353_SC-70-5; LCSC C426705

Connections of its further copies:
+3V3: C2402.1, C2502.1, C2602.1, U2401.5 (VCC), U2501.5 (VCC), U2601.5 (VCC); also elsewhere on the board
/CD_RX: R2403.1, U2401.4; also elsewhere on the board
/IO_RX: R2603.1, U2601.4; also elsewhere on the board
/REQ_RX: R2503.1, U2501.4; also elsewhere on the board
/scsi/CD_LOGIC_ANALYZER: R2403.2; also elsewhere on the board
/scsi/IO_LOGIC_ANALYZER: R2603.2; also elsewhere on the board
/scsi/REQ_LOGIC_ANALYZER: R2503.2; also elsewhere on the board
/scsi/~CD: U2401.2; also elsewhere on the board
/scsi/~IO: U2601.2; also elsewhere on the board
/scsi/~REQ: U2501.2; also elsewhere on the board
GND: C2402.2, C2502.2, C2602.2, U2401.3 (GND), U2501.3 (GND), U2601.3 (GND); also elsewhere on the board

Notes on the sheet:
x4: MSG, C/D, REQ, I/O. The initiator never drives these (SCSI-2 Table 6: target-only). RX low = line asserted (the RP2350 pad inverts it). References: page x 100 + n.
SCSI line, receive only
R3 feeds the logic-analyzer header; the RP2350 input takes RX straight from U1.


Board: 4 copper layers, 120.0 x 90.0 mm, 412 parts (0 on the bottom side), 254 nets.

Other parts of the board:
5V_SYS: +5V_SYS; TestPoint_Pad_D1.5mm
+3V3: +3V3; TestPoint_Pad_D1.5mm
FT232H_3V3: FT232H_3V3; TestPoint_Pad_D1.5mm
GND: GND; TestPoint_Pad_D1.5mm
H1, H2, H3, H4: M3; MountingHole_3.2mm_M3
INTERRUPT_N: INT; TestPoint_Pad_D1.5mm
TERMPWR: TERMPWR; TestPoint_Pad_D1.5mm
TERMPWR_EN_N: TP_EN; TestPoint_Pad_D1.5mm
TEST-1: P15; TestPoint_Pad_D1.5mm
TEST-2: P16; TestPoint_Pad_D1.5mm
TEST-3: P17; TestPoint_Pad_D1.5mm
VTERMINATOR: VTERM; TestPoint_Pad_D1.5mm

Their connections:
+3V3: +3V3.1; also elsewhere on the board
+5V_SYS: 5V_SYS.1; also elsewhere on the board
/TERMPWR_EN_INVERTED: TERMPWR_EN_N.1; also elsewhere on the board
/io/EXPANDER_INTERRUPT_INVERTED: INTERRUPT_N.1; also elsewhere on the board
/io/EXPANDER_P15: TEST-1.1; also elsewhere on the board
/io/EXPANDER_P16: TEST-2.1; also elsewhere on the board
/io/EXPANDER_P17: TEST-3.1; also elsewhere on the board
FT232H_3V3: FT232H_3V3.1; also elsewhere on the board
GND: GND.1; also elsewhere on the board
TERMPWR: TERMPWR.1; also elsewhere on the board
VTERMINATOR: VTERMINATOR.1; also elsewhere on the board

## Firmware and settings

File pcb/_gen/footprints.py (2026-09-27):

"""Project footprints, written to pcb/scsi-adapter.pretty/.

Each footprint is built from its datasheet's land pattern, with the numbers written out here so they
can be checked against the drawing. Run: python3 pcb/_gen/footprints.py
"""
import os
import uuid

HERE = os.path.dirname(os.path.abspath(__file__))
LIB = os.path.join(HERE, "..", "scsi-adapter.pretty")


def uid(name, *k):
    """Stable UUIDs, so regenerating a footprint doesn't churn the file."""
    return str(uuid.uuid5(uuid.NAMESPACE_URL, "scsi-adapter-fp/" + name + "/" + "/".join(map(str, k))))


def f(v):
    return f"{v:.4f}".rstrip("0").rstrip(".") if v else "0"


class Footprint:
    def __init__(self, name, descr, tags, attr="smd"):
        self.name, self.descr, self.tags, self.attr = name, descr, tags, attr
        self.items = []
        self.n = 0

    def _u(self):
        self.n += 1
        return uid(self.name, self.n)

    def prop(self, key, value, x, y, layer, hide=False):
        h = "\n\t\t(hide yes)" if hide else ""
        self.items.append(f'\t(property "{key}" "{value}"\n\t\t(at {f(x)} {f(y)} 0)\n\t\t(unlocked yes)\n'
                          f'\t\t(layer "{layer}"){h}\n\t\t(uuid "{self._u()}")\n'
                          f'\t\t(effects\n\t\t\t(font\n\t\t\t\t(size 1 1)\n\t\t\t\t(thickness 0.15)\n\t\t\t)\n\t\t)\n\t)')

    def line(self, layer, x0, y0, x1, y1, w):
        self.items.append(f'\t(fp_line\n\t\t(start {f(x0)} {f(y0)})\n\t\t(end {f(x1)} {f(y1)})\n'
                          f'\t\t(stroke\n\t\t\t(width {w})\n\t\t\t(type default)\n\t\t)\n'
                          f'\t\t(layer "{layer}")\n\t\t(uuid "{self._u()}")\n\t)')

    def rect(self, layer, x0, y0, x1, y1, w):
        self.items.append(f'\t(fp_rect\n\t\t(start {f(x0)} {f(y0)})\n\t\t(end {f(x1)} {f(y1)})\n'
                          f'\t\t(stroke\n\t\t\t(width {w})\n\t\t\t(type default)\n\t\t)\n\t\t(fill no)\n'
                          f'\t\t(layer "{layer}")\n\t\t(uuid "{self._u()}")\n\t)')

    def poly(self, layer, pts, w, fill=True):
        p = " ".join(f"(xy {f(x)} {f(y)})" for x, y in pts)
        self.items.append(f'\t(fp_poly\n\t\t(pts {p})\n\t\t(stroke\n\t\t\t(width {w})\n\t\t\t(type solid)\n\t\t)\n'
                          f'\t\t(fill {"yes" if fill else "no"})\n\t\t(layer "{layer}")\n\t\t(uuid "{self._u()}")\n\t)')

    def text(self, layer, s, x, y, size=0.5):
        self.items.append(f'\t(fp_text user "{s}"\n\t\t(at {f(x)} {f(y)} 0)\n\t\t(unlocked yes)\n'
                          f'\t\t(layer "{layer}")\n\t\t(uuid "{self._u()}")\n\t\t(effects\n\t\t\t(font\n'
                          f'\t\t\t\t(size {size} {size})\n\t\t\t\t(thickness {size * 0.15:.3f})\n\t\t\t)\n\t\t)\n\t)')

    def smd(self, num, cx, cy, w, h, radius=0.0, layers=("F.Cu", "F.Mask", "F.Paste")):
        """Rectangular SMD pad, centre (cx, cy), size w x h, corner radius in mm."""
        ly = " ".join(f'"{l}"' for l in layers)
        shape = "roundrect" if radius else "rect"
        rr = f"\n\t\t(roundrect_rratio {radius / min(w, h):.4f})" if radius else ""
        self.items.append(f'\t(pad "{num}" smd {shape}\n\t\t(at {f(cx)} {f(cy)})\n\t\t(size {f(w)} {f(h)})\n'
                          f'\t\t(layers {ly}){rr}\n\t\t(uuid "{self._u()}")\n\t)')

    def tht(self, num, cx, cy, size, drill, shape="circle"):
        """Round through-hole pad; pin 1 gets shape='roundrect' (KiCad's pin-1 convention)."""
        rr = "\n\t\t(roundrect_rratio 0.25)" if shape == "roundrect" else ""
        self.items.append(f'\t(pad "{num}" thru_hole {shape}\n\t\t(at {f(cx)} {f(cy)})\n\t\t(size {f(size)} {f(size)})\n'
                          f'\t\t(drill {f(drill)})\n\t\t(layers "*.Cu" "*.Mask"){rr}\n\t\t(uuid "{self._u()}")\n\t)')

    def circle(self, layer, cx, cy, r, w):
        self.items.append(f'\t(fp_circle\n\t\t(center {f(cx)} {f(cy)})\n\t\t(end {f(cx + r)} {f(cy)})\n'
                          f'\t\t(stroke\n\t\t\t(width {w})\n\t\t\t(type default)\n\t\t)\n\t\t(fill no)\n'
                          f'\t\t(layer "{layer}")\n\t\t(uuid "{self._u()}")\n\t)')

    def npth_or_mp(self, cx, cy, size, drill, num=""):
        """Plated mounting hole (board lock / bracket); num="SH" ties it to a shield pin."""
        self.items.append(f'\t(pad "{num}" thru_hole circle\n\t\t(at {f(cx)} {f(cy)})\n\t\t(size {f(size)} {f(size)})\n'
                          f'\t\t(drill {f(drill)})\n\t\t(layers "*.Cu" "*.Mask")\n\t\t(uuid "{self._u()}")\n\t)')

    def npth(self, cx, cy, drill):
        """Non-plated hole (locating peg)."""
        self.items.append(f'\t(pad "" np_thru_hole circle\n\t\t(at {f(cx)} {f(cy)})\n\t\t(size {f(drill)} {f(drill)})\n'
                          f'\t\t(drill {f(drill)})\n\t\t(layers "*.Cu" "*.Mask")\n\t\t(uuid "{self._u()}")\n\t)')

    def custom(self, num, ax, ay, pts, layers=("F.Cu", "F.Mask")):
        """Custom-shape pad: a small rect anchor at (ax, ay) plus a filled polygon (absolute coords)."""
        ly = " ".join(f'"{l}"' for l in layers)
        p = " ".join(f"(xy {f(x - ax)} {f(y - ay)})" for x, y in pts)
        self.items.append(f'\t(pad "{num}" smd custom\n\t\t(at {f(ax)} {f(ay)})\n\t\t(size 0.2 0.2)\n'
                          f'\t\t(layers {ly})\n\t\t(options\n\t\t\t(clearance outline)\n\t\t\t(anchor rect)\n\t\t)\n'
                          f'\t\t(primitives\n\t\t\t(gr_poly\n\t\t\t\t(pts {p})\n\t\t\t\t(width 0)\n'
                          f'\t\t\t\t(fill yes)\n\t\t\t)\n\t\t)\n\t\t(uuid "{self._u()}")\n\t)')

    def model(self, path, offset=(0, 0, 0), rotate=(0, 0, 0)):
        o = " ".join(f(v) for v in offset)
        r = " ".join(f(v) for v in rotate)
        self.items.append(f'\t(model "{path}"\n\t\t(offset\n\t\t\t(xyz {o})\n\t\t)\n\t\t(scale\n'
                          f'\t\t\t(xyz 1 1 1)\n\t\t)\n\t\t(rotate\n\t\t\t(xyz {r})\n\t\t)\n\t)')

    def write(self):
        os.makedirs(LIB, exist_ok=True)
        head = (f'(footprint "{self.name}"\n\t(version 20241229)\n\t(generator "scsi_adapter_gen")\n'
                f'\t(generator_version "9.0")\n\t(layer "F.Cu")\n\t(descr "{self.descr}")\n\t(tags "{self.tags}")\n')
        body = "\n".join(self.items)
        path = os.path.join(LIB, self.name + ".kicad_mod")
        with open(path, "w") as fh:
            fh.write(head + body + f"\n\t(attr {self.attr})\n\t(embedded_fonts no)\n)\n")
        return path


def l_pad(sx, sy):
    """RPW0010A corner pad (1, 4, 7, 10) as an L, mirrored into the quadrant (sx, sy).
    Horizontal part x 0.60..1.20, y 0.55..0.85; tab x 0.60..0.85, y 0.85..1.20 (datasheet p.73)."""
    q = [(0.60, 0.55), (1.20, 0.55), (1.20, 0.85), (0.85, 0.85), (0.85, 1.20), (0.60, 1.20)]
    return [(sx * x, sy * y) for x, y in q]


def l_paste(sx, sy):
    """Stencil aperture for a corner pad (93 %): the same L with the tab trimmed to 0.225 wide (p.74)."""
    q = [(0.60, 0.55), (1.20, 0.55), (1.20, 0.85), (0.825, 0.85), (0.825, 1.20), (0.60, 1.20)]
    return [(sx * x, sy * y) for x, y in q]


def rpw0010a():
    """TI RPW0010A VQFN-HR-10, 2 x 2 mm (TPS25947, U101/U201).
    Source: TPS25947 datasheet SLVSFC9C, package pages 72-74 (4225183/A 08/2019). Pad edges were read
    from the drawing's vector outlines and match its dimensions (8X 0.6 long pads centred on 1.8,
    0.25 middle pads at +-0.225, 0.3 corner pads at 0.475 pitch, 2X 0.3 x 2.4 bars at +-0.25).
    Pads are NSMD, as TI recommends. Paste follows TI's 0.1 mm stencil: bars 5/6 split in two (82 %),
    corner pads 93 %, the rest 100 %."""
    fp = Footprint("Texas_RPW0010A_VQFN-HR-10_2x2mm_P0.45mm",
                   "TI RPW0010A VQFN-HR (HotRod) 10 pin, 2x2 mm, land pattern and stencil per TI 4225183/A "
                   "(TPS25947 datasheet SLVSFC9C p.72-74)",
                   "VQFN-HR HotRod RPW0010A TPS25947")
    fp.prop("Reference", "REF**", 0, -2.3, "F.SilkS")
    fp.prop("Value", fp.name, 0, 2.3, "F.Fab")
    fp.prop("Datasheet", "https://www.ti.com/lit/ds/symlink/tps25947.pdf", 0, 0, "F.Fab", hide=True)
    fp.prop("Description", "", 0, 0, "F.Fab", hide=True)
    # Pin 1 top-left, 1-4 down the left, 5/6 the bars (left, right), 7-10 up the right.
    # Side pads 2, 3, 8, 9: 0.6 x 0.25 centred on x = +-0.9, y = -+0.225; R0.05 corners.
    for num, sx, sy in (("2", -1, -1), ("3", -1, 1), ("8", 1, 1), ("9", 1, -1)):
        fp.smd(num, sx * 0.9, sy * 0.225, 0.6, 0.25, 0.05)
    # Corner L pads: copper and mask here, paste as separate apertures below.
    for num, sx, sy in (("1", -1, -1), ("4", -1, 1), ("7", 1, 1), ("10", 1, -1)):
        fp.custom(num, sx * 0.9, sy * 0.7, l_pad(sx, sy))
    # Bars 5 (IN side) and 6: 0.3 x 2.4 at x = -+0.25.
    for num, sx in (("5", -1), ("6", 1)):
        fp.smd(num, sx * 0.25, 0, 0.3, 2.4, 0.05, layers=("F.Cu", "F.Mask"))
    # Paste apertures (unnumbered, F.Paste only).
    for sx, sy in ((-1, -1), (-1, 1), (1, 1), (1, -1)):
        fp.custom("", sx * 0.9, sy * 0.7, l_paste(sx, sy), layers=("F.Paste",))
    for sx in (-1, 1):
        for sy in (-1, 1):   # each bar: two 0.28 x 1.06 apertures, y 0.10..1.16
            fp.smd("", sx * 0.25, sy * 0.63, 0.28, 1.06, 0.05, layers=("F.Paste",))
    # Fab: 2 x 2 body with a pin-1 chamfer.
    fp.poly("F.Fab", [(-0.5, -1), (1, -1), (1, 1), (-1, 1), (-1, -0.5)], 0.1, fill=False)
    fp.text("F.Fab", "${REFERENCE}", 0, 0, 0.5)
    # Silk: the pads reach +-1.2 on every side, so only a pin-1 arrow, 0.16 mm clear of pad 1 (JLC: 0.15).
    fp.poly("F.SilkS", [(-1.42, -0.70), (-1.72, -0.52), (-1.72, -0.88)], 0.12)
    # Courtyard: pads + 0.25.
    fp.rect("F.CrtYd", -1.45, -1.45, 1.45, 1.45, 0.05)
    # No RPW model in KiCad 9; RPU0010A has the same 2 x 2 x 1 body (pads drawn differently).
    fp.model("${KICAD9_3DMODEL_DIR}/Package_DFN_QFN.3dshapes/Texas_RPU0010A_VQFN-HR-10_2x2mm_P0.5mm.step")
    return fp.write()


def wj500v_2p():
    """Kangnex WJ500V-5.08-2P screw terminal (J101, LCSC C8465).
    Source: Kangnex drawing WJ500V-5.08-XXP-1Y-00A rev A (2024-03-10). Pitch 5.08; PCB hole 1.50; pins
    0.9 x 0.8 (1.2 across the diagonal, so KiCad's 1.3 mm Phoenix MKDS drill is too tight). Body: 10.00 deep,
    the pin row 4.50 from the back and 5.50 from the wire-entry face (third-angle side view); N x 5.08 wide,
    2.54 left of pin 1 and 3.14 right of the last pin, which includes a 0.6 interlocking tab. 14.07 tall.
    Wire entry faces +y, as in KiCad's terminal blocks."""
    fp = Footprint("TerminalBlock_Kangnex_WJ500V-5.08-2P_1x02_P5.08mm_Horizontal",
                   "Kangnex WJ500V-5.08-2P screw terminal, 2 pins, pitch 5.08mm, drill 1.5mm "
                   "(Kangnex drawing WJ500V-5.08-XXP-1Y-00A rev A)",
                   "screw terminal block Kangnex WJ500V 5.08mm")
    fp.attr = "through_hole"
    x0, x1, xt, yb, yf = -2.54, 7.62, 8.22, -4.5, 5.5     # body left/right, tab end, back, wire-entry face
    fp.prop("Reference", "REF**", 2.54, yb - 1.6, "F.SilkS")
    fp.prop("Value", fp.name, 2.54, yf + 1.8, "F.Fab")
    fp.prop("Datasheet", "https://www.lcsc.com/datasheet/C8465.pdf", 0, 0, "F.Fab", hide=True)
    fp.prop("Description", "", 0, 0, "F.Fab", hide=True)
    # Pads: 1.5 drill, 3.0 pad (0.75 annular ring: the screw torque loads these joints).
    fp.tht("1", 0, 0, 3.0, 1.5, "roundrect")
    fp.tht("2", 5.08, 0, 3.0, 1.5)
    # Fab: body, interlock tab, screw heads, wire-entry line.
    fp.poly("F.Fab", [(x0, yb), (x1, yb), (x1, yf), (x0 + 0.5, yf), (x0, yf - 0.5)], 0.1, fill=False)
    fp.rect("F.Fab", x1, yb + 1.0, xt, yb + 3.0, 0.1)
    for cx in (0, 5.08):
        fp.circle("F.Fab", cx, 0, 1.5, 0.1)
    fp.line("F.Fab", x0, yf - 1.5, x1, yf - 1.5, 0.1)
    fp.text("F.Fab", "${REFERENCE}", 2.54, -2.8, 1.0)
    # Silk: body outline 0.11 outside, wire-entry line, pin-1 arrow on the wire-entry face.
    o = 0.11
    fp.poly("F.SilkS", [(x0 - o, yb - o), (xt + o, yb - o), (xt + o, yf + o), (x0 - o, yf + o)], 0.12, fill=False)
    fp.line("F.SilkS", x0 - o, yf - 1.5, x1 + o, yf - 1.5, 0.12)
    fp.poly("F.SilkS", [(0, yf + o + 0.05), (0.45, yf + o + 0.65), (-0.45, yf + o + 0.65)], 0.12)
    # Courtyard: body + 0.5 (connector convention).
    fp.rect("F.CrtYd", x0 - 0.5, yb - 0.5, xt + 0.5, yf + 1.0, 0.05)
    # Nearest stock model: Phoenix MKDS 1,5/2-5,08 (body within about 1 mm). Re-check when the enclosure is drawn.
    fp.model("${KICAD9_3DMODEL_DIR}/TerminalBlock_Phoenix.3dshapes/"
             "TerminalBlock_Phoenix_MKDS-1,5-2-5.08_1x02_P5.08mm_Horizontal.step")
    return fp.write()


def te_amplimite_050_50pos_ra():
    """TE AMPLIMITE .050 Series III right-angle receptacle, 50 positions (J302 HD50): 5787082-5 (latch
    blocks + board locks). Same body and PCB pattern as 5787394-5 (no board locks) and 1761028-3 (rails),
    per catalog 82068 p.7 (E/F/G/K identical).
    Sources:
    - Application spec 114-40029 rev J, Fig. 12 (right-angle, 26/50 pos): contact holes 0.74-0.99 plated,
      4 rows 1.90 apart, 1.27 between positions, board-lock holes 2.77 +-0.05 at E = 46.48 on the row-B
      line, first position 8.00 from the left board lock, PCB edge 5.61 max in front of the board-lock line.
    - TE customer view model C-5787082-5 rev A (STEP): tail rows at 1.905 pitch, 13/12/13/12 tails at
      2.54 pitch with alternate rows offset 1.27, tails 0.305 x 0.406; board locks in line with row B; the
      shell's front flange hangs 0.81 below the board top, back to 5.89 in front of row B, so the edge
      must sit between 5.61 and 5.89 in front of row B; we use 5.61.
    Numbering (114-40029, from the component side, mating face up): position 1 is the rear row's first
    tail; 1-25 alternate rear row D (odd) / row C (even), 26-50 alternate row B (26, 28, ...) / front row A.
    Origin at pin 1; the mating face points to -y."""
    fp = Footprint("TE_AMPLIMITE-050_5787082-5_50pos_P1.27mm_Horizontal",
                   "TE AMPLIMITE .050 Series III right-angle receptacle, 50 pos (SCSI-2 HD50), 5787082-5 / 5787394-5 / "
                   "1761028-3; TE 114-40029 rev J Fig. 12 and customer view model C-5787082-5 rev A",
                   "TE AMPLIMITE 050 HD50 SCSI half-pitch receptacle right angle 5787082")
    fp.attr = "through_hole"
    P, R = 1.27, 1.905
    yD, yC, yB, yA = 0.0, -R, -2 * R, -3 * R
    for n in range(1, 51):
        if n <= 25:
            k = n - 1
            y = yD if k % 2 == 0 else yC
        else:
            k = n - 26
            y = yB if k % 2 == 0 else yA
        # 0.85 finished hole: middle of TE's 0.74-0.99 range, easy to seat 50 tails by hand.
        fp.tht(str(n), k * P, y, 1.3, 0.85, "roundrect" if n == 1 else "circle")
    cx = 12 * P                                       # connector centre line, x = 15.24
    for sx in (-1, 1):                                # board locks = shell, 2.77 plated, on the row-B line
        fp.npth_or_mp(cx + sx * 23.24, yB, 3.8, 2.77, "SH")
    edge = yB - 5.61                                  # PCB edge (max distance from TE)
    front = yB - (0.1016 + 11.684)                    # shell front face (model z = +0.10)
    rear = yB + (16.764 - 11.684)                     # bracket rear (model z = -16.76)
    half = 26.226                                     # G / 2
    fp.prop("Reference", "REF**", cx, rear + 1.6, "F.SilkS")
    fp.prop("Value", fp.name, cx, front - 1.4, "F.Fab")
    fp.prop("Datasheet", "https://www.te.com/usa-en/product-5787082-5.html", 0, 0, "F.Fab", hide=True)
    fp.prop("Description", "", 0, 0, "F.Fab", hide=True)
    # Fab: whole body (it overhangs the board edge), edge line, pin 1 marker.
    fp.rect("F.Fab", cx - half, front, cx + half, rear, 0.1)
    fp.line("F.Fab", cx - half, edge, cx + half, edge, 0.1)
    fp.text("F.Fab", "PCB edge", cx, edge + 0.9, 0.8)
    fp.text("F.Fab", "${REFERENCE}", cx, rear - 2.8, 1.0)
    fp.line("Dwgs.User", cx - half - 2, edge, cx + half + 2, edge, 0.1)
    fp.text("Dwgs.User", "Board edge here (TE: <= 5.61 from board-lock line)", cx, edge - 0.8, 0.6)
    # Silk: the on-board part of the body, open at the board edge; pin-1 arrow behind pad 1.
    o = 0.11
    fp.line("F.SilkS", cx - half - o, edge, cx - half - o, rear + o, 0.12)
    fp.line("F.SilkS", cx - half - o, rear + o, cx + half + o, rear + o, 0.12)
    fp.line("F.SilkS", cx + half + o, rear + o, cx + half + o, edge, 0.12)
    fp.poly("F.SilkS", [(0, rear + o + 0.2), (-0.45, rear + o + 0.8), (0.45, rear + o + 0.8)], 0.12)
    # Courtyard: whole body + 0.5, including the overhang past the board edge.
    fp.rect("F.CrtYd", cx - half - 0.5, front - 0.5, cx + half + 0.5, rear + 1.0, 0.05)
    # TE's STEP: +y up, +z toward the mating face, origin on the centre line at the front, seating plane
    # (bracket feet) at y = -4.343. Rotated so +z points along KiCad's 3D +y (the -y side of the footprint).
    fp.model("${KIPRJMOD}/scsi-adapter.3dshapes/TE_5787082-5.step",
             offset=(cx, -(yB - 11.684), 4.343), rotate=(-90, 0, 180))
    return fp.write()


def tf_push_shouhan():
    """SHOU HAN "TF PUSH" push-push microSD socket with card detect (J501, LCSC C393941).
    Source: SHOU HAN drawing TF PUSH rev A (2020-07-07), "Recommended P.C.B hole layout, component side
    view", tolerance +-0.05. Origin: the "connector center" line (x) and the peg-hole line (y).
    - Contacts Cd, 8 ... 1 (left to right): 0.70 x 1.60 at 1.10 pitch; Cd is 0.60 right of the left shell
      pads' inner edge, which is 2.20 left of the left peg; pad span y -11.80 .. -10.20 (10.20 from the pegs).
    - Pegs: 2 x NPTH 1.00 (pegs 0.80), 8.00 apart, the left one 4.95 left of the connector centre.
    - Shell pads: rear pair 1.50 tall, y -10.75 .. -9.25 (left 1.20 wide, right 1.60 wide, 3.00 right of the
      right peg); front pair 1.20 x 2.20, y -1.50 .. +0.70; left pads x -8.35 .. -7.15, front-right 12.10 right
      of the left peg. Checks: 9.95 (rear shell bottom to front shell bottom), 9.25, 10.20 all agree.
    - Body (top view): 14.75 x 14.50, centred on the connector centre, rear face 10.50 behind the pegs; the
      card slot is the +y face. Height 1.80-2.00.
    Pins: 1 DAT2, 2 CD/DAT3, 3 CMD, 4 VDD, 5 CLK, 6 VSS, 7 DAT0, 8 DAT1 (drawing table); Cd = 9 (DET) and
    the shell = 10 (SHIELD), as in KiCad's Micro_SD_Card_Det1. The Cd contact switches against the shell
    (the only other metal); polarity (closed with or without a card) isn't on the drawing."""
    fp = Footprint("microSD_SHOUHAN_TF-PUSH_PushPush_CardDetect",
                   "SHOU HAN TF PUSH push-push microSD socket with card detect (LCSC C393941); "
                   "SHOU HAN drawing TF PUSH rev A recommended PCB layout",
                   "micro SD TF card socket push-push card detect SHOUHAN C393941")
    xl_peg, xr_peg = -4.95, 3.05
    names = ["9", "8", "7", "6", "5", "4", "3", "2", "1"]        # Cd, 8 ... 1, left to right
    x_cd = xl_peg - 2.20 + 0.60
    for i, num in enumerate(names):
        fp.smd(num, x_cd + i * 1.10, -11.00, 0.70, 1.60)
    fp.smd("10", -7.75, -10.00, 1.20, 1.50)                     # rear-left shell
    fp.smd("10", xr_peg + 3.00 + 0.80, -10.00, 1.60, 1.50)      # rear-right shell (x 6.05 .. 7.65)
    fp.smd("10", -7.75, -0.40, 1.20, 2.20)                      # front-left shell
    fp.smd("10", xl_peg + 12.10 + 0.60, -0.40, 1.20, 2.20)      # front-right shell (x 7.15 .. 8.35)
    for x in (xl_peg, xr_peg):
        fp.npth(x, 0, 1.00)
    bx, by0, by1 = 7.375, -10.50, 4.00
    fp.prop("Reference", "REF**", 0, -13.2, "F.SilkS")
    fp.prop("Value", fp.name, 0, 7.4, "F.Fab")
    fp.prop("Datasheet", "https://www.lcsc.com/datasheet/C393941.pdf", 0, 0, "F.Fab", hide=True)
    fp.prop("Description", "", 0, 0, "F.Fab", hide=True)
    fp.rect("F.Fab", -bx, by0, bx, by1, 0.1)
    fp.text("F.Fab", "card slot", 0, by1 - 0.8, 0.8)
    fp.text("F.Fab", "${REFERENCE}", 0, -5, 1.0)
    # Silk: body sides between the shell pads (0.2 clear of copper), and the slot edge; pin-1 dot.
    o = 0.11
    fp.line("F.SilkS", -bx - o, -9.25 + 0.3, -bx - o, -1.50 - 0.3, 0.12)
    fp.line("F.SilkS", bx + o, -9.25 + 0.3, bx + o, -1.50 - 0.3, 0.12)
    fp.line("F.SilkS", -bx - o, 0.70 + 0.3, -bx - o, by1 + o, 0.12)
    fp.line("F.SilkS", bx + o, 0.70 + 0.3, bx + o, by1 + o, 0.12)
    fp.line("F.SilkS", -bx - o, by1 + o, bx + o, by1 + o, 0.12)
    fp.circle("F.SilkS", x_cd + 8 * 1.10 + 0.9, -12.3, 0.15, 0.3)   # next to pad 1
    fp.rect("F.CrtYd", -8.6, -12.05, 8.6, by1 + 0.5, 0.05)
    fp.line("Dwgs.User", -bx, by1, bx, by1, 0.1)
    fp.text("Dwgs.User", "Slot: put at the board edge; the card sticks out past it", 0, by1 + 1.2, 0.6)
    return fp.write()
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

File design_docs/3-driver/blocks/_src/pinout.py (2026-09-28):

# Page 5: RP2350B pin map. Rendered into ../5-rp2350-pinout.md by build.py.
# Physical pins: RP2350 datasheet §1.2.1, Figure 3 (QFN-80, top view).
from canvas import Diagram
D = Diagram()

# Package pin -> pad name, counter-clockwise from pin 1 (datasheet Figure 3).
PADS = {n: f"GPIO{g}" for n, g in zip(range(1, 5), range(4, 8))}
PADS.update({5: 'IOVDD', 6: 'GPIO8', 7: 'GPIO9', 8: 'GPIO10', 9: 'GPIO11', 10: 'DVDD',
             11: 'GPIO12', 12: 'GPIO13', 13: 'GPIO14', 14: 'GPIO15', 15: 'IOVDD',
             16: 'GPIO16', 17: 'GPIO17', 18: 'GPIO18', 19: 'GPIO19', 20: 'GPIO20',
             21: 'GPIO21', 22: 'GPIO22', 23: 'GPIO23', 24: 'IOVDD', 25: 'GPIO24',
             26: 'GPIO25', 27: 'GPIO26', 28: 'GPIO27', 29: 'IOVDD', 30: 'XIN', 31: 'XOUT',
             32: 'DVDD', 33: 'SWCLK', 34: 'SWDIO', 35: 'RUN', 36: 'GPIO28', 37: 'GPIO29',
             38: 'GPIO30', 39: 'GPIO31', 40: 'GPIO32',
             41: 'IOVDD', 42: 'GPIO33', 43: 'GPIO34', 44: 'GPIO35', 45: 'GPIO36',
             46: 'GPIO37', 47: 'GPIO38', 48: 'GPIO39', 49: 'GPIO40_ADC0', 50: 'IOVDD',
             51: 'DVDD', 52: 'GPIO41_ADC1', 53: 'GPIO42_ADC2', 54: 'GPIO43_ADC3',
             55: 'GPIO44_ADC4', 56: 'GPIO45_ADC5', 57: 'GPIO46_ADC6', 58: 'GPIO47_ADC7',
             59: 'ADC_AVDD', 60: 'IOVDD',
             61: 'VREG_AVDD', 62: 'VREG_PGND', 63: 'VREG_LX', 64: 'VREG_VIN', 65: 'VREG_FB',
             66: 'USB_DM', 67: 'USB_DP', 68: 'USB_OTP_VDD', 69: 'QSPI_IOVDD', 70: 'QSPI_SD3',
             71: 'QSPI_SCLK', 72: 'QSPI_SD0', 73: 'QSPI_SD2', 74: 'QSPI_SD1', 75: 'QSPI_SS',
             76: 'IOVDD', 77: 'GPIO0', 78: 'GPIO1', 79: 'GPIO2', 80: 'GPIO3'})

# What each GPIO carries (accepted 2026-09-25; review changes 2026-09-26: ATN on PIO0 out+9,
# GPIO 46 = TERMPWR ADC, CS1 pull-up 3.3k). Both SCSI blocks follow the SCSI-2 connector
# order (Table 2: DB0-7, DBP, ATN, BSY, ACK, RST, MSG, SEL, C/D, REQ, I/O). "in" = receiver output (INOVER: 1 = asserted),
# "gate" = FDV301N gate (1 = asserted).
DB = ['DB0', 'DB1', 'DB2', 'DB3', 'DB4', 'DB5', 'DB6', 'DB7', 'DBP']
GPIO = {}
for k, s in enumerate(DB):
    GPIO[k] = (f"{s} in", f"PIO0 in+{k}")
for k, s in enumerate(['ATN', 'BSY', 'ACK', 'RST', 'MSG', 'SEL', 'C/D', 'REQ', 'I/O'], start=9):
    GPIO[k] = (f"{s} in", f"PIO0 in+{k}")
for k, s in enumerate(DB):
    GPIO[18 + k] = (f"{s} gate", f"PIO0 out+{k}")
GPIO.update({
    27: ('ATN gate', 'PIO0 out+9'), 28: ('BSY gate', 'CPU'), 29: ('ACK gate', 'PIO0 side-set'),
    30: ('RST gate', 'CPU only'), 31: ('SEL gate', 'CPU'),
    # GPIO 32-46 order from the crossing-count solver (../tools/ft1248_pinsolve.py, 2026-09-27).
    32: ('LA marker 1', 'CPU'), 33: ('LA marker 0', 'CPU'),
    # Fallback (NOTES "FT1248 fallback plan"): move the 0R links and these pins become FT232H
    # FIFO / 8-bit FT1248 lines. FT pin numbers are FT232H package pins (DS v2.0).
    34: ('SD D0', '0R >> FIFO WR# (FT 27)'),
    35: ('FT MISO', 'PIO1; FIFO RD#'), 36: ('FT SS_n', 'PIO1; FIFO TXE#'),
    37: ('FT SCLK', 'PIO1; FIFO RXF#'),
    38: ('FT MIOSIO0', 'PIO1; FIFO D0'), 39: ('FT MIOSIO1', 'PIO1; FIFO D1'),
    40: ('FT MIOSIO2', 'PIO1; FIFO D2'), 41: ('FT MIOSIO3', 'PIO1; FIFO D3'),
    42: ('I2C1 SDA', '0R >> FIFO D4 (FT 17)'), 43: ('I2C1 SCL', '0R >> FIFO D5 (FT 18)'),
    44: ('SD CLK', '0R >> FIFO D6 (FT 19)'), 45: ('SD CMD', '0R >> FIFO D7 (FT 20)'),
    46: ('TERMPWR ADC', 'ADC6, 100k/100k'),
    47: ('PSRAM CS1', 'QMI, 3.3k up'),
})
OTHER = {
    'IOVDD': '3.3 V', 'DVDD': '1.1 V core', 'ADC_AVDD': '3.3 V', 'USB_OTP_VDD': '3.3 V',
    'QSPI_IOVDD': '3.3 V', 'XIN': '12 MHz crystal', 'XOUT': '12 MHz crystal',
    'SWCLK': 'TC2030 pad 4', 'SWDIO': 'TC2030 pad 2', 'RUN': 'RUN btn; TC2030 pad 3',
    'VREG_AVDD': 'core reg (33R+4u7)', 'VREG_PGND': 'core reg GND', 'VREG_LX': 'core reg L',
    'VREG_VIN': 'core reg 3.3 V in', 'VREG_FB': 'core reg -> DVDD',
    'USB_DM': 'hub port 2 D-', 'USB_DP': 'hub port 2 D+',
    'QSPI_SS': 'flash CS, BOOTSEL', 'QSPI_SCLK': 'flash + PSRAM',
    'QSPI_SD0': 'flash + PSRAM', 'QSPI_SD1': 'flash + PSRAM',
    'QSPI_SD2': 'flash + PSRAM', 'QSPI_SD3': 'flash + PSRAM',
}

pins = {}
for num, pad in PADS.items():
    if pad.startswith('GPIO'):
        g = int(pad[4:].split('_')[0])
        sig, owner = GPIO[g]
        pins[num] = (pad, f"{sig:<11} {owner}")
    else:
        pins[num] = (pad, OTHER[pad])

D.chip45('rp', 0, 0, 20, pins, name='RP2350B',
         inner=["RP2350B", "QFN-80, top view", "", "rotated 45 deg CCW:", "package top edge",
                "faces upper-left", "", "* = pin 1", "EP (81) = GND"])

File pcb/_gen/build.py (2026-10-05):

"""Regenerate the generated schematic sheets and verify them.

    python3 pcb/_gen/build.py            # regenerate every sheet, then ERC + netlist check
    python3 pcb/_gen/build.py --check    # don't write anything; check the files on disk
    python3 pcb/_gen/build.py --force    # overwrite even if a sheet was edited by hand in KiCad

build.py records a content fingerprint of every sheet it writes (fingerprints.json). If a sheet on
disk no longer matches its fingerprint, someone edited it in KiCad: build.py lists the differences and
writes nothing. Fold the edits into the sheet script (texts can go anywhere nearby), then run again.

A sheet whose content on disk already equals the script's output is never rewritten: its fingerprint is
just recorded. So once the edits are folded in, the file KiCad saved stays as it is (same UUIDs, so the
PCB's links to its symbols survive), and it is safe to run with the schematic open.
"""
import importlib, json, os, subprocess, sys, tempfile

HERE = os.path.dirname(os.path.abspath(__file__))
PCB = os.path.dirname(HERE)
sys.path.insert(0, HERE)
from netcheck import netcheck
from semdiff import semdiff, fingerprint

SHEETS = ["sheet_1_power", "sheet_2_termpwr", "sheet_3_scsi", "sheet_4_rp2350", "sheet_5_io", "sheet_6_usb_hub", "sheet_7_ft232h"]
CLI = os.environ.get("KICAD_CLI", "/Applications/KiCad/KiCad.app/Contents/MacOS/kicad-cli")
ROOT_SCH = os.path.join(PCB, "scsi-adapter.kicad_sch")
FINGERPRINTS = os.path.join(HERE, "fingerprints.json")   # content hash of each sheet as last written


def kicad(*args):
    r = subprocess.run([CLI, *args], capture_output=True, text=True)
    if r.returncode != 0:
        sys.exit(f"kicad-cli {' '.join(args)} failed:\n{r.stdout}{r.stderr}")


def main():
    check_only, force = "--check" in sys.argv, "--force" in sys.argv
    tmp = tempfile.mkdtemp()
    last = json.load(open(FINGERPRINTS)) if os.path.exists(FINGERPRINTS) else {}
    intended, pending, edited = {}, [], False
    for name in SHEETS:                       # generate and compare everything before writing anything
        mod = importlib.import_module(name)
        files = getattr(mod, "FILES", None)
        if files:                               # a module that writes several sheet files
            fresh = {f: os.path.join(tmp, f) for f in files}
            intended[name] = mod.build(fresh)
        else:
            files = [mod.FILE]
            fresh = {mod.FILE: os.path.join(tmp, mod.FILE)}
            intended[name] = mod.build(fresh[mod.FILE])
        for file in files:
            on_disk = os.path.join(PCB, file)
            exists = os.path.exists(on_disk)
            # hand-edited = the file on disk no longer matches what build.py last wrote
            hand_edited = exists and file in last and fingerprint(on_disk) != last[file]
            changed = exists and fingerprint(on_disk) != fingerprint(fresh[file])
            if check_only:
                state = "hand-edited since last build" if hand_edited else "matches last build"
                print(f"{file}: {state}; {'script output differs' if changed else 'script output identical'}")
            elif not changed:                   # disk already equals the script output: adopt, don't rewrite
                last[file] = fingerprint(on_disk)
                print(f"{file}: matches the script" + (" (hand edits folded in)" if hand_edited else ""))
                continue
            elif hand_edited and not force:
                print(f"{file} was edited in KiCad since the last build. Differences from the new script output")
                print("(your edits, plus any script changes). Fold the edits into " + name + ".py, or use --force:")
                for d in semdiff(on_disk, fresh[file]):
                    print("   ", *d)
                edited = True
            pending.append((fresh[file], on_disk, file))
    if edited:
        sys.exit("Nothing written.")
    if not check_only:
        for fresh, on_disk, file in pending:
            os.replace(fresh, on_disk)
            last[file] = fingerprint(on_disk)
            print(f"{file}: written")
        json.dump(last, open(FINGERPRINTS, "w"), indent=1, sort_keys=True)
    erc = os.path.join(tmp, "erc.rpt")
    kicad("sch", "erc", "--severity-all", "-o", erc, ROOT_SCH)
    rpt = open(erc).read()
    sheet_names = {"sheet_1_power": ["power"], "sheet_2_termpwr": ["termpwr"],
                   "sheet_4_rp2350": ["rp2350"], "sheet_5_io": ["io"], "sheet_6_usb_hub": ["usb-hub"], "sheet_7_ft232h": ["ft232h"], "sheet_3_scsi": ["scsi"] + [f"scsi/{n}" for n in importlib.import_module("sheet_3_scsi").PAGE]}
    for name in SHEETS:
        items = []
        for sheet in sheet_names[name]:
            sect = rpt.split(f"***** Sheet /{sheet}/")[1].split("***** Sheet")[0] if f"/{sheet}/" in rpt else ""
            items += [f"/{sheet}/: " + l for l in sect.splitlines() if l.startswith("[")]
        print(f"ERC {name}: {len(items)} item(s)")
        for l in items[:40]:
            print("   ", l)
    net = os.path.join(tmp, "net.net")
    kicad("sch", "export", "netlist", "--format", "kicadsexpr", "-o", net, ROOT_SCH)
    bad = 0
    for name, want in intended.items():
        problems = netcheck(net, want)
        bad += len(problems)
        print(f"netlist {name}: {len({r for r, _ in want})} parts, {len(problems)} problem(s)")
        for p in problems:
            print("   ", p)
    sys.exit(1 if bad else 0)


if __name__ == "__main__":
    main()

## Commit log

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2026-09-24 Phase 3: RP2350B support parts and one crystal type
    Reuse part numbers (not schematics) from scanlight sl_v4 for the crystal
    circuit and USB series resistors; swap the 27 ohm to a no-fee 0603 part.
    Buttons deferred to the owner's through-hole stock. The CH334's ~16 pF
    internal load caps suit the ABM8-272-T3, so both chips share it.
    Claude-Session: https://claude.ai/code/session_01M8pTzBbKH3bhUYnBDVTw88
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2026-09-24 Phase 3: FT1248 rework fallback and pin-plan rules
    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
2026-09-25 Phase 3: SCSI drivers are 14 x FDV301N; LVTH125 fallback
    Open-drain on every driven line. Meets V_OL <= 0.5 V at 48 mA hot, and
    the RP2350's reset pull-downs keep the lines released. Pin sharing and a
    serial input expander were rejected, so it stays 32 dedicated GPIO.
    Capacitance budget corrected: the terminator is excluded per 5.4.
    [scsi.py]
2026-09-25 Phase 3: SCSI receivers are 18 x Nexperia 74LVC1G17GW
    One Schmitt buffer per line, clustered with its driver. I_OFF is
    specified, so an unpowered board stays off the bus (R2); thresholds
    guaranteed at 3.0 V and interpolated at 3.3 V. Fallback is 3 x Nexperia
    74LVC14APW. TI's LVC14A and Nexperia's 2G17/3G17 fail the SCSI-2
    thresholds, so the BOM names the vendor.
    Claude-Session: https://claude.ai/code/session_01FEHXzVMZEznN6FVgMmXC1V
    [scsi.py]
2026-09-25 Phase 3: LA header taps receivers through 100 ohm series resistors
    The 74LVC1G17 receivers already are the Schmitt buffers R4a asks for,
    so no second bank. 100 ohm limits a shorted probe to 33 mA and damps
    ringing on the LA lead. Closes the front-end open question.
    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
    [scsi.py]
2026-09-26 Phase 3: RP2350B pin map, expander pinout, debug, resistor values
    - Page 5 pin map (chip45 diamond view, every package pin) and the
    TCA9555 pinout (chip2); SCSI GPIO blocks in SCSI-2 connector order,
    ATN/BSY/SEL on the CPU, RST CPU-only, FT1248 0 ohm rework links.
    - Gate pull-downs 4.7k: RP2350-E9 leakage needs <= 8.2k.
    - Debug: Tag-Connect TC2030-IDC pads + J-Link EDU (ARM20-CTX).
    - All resistor values set. CC reference is now a CJ431 with a 10k/1uF
    filter (rail-derived reference failed worst case; LM393 bias current
    through 100k was a 25 mV error). TERMPWR enable node pulled to 3.3 V.
    3.3 V LDO divider 1 %. R_ILM 2.4k + 330 replaces the extended 2.74k.
    Claude-Session: https://cl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
    [build.py, canvas.py, expander.py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]
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2026-09-26 Phase 3: design review and applied fixes
    Full design review (docs/design-review-2026-09-26.md, 113 findings, no
    blockers) with a local triage page (docs/design-review.html). The owner
    triaged every finding; the approved fixes are applied:
    - U1 LM66200 -> TPS2116 priority mux (bench first), VBUS snubber
    - Bench eFuse: OVLO 5.35 V, EN Zener, ILIM 2.22 A, 50 V input cap
    - TERMPWR: OVLO divider, sense on GPIO 46 ADC, LED 10k
    - Terminator: 2.83 V + 270R bleed, 2 x 220R per line (basic)
    - FT232H per DS Fig. 6.2 with support parts; 33R on FT1248
    - CH334 reset via Schottky, PSRAM CS1 3.3k, 4th DVDD cap, ATN on PIO0
    - PIO sketch rewritten, firmware rules, power budget, parts list,
    USAGE (power, fi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
    [bom-estimate.csv]
2026-09-26 Move phase folders into design_docs/
    Update every path that referenced 1-bus-capture/, 2-reverse-engineering/,
    3-driver/ and 4-software/.
    [bom-estimate.csv]
2026-09-26 Phase 3: start KiCad project with JLC 4-layer stackup and rules
    Blank KiCad 9-format project in pcb/. Stackup JLC04161H-7628 (standard,
    1.6 mm), Board Setup minimums from JLC's 4-layer capabilities, a custom
    .kicad_dru for the rules Board Setup can't express, and a USB_HS net
    class (0.29 mm / 0.20 mm, 90 ohm differential on L1 over L2).
    [scsi-adapter.kicad_pcb, scsi-adapter.kicad_sch]
2026-09-26 Phase 3: schematic hierarchy with empty sheets and inter-sheet nets
    Root block diagram, seven A3 functional sheets, and two SCSI channel
    sheet files repeated 14x (bidirectional) and 4x (receive-only).
    USB_HS net-class patterns for the upstream and FT232H pairs.
    [1-power.kicad_sch, 2-termpwr.kicad_sch, 3-scsi.kicad_sch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]
2026-09-26 Phase 3: populate power sheet; descriptive net names
    Power sheet: bench eFuse (TPS259470A) with UVLO/OVLO string and EN
    clamp, TPS2116 bench-priority mux with VBUS snubber, 3.3 V and 2.83 V
    TPS73701 LDOs. Notes on the string's tap voltages, eFuse setting pins
    and every DNP part. Project symbol library with the TPS259470A and
    TPS73701DCQ drawn from the datasheet pin tables.
    Nets renamed to spelled-out names (IS_BENCH_POWERED, *_INVERTED for
    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
    [1-power.kicad_sch, 2-termpwr.kicad_sch, 3-scsi.kicad_sch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]
2026-09-27 Phase 3: populate TERMPWR sheet; schematic generator in pcb/_gen
    TERMPWR sheet: CC detection (LM393 against a CJ431 2.5 V shunt
    reference divided to 0.653 V, with hysteresis), the active-low
    TERMPWR enable node (comparators wired-OR with the bench-present
    FET), and the TERMPWR eFuse with its OVLO-as-enable divider, jumper,
    TVS and indicator LEDs. Includes the owner's CJ431 and PWR_FLAG notes.
    pcb/_gen regenerates the generated sheets and checks them against
    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
    [1-power.kicad_sch, 2-termpwr.kicad_sch, 3-scsi.kicad_sch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]
2026-09-27 Phase 3: populate SCSI sheet and channel sheets
    SCSI sheet (A2): IDC50 and HD50 wired by signal name from SCSI-2
    Table 2, all four RESERVED lines grounded through 0R links, the
    logic-analyzer header as a pin-for-pin copy of the Digital Discovery
    DIN connector, three SN74LVTH245A terminators with their DIP-switch
    enable and truth table, and one cluster per line: 2 x 220R terminator
    pair, ESD diode and channel sheet. Channel sheets hold the FDV301N
    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
    [1-power.kicad_sch, 2-termpwr.kicad_sch, 3-scsi.kicad_sch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]
2026-09-27 Phase 3: populate RP2350 sheet; FT_* nets renamed FT232H_*
    RP2350 sheet (A2): RP2350B with every pin labelled by function and the
    FT1248, marker and USB series resistors inline on their pins; core
    regulator, per-pin decoupling (14 x 100 nF, count corrected), crystal,
    QSPI flash and PSRAM in separate boxes, TC2030 debug pads and buttons,
    the FT1248 rework links, and the TERMPWR sense divider on ADC6.
    Generator: recursive derived-symbol flattening, small field fonts.
    [4-rp2350.kicad_sch, 7-ft232h.kicad_sch, scsi-adapter.kicad_sch]
2026-09-27 Phase 3: populate io sheet
    TCA9555 expander (0x20) with I2C pull-ups and a pin table, five LEDs
    (status yellow, activity red, spare red/yellow/green on P05-P07; the
    green gets 470R), microSD socket with SDIO pull-ups, and test pads for
    the rails, TERMPWR_EN, the expander INT and spare pins P15-P17.
    Generator: inline power symbols for dense connectors (the netlist
    check caught a rail dogleg shorting SD_CMD and SD_D0).
    [5-io.kicad_sch]
2026-09-27 Phase 3: populate USB-C and hub sheet
    USB-C receptacle (both D+/D- pins tied, 5.1k Rd on CC, shell through
    0R), ESD on D+/D-, CC and VBUS, and the CH334P hub (new project
    symbol from the English datasheet) in external 3.3 V mode: port 1 to
    the FT232H, port 2 to the RP2350, reset through a Schottky, crystal
    with unfitted load-cap pads, and a "hub active" LED on PGANG.
    Net-class patterns simplified to *USB_D+/- and *USB_FT_D+/-:
    kicad-cli's netlist only applies patterns to root-level hierarchical
    nets, but pcbnew resolves these correctly (checked with its Python API).
    [6-usb-hub.kicad_sch]
2026-09-27 Phase 3: populate FT232H sheet; FT232H_WR_N -> FT232H_WRITE_INVERTED
    FT232HL per DS Fig. 6.2 (VCCD makes FT232H_3V3), ferrite-fed VPHY/VPLL,
    93LC56B config EEPROM, crystal, REF, RESET RC and FIFO-fallback pull-ups.
    Project FT232H symbol retypes EECS/EECLK as outputs (and VCCD as
    power_out); upstream fix recorded as a follow-up (NOTES open question 14).
    [4-rp2350.kicad_sch, 7-ft232h.kicad_sch, scsi-adapter.kicad_sch]
2026-09-27 Phase 3: footprint audit fixes and project footprint library
    - New project footprint library pcb/scsi-adapter.pretty, generated by
    pcb/_gen/footprints.py from datasheet land patterns: TI RPW0010A (U101/U201),
    Kangnex WJ500V (J101), TE AMPLIMITE .050 HD50 (J302), SHOU HAN TF PUSH
    microSD (J501), Abracon AOTA-B201610 polarized inductor (L401), SHOU HAN
    2-pos DIP (SW301). fp-lib-table added.
    - J303 LA header: 2x17 box header C20920, pins 33/34 NC (34-way ribbon to a
    future 2x16 adapter board).
    - J302 HD50: TE 5787082-5 squeeze-latch receptacle; shielded symbol, shell to
    GND via R343 0R. TE STEP model git-ignored (pcb/scsi-adapter.3dshapes/).
    - D101/D204/D605: D_SMF -> D_SOD-123F (pa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
    [1-power.kicad_sch, 2-termpwr.kicad_sch, 3-scsi.kicad_sch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]
2026-09-27 basic pcb layout
    [4-rp2350.kicad_sch, scsi-adapter.kicad_pcb]
2026-09-28 pin reassignments
    [4-rp2350.kicad_sch]
2026-09-28 start routing ft232h
    [4-rp2350.kicad_sch, scsi-adapter.kicad_pcb]
2026-09-28 L3 power pours
    [scsi-adapter.kicad_pcb]
2026-09-28 ft232h passives routing
    [scsi-adapter.kicad_pcb]
2026-10-03 ft232h fully routed
    [scsi-adapter.kicad_pcb]
2026-10-03 start routing scsi
    [scsi-adapter.kicad_pcb]
2026-10-03 signal cluster trios
    [scsi-adapter.kicad_pcb]
2026-10-03 more signal clustering
    [scsi-adapter.kicad_pcb]
2026-10-03 route more scsi traces
    [1-power.kicad_sch, 2-termpwr.kicad_sch, 3-scsi.kicad_sch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]
2026-10-03 scsi finished routing to idc50
    [scsi-adapter.kicad_pcb]
2026-10-03 route logic analyzer and bus crystal
    [3-scsi.kicad_sch, scsi-adapter.kicad_pcb]
2026-10-03 good chunk of power routing
    [1-power.kicad_sch, scsi-adapter.kicad_pcb]
2026-10-03 route termpwr
    [5-io.kicad_sch, scsi-adapter.kicad_pcb]
2026-10-04 more routing, mostly around the i2c expander and LEDs
    [5-io.kicad_sch, scsi-adapter.kicad_pcb]
2026-10-04 most of the passives laid out and routed
    [scsi-adapter.kicad_pcb]
2026-10-04 done for the night
    [scsi-adapter.kicad_pcb]
2026-10-04 route hd50
    [scsi-adapter.kicad_pcb]
2026-10-04 almost completely routed
    [3-scsi.kicad_sch, scsi-adapter.kicad_pcb]
2026-10-04 all routed
    [5-io.kicad_sch, scsi-adapter.kicad_pcb]
2026-10-04 DRC fixes minus silkscreen
    [scsi-adapter.kicad_pcb]
2026-10-04 clean up silkscreen
    [scsi-adapter.kicad_pcb]
2026-10-05 widen power traces
    [scsi-adapter.kicad_pcb]
2026-10-05 reroute USB lines
    [scsi-adapter.kicad_pcb]
2026-10-05 more manual iteration
    [scsi-adapter.kicad_pcb]
2026-10-05 thermal pours for LDOs
    [scsi-adapter.kicad_pcb]
2026-10-05 update docs
    [scsi-adapter.kicad_pcb]
2026-10-05 reorder passives near ft232h
    [3-scsi.kicad_sch, 5-io.kicad_sch, scsi-adapter.kicad_pcb]
2026-10-05 sch update
    [1-power.kicad_sch, 3-scsi.kicad_sch]
2026-10-05 pcb updates
    [scsi-adapter.kicad_pcb]
2026-10-05 semi-final silkscreen pass
    [scsi-adapter.kicad_pcb]
2026-10-05 rev 1
    [scsi-adapter.kicad_pcb]
2026-10-05 JLC text
    [scsi-adapter.kicad_pcb]
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2026-10-13 FT1248 bench: serial-node stall traced to the macOS serial stack
2026-10-14 JLC order export script and first file set; C305 clearance fix
    tools/jlc_export.py builds the Gerber/drill zip, BOM and CPL into pcb/fab from a
    zone-refilled temp copy, and refuses to export if DRC or the BOM cross-checks fail.
    The PCB change is the owner's zone refill and the clearance fix at C305 pad 1.
    pcb/fab still lists C11616 for R101 (10 in stock at JLC); it is replaced next.
2026-10-14 Swap ten preferred parts for basic ones; regenerate JLC order files
    R101 510k becomes 0603 C23192 (the 0402 C11616 ran out at JLC). Nine more
    preferred lines are replaced so JLC's BOM tool lists them as basic:
    - same-ratio pairs: LDO EN dividers 20k/15k, TPS2116 PR1 51k/20k
    - re-valued pairs: bench string R2 33k + 10k, TERMPWR R_ILM 2.2k + 510R (1.23 A),
    TERMPWR UVLO 51k/20k (4.26 V), 3.3 V LDO R2 = 33k || 150k on the former trim pad R115
    - 0603 for the same value: R104, R118, R119, R215, C103, C204
    Sheets, generator scripts, PCB (owner's re-layout, silkscreen stripped from the new
    0603 parts, fields synced), docs and pcb/fab are updated. DRC clean on the saved board.
2026-10-14 JLC placement corrections from the preview; final fab files
    tools/jlc_export.py now applies rotation corrections per C-number (16 parts: SOT-23,
    SOT-353, SOT-23-6, L401 and the TPS259470A at +180; SOT-223-6, TSSOP, SOIC, QFN-16
    and SOT-583 parts at +270) and shifts the microSD socket J501 by 5.5 mm to JLC's part
    origin. All were checked by the owner in JLC's placement preview over three rounds.
    PCB: owner's LED nudges; silkscreen outlines removed from C114 and C304-C308.

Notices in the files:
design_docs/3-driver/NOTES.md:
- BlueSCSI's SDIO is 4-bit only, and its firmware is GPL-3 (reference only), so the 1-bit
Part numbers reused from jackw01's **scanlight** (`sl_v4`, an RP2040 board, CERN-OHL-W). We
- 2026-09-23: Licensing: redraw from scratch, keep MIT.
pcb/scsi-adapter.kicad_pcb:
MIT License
